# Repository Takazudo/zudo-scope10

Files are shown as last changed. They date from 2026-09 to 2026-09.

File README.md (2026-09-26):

# zudo-scope10 — P0 pre-layout handoff

Ten DC-coupled inputs, one portrait 3.5-inch LCD, ten TIME pots and ten RANGE switches.
All soldering is assigned to factory assembly. Pico H and Waveshare SKU 19907 are preassembled plug-in modules.

**This is the waveform-monitor project, not the LED lamp or the five-oscillator instrument.**

**NOT FOR FABRICATION.** The PCB contains only an outline. Native KiCad *placement/routing*, exact physical footprints, display power strap resolution, bench-measured acquisition/protection/power qualification, sourcing, assembly and release approval remain open — every one of the ten release gates (G01–G10) in `design/release-gates.json` stays OPEN, each with partial desk evidence.

Start with [START_HERE.md](START_HERE.md) for orientation, or go straight to **[LOCAL-HANDOFF.md](LOCAL-HANDOFF.md)** for the numbered local procedure covering every gate plus the assembler review and the factory-assembled prototype (no home soldering). The entry point `index.html` opens the offline catalogue and UI simulator. Run:

```sh
python3 scripts/validate.py
python3 scripts/test_firmware.py
python3 scripts/serve.py
```

Browse `http://127.0.0.1:8000/`.

| Directory | Purpose |
|---|---|
| `design/` | Requirements, circuit pin/net graph, GPIO, narratives, release gates |
| `hardware/kicad/` | Eleven generated native schematic drafts, netlist, outline-only PCB |
| `hardware/libraries/` | Embedded review symbol library and one drawing-derived button footprint |
| `catalog/` | Component and source evidence; unknown identities are explicit |
| `doc/` | zudo-doc configuration, generated MDX and public previews |
| `firmware/` | Host-tested portable core, diagnostic + 10 kS/s/ch acquisition targets, clean-room LCD backend — all build clean against the real Pico SDK (no hardware bring-up yet) |
| `reference/` | Retained original ALPS/button/jack assets with provenance |
| `mechanical/` | Ergonomic panel and nominal envelopes, not manufacturing CAD |
| `manufacturing/` | Planning BOM, RFQ, acceptance worksheet, blocking release guard |
| `reports/` | Reproducible analytical and validation reports, not bench measurements |

No Gerber or placement file is emitted. Do not order the outline-only board. No online repo, vendor account or purchase was modified.

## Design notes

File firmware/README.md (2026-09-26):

# Firmware status

The portable core is host-tested. `scope10_diagnostic` is target source for a slow USB CSV input/control diagnostic with the LCD held dark. It is **not the complete monitor firmware**. No high-rate acquisition guarantee or working LCD is claimed. A clean-room LCD backend and ten-pane renderer exist but are compiled only with `-DSCOPE_ENABLE_LCD=1` and are not hardware-verified; see `LCD-BACKEND.md` (G06 OPEN).

Run `python3 scripts/test_firmware.py` from the repository root for host tests. Use `PICO_SDK_PATH` and the CMake instructions in the documentation for local target compilation. The Waveshare backend behind `src/display_port.h` is a clean-room implementation because the vendor driver carries no licence (`LCD-BACKEND.md`); validate the module power/interface (G01) before enabling it.

Do not link an empty successful LCD stub, allocate a full RGB565 framebuffer, auto-zero connected inputs at boot, or suppress acquisition overruns.

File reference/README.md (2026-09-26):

# Source availability and rights

`catalog/sources.json` records current primary-source URLs and the nature of each review. Some PDFs were read through the web tool but could not be downloaded as bytes. The binary-fetch script is provided for local completion; it checks magic bytes and records hashes, but does not mark downloaded content electrically reviewed.

`assets/` contains existing manufacturer/supplier files recovered from the user's earlier component catalogue ZIP. Their records retain the original URLs and SHA-256 values. These third-party source assets are not licensed under the license for the newly written project code. Keep them for local engineering reference; review their respective terms before publishing download mirrors.

The ALPS STEP is original manufacturer geometry. No exact Waveshare/Pico or NKK STEP is included. The separately generated nominal envelopes are clearly different artifacts and do not replace missing exact CAD.

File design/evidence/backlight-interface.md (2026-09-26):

# GP13 backlight interface: open-drain stage, voltage table and alternatives (#41, source #19)

Status: **design applied, bench check pending**. G01 and G06 stay OPEN. Everything here is a desk analysis of the carrier netlist (`design/circuit.json`, generated by `scripts/make_design.py`), the Waveshare module schematic and the RP2040 datasheet. No node has been measured; the module revision and population have not been inspected.

## Problem being solved

The module's R16 (10 kΩ) runs from VSYS to `LCD_BL`, which is pin 3 (EN) of CAT1, the backlight regulator (Waveshare Pico-ResTouch-LCD-3.5 schematic p1, "LCD BACKLIGHT", grid 3A; re-read from the PDF at 300 dpi on 2026-09-26, SHA-256 `0547c5fd3dc4fce9e20941b756aa8e348ea47e4d24851e745a04a0c24a5f3b41`, same file as `display-sch` in `g01-display-power.md`). On the carrier VSYS is `+5V_FUSED`, i.e. USB 4.75–5.25 V less the F1 drop. Before #41 the carrier tied GP13 (through R64 33 Ω) directly to `LCD_BL` with R88 100 kΩ to GND, so an undriven GP13 sat near 4.5 V (about 3.85–4.08 V including the RP2040's 50–80 kΩ reset pull-down). That exceeds the RP2040 absolute maximum VPIN ≤ IOVDD + 0.5 V (RP2040 datasheet §5.5.3.1, Table 622) in every state where firmware does not drive the pin. The earlier G01 handoff options, "remove R88" and "accept an estimated < 0.1 mA clamp", are both rejected: removing R88 moves the unloaded node toward 5 V, and the fault-tolerant IO definition does not establish 5 V operation or a usable clamp (#19).

## Decision: N-channel open-drain stage on the carrier

Chosen over the alternatives below because it changes nothing on the module, needs no home soldering, is threshold-agnostic for "off", and keeps the GPIO pad inside its own supply rails by construction rather than by firmware timing.

```text
GP13 (J20-17, net LCD_BL_SRC) --R64 33R-- LCD_BL_GATE --+-- Q1 gate
                                                        |
                                                   R88 100k
                                                        |
                                                       GND
Q1 drain  -- LCD_BL (J30-17) -- module R16 10k -- VSYS ; -- CAT1 EN
Q1 source -- GND
```

- `Q1` is a new generic catalog record `nmos-ll` (logic-level N-channel MOSFET; no MPN, LCSC code or footprint; requirements listed on the record, exact part at G08).
- `R64` keeps its value and its GP13 side; its other side moves from `LCD_BL` to the new net `LCD_BL_GATE`.
- `R88` keeps its value and footprint and becomes the gate pull-down (`LCD_BL_GATE` → GND).
- `J30`/`J31` header nets are unchanged: position 17 is still `LCD_BL`. Module R16 remains the only pull-up on that node.
- `scripts/validate_extra.py` (`_gp13_backlight_interface`) asserts that GP13's net has no resistive DC path below 1 MΩ to `+5V_FUSED`, `VBUS_USB` or `LCD_BL`, that the GP13 and gate nets contain exactly the parts above, and that the display header map is unchanged.

### Default state and enable polarity (explicit)

| GP13 | Q1 | `LCD_BL` | Backlight |
|---|---|---|---|
| undriven (reset, BOOTSEL/ROM, before the firmware hook) | off (gate held at 0 V by R88) | VSYS via R16 | **ON** |
| driven low | off | VSYS via R16 | ON |
| driven high | on | ≈ 0 V | **OFF** |

The backlight is **default ON** and the GPIO control is **active-low** (GP13 high = off). Any future PWM dimming is inverted as well. Firmware is updated accordingly (`firmware/src/lcd_safe_pins.[ch]`, `firmware/src/display_waveshare.c`): `scope10_acq` drives GP13 high from its early runtime-init hook in both `SCOPE_ENABLE_LCD` states, and the LCD-enabled build drives it low only after a successful panel init. `scope10_diagnostic` does not link `lcd_safe_pins.c` and never drives GP13, so under the diagnostic firmware the backlight stays ON; the pad still sits at 0 V through R88.

## Voltage/current table

Conventions: IOVDD = 3.3 V nominal (Pico 3V3). "Pad" is the GP13 pad = net `LCD_BL_SRC`; "gate" is net `LCD_BL_GATE`; `LCD_BL` is the module node. V_OH/V_OL are the RP2040 output levels at IOVDD 3.3 V; the RP2040 reset pull-down is the 50–80 kΩ figure cited in #19. The Q1 numbers use the record's requirements (Igss ≤ 1 µA, Rds(on) ≤ 10 Ω at Vgs = 2.5 V); they become datasheet numbers only once a part is selected at G08. **No entry depends on any GPIO protection clamp or on the fault-tolerant IO definition.**

| State | Pad (GP13) | Gate | `LCD_BL` | Current into/out of pad | Backlight |
|---|---|---|---|---|---|
| USB 4.75 V, GP13 undriven | 0 V (R88 ‖ 50–80 kΩ to GND; Igss ≤ 1 µA × 100 kΩ ≤ 0.1 V worst case) | same as pad | 4.75 V − F1 drop (Q1 off; CAT1 EN input current unknown) | ≤ 1 µA (gate leakage only) | ON |
| USB 5.25 V, GP13 undriven | 0 V (as above) | same as pad | 5.25 V − F1 drop | ≤ 1 µA | ON |
| USB 4.75–5.25 V, GP13 driven low | V_OL ≈ 0 V | ≈ 0 V | VSYS via R16 | ≈ 0 (R88 draws nothing at 0 V) | ON |
| USB 4.75–5.25 V, GP13 driven high | V_OH ≤ IOVDD | V_OH − 33 Ω × (33 µA + Igss) ≈ V_OH | Rds(on) × (VSYS / 10 kΩ) ≤ 10 Ω × 0.53 mA ≈ 5 mV | 33 µA (R88) + Igss, sourced by the pad | OFF |
| Reset (RUN low or power-on reset) | 0 V (reset pull-down 50–80 kΩ plus R88, both to GND) | 0 V | VSYS via R16 | ≤ 1 µA | ON |
| BOOTSEL / boot ROM | expected 0 V (pad left in its reset state); if the ROM ever drove GP13 it could only reach V_OH ≤ IOVDD | follows pad | VSYS via R16 (or ≈ 0 V if driven high) | ≤ 1 µA (or 33 µA) | expected ON; confirm on bench |
| Pico IOVDD not yet up, module VSYS present (power-up ramp; no supported configuration has the module powered with the Pico unpowered, because both take 5 V from the Pico's VBUS pin) | 0 V — the pad is tied only to R88/gate, so VPIN ≤ IOVDD + 0.5 V holds even at IOVDD = 0 | 0 V | VSYS via R16 as soon as VSYS rises | ≈ 0 | ON as soon as CAT1 starts |
| Module absent or its VSYS not present, Pico powered | as in the corresponding driven/undriven row (the pad never depends on the module) | follows pad | floating at Q1's drain (no R16); harmless | ≈ 0 | n/a |

Summary: in every row the pad lies between 0 V and V_OH ≤ IOVDD, so VPIN ≤ IOVDD + 0.5 V and VPIN ≥ −0.5 V are met across USB 4.75–5.25 V, reset, BOOTSEL, both power-sequencing orders and normal operation. The only currents at the pad are the 33 µA R88 load while driven high and the gate leakage; no clamp conducts. Q1's drain sees at most 5.25 V and switches at most ≈ 0.53 mA (VSYS / R16), so a ≥ 20 V, ≥ 10 mA part is ample.

### What the table does not establish

- **CAT1 EN thresholds:** CAT1's part number is not printed on the schematic (text extraction of the PDF gives only "CAT1" with pins VIN/GND/EN/BYP/VOUT), so its V_IH/V_IL are **unknown** (`design/evidence/module-power.json`, `backlight-regulator-en-thresholds`). "Off" relies only on `LCD_BL` being held at a few millivolts, which any enable input treats as low; "on" relies on the module's own R16 arrangement, exactly as when a Pico is stacked on the module. Neither depends on the threshold value.
- **CAT1 EN input current:** unknown; it only affects how close `LCD_BL` sits to VSYS while off, not the pad.
- **The F1 drop and the pre-hook lit interval:** unmeasured.
- **Module revision/population:** R16 = 10 kΩ fitted and CAT1 present are schematic facts, not inspected facts.

## Alternatives weighed

| Option | Default | Why not chosen |
|---|---|---|
| **Factory modification of the module** (remove/replace R16, add a 3.3 V-referenced pull-up) plus a direct GP13 drive | could be OFF | Requires a documented rework of a purchased module by a contracted assembler; every module unit becomes a custom part with a revision-dependent procedure, and the pull-up source on the module (its 3V3 rail) comes up after VSYS through U7. It meets the no-home-soldering rule only if the assembler performs it, and it adds a G01 inspection item per unit. Kept as a fallback if the bench shows CAT1 does not accept the open-drain drive. |
| **Level-translating buffer** (e.g. a 5 V-supplied open-drain buffer or a dedicated translator) | OFF or ON by configuration | Adds a supplied IC and its 5 V decoupling for one signal; its input still has to be protected or supplied from IOVDD; more parts than a MOSFET with no functional gain. |
| **P-channel high-side / default-OFF variants** | OFF | A P-channel device in series with R16's pull-up cannot be inserted without modifying the module (R16 is on the module). A carrier-side default-OFF would need a pull-down strong enough to defeat R16 (a few kΩ, wasting ~1 mA and still a 5 V node) or a supplied logic stage; it also changes the power-state story (backlight current absent before firmware runs). Rejected for P0: default ON matches the vendor's stacked behaviour and the power contract already assumes an unconditional load. |
| **Keep the direct connection, remove R88** | ON | Node approaches 5 V; still violates IOVDD + 0.5 V. Rejected (#19). |
| **Keep the direct connection, accept a clamp current** | ON | Depends on an undocumented clamp; rejected (#19). |

## Changes made in this pass

- `scripts/make_design.py`: R64 → `LCD_BL_GATE`, R88 → gate pull-down, new `Q1` (`nmos-ll`), `pending_g01_changes[id=g01-r88-backlight-default]` status `DESIGN_APPLIED_BENCH_CHECK_PENDING`; regenerated schematics, netlist, BOM, connections, `design/circuit.json`.
- `catalog/components.json`: `nmos-ll` record (generic, no MPN/C-number, footprint unassigned, sourcing at G08).
- `scripts/validate_extra.py`: `_gp13_backlight_interface` check.
- Firmware: inverted GP13 levels (`LCD_BL_LEVEL_OFF`/`_ON`), early hook drives GP13 high, `scope_display_backlight()` inverted; `firmware/LCD-BACKEND.md`.
- `design/power-contract.json` (`backlight` fields per power state), `design/evidence/module-power.json` (`backlight-regulator-en-thresholds`), `design/narrative-pages.json` power page, `design/release-gates.json` G01/G06 notes, `LOCAL-HANDOFF.md` G01/G06, `manufacturing/acceptance-results.csv` (`BACKLIGHT_GP13_INTERFACE`, NOT_RUN).

## Bench items before G01/G06 closure (assembler/bench provider, factory-assembled prototype only)

1. Confirm the received module's revision and that R16 (10 kΩ) and CAT1 are populated as drawn; read CAT1's marking if legible and record its EN thresholds from its datasheet, or record them as still unknown.
2. From power-on, capture GP13 (`LCD_BL_SRC`), `LCD_BL_GATE` and `LCD_BL` (J30 position 17) at the lowest and highest USB voltage available within 4.75–5.25 V, through reset (RUN button), BOOTSEL and normal boot of the LCD-off and LCD-on builds. Pass criteria: GP13 and the gate stay within 0 V … IOVDD in every capture; `LCD_BL` sits at VSYS while the backlight is lit and below 50 mV while it is dark; the backlight is dark after the early hook and lit again only after `lcd,init_sequence_sent`.
3. Record the lit interval from power-on to the hook.

Nothing above is a measurement; the acceptance row stays `NOT_RUN` until the provider fills it.

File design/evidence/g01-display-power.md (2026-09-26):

# G01 desk evidence: Waveshare Pico-ResTouch-LCD-3.5 power path and straps

Status: **evidence_partial**. G01 stays OPEN. This is a desk reading of the manufacturer schematic, and nothing here comes from a physical module. Fitted parts, the strap population and the module revision still need a check on the received board.

## Sources read

| ID | Source | Retrieved (UTC) | SHA-256 |
|---|---|---|---|
| display-sch | `https://files.waveshare.com/upload/8/85/Pico-ResTouch-LCD-3.5_Sch.pdf` (2 pages, A4 landscape, PDF modDate 2021-05-14, no revision field) | 2026-09-26T09:58Z | `0547c5fd3dc4fce9e20941b756aa8e348ea47e4d24851e745a04a0c24a5f3b41` |
| display-code | `https://files.waveshare.com/upload/f/fc/Pico-ResTouch-LCD-X_X_Code.zip` (`C/lib/config/DEV_Config.h`) | 2026-09-26T09:58Z | `a489c0b03b274ede3eef5f6470d960da6aba4500f55522c5ac1068ed3f95779a` |
| display-wiki | `https://www.waveshare.com/wiki/Pico-ResTouch-LCD-3.5` (HTML; pin table and FAQ) | 2026-09-26 | `9b7bb24fb1f4db522e2bb0b26380a59b5aec8f70f4a3c30e95eec0210080877b` |
| pico-ds | `https://datasheets.raspberrypi.com/pico/pico-datasheet.pdf` | 2026-09-26T09:58Z | `757ff485227493b9fcc0c2c96c4dea9de020e1d8b2b11e2aa4f9ee8b25aa89eb` |
| rp2040-ds | `https://datasheets.raspberrypi.com/rp2040/rp2040-datasheet.pdf` | 2026-09-26 | `be56fbb75ba0ae9e26558a73c93ac3e75c2ad4e6878d3b6703de2a76d886ea8c` |
| rt9193-ds | `https://www.richtek.com/assets/product_file/RT9193/DS9193-18.pdf` (DS9193-18, June 2022) | 2026-09-26 | `600a0eef69bc2c3827f668e3b71d83b746738ee1bf7484f86483a7ca51686b8f` |

Each schematic page was rendered to PNG with PyMuPDF (MuPDF 1.28.2) at 200 dpi, and the areas that mattered were rendered again at 400–800 dpi. I read the images directly. The PNGs are **not committed**, because Waveshare's download terms do not clearly allow redistribution. They can be regenerated from the PDF above into the gitignored `reference/downloads/`.

Citation format: `Sch p1 <col><row>` uses the schematic frame grid (columns 1–4, rows A–D). The section titles are the ones printed on the sheet.

## Answers

### 5 V enters on VSYS (position 39); no diode or regulator at the entry

- The module's Pico footprint U5, position 39, carries net `VSYS` (Sch p1 2B–3C, "Pi pico (40P)"). The module uses `VSYS` for two things only: the input of U7 (RT9193-33, 3V3 LDO; Sch p1 4D "Power") and the input of CAT1 (backlight regulator; Sch p1 3A "LCD BACKLIGHT").
- The entry has **no diode, fuse or switch** on the module. VSYS goes straight to C10 1 µF, C9 10 µF, C14 100 nF, C15 100 nF and the regulator VIN pins (Sch p1 3A, 4D).
- Position 40 carries a net label `VBUS` drawn in the green style that this sheet uses for header-only labels. No other `VBUS` label appears anywhere on either page, so the module draws **nothing from VBUS** (Sch p1 3B).
- The wiki pin table agrees: "VCC — VSYS — Power input", with "Operating voltage: 5V".
- When stacked the way Waveshare intends, the Pico's own VSYS supplies the module. That VSYS is USB VBUS after the Pico's D1 Schottky (pico-ds §4.4–4.5, PDF p21). The carrier instead feeds display position 39 from `+5V_FUSED` = Pico VBUS (J21-1, position 40) → F1. The module therefore sees about one Schottky drop *more* than it would when stacked. USB VBUS nominally stays within RT9193's recommended VIN of 2.5–5.5 V (rt9193-ds p3, 6 V absolute maximum).

### Regulator and straps: 3V3 is generated on the module; no contention under the carrier wiring

- **U7 RT9193-33** (Sch p1 4D): pin 1 VIN = VSYS, pin 2 GND, pin 3 EN = `VCC_EN`, pin 4 BP = C12 22 nF, pin 5 VOUT = module `3V3` with C11 1 µF. RT9193 is a 300 mA LDO with 220 mV typical dropout at 300 mA (rt9193-ds p1, p3).
- **Enable straps** (Sch p1 4D, lower half), with values as printed on the schematic:
  - R11 **0R**, from `VSYS` to `VCC_EN` (fitted per schematic: EN follows VSYS)
  - R12 **NC**, from `3V3_EN` (position 37) to `VCC_EN`
  - R14 **NC**, from `GPIO14` (position 19) to `VCC_EN`
  - R13 **100K**, from `VCC_EN` to GND
- **3V3 source strap:** R15 **NC**, from `Pico3V3` (position 36) to module `3V3`. With R15 not fitted, the module's `3V3` rail (74HC4040/4094/04, XPT2046, TF slot, PSRAM, LCD FPC pins 6/7/12) comes **only from U7**. It is not taken from the Pico header.
- Page 2 (board silkscreen, mirrored) shows these straps grouped under the labels "VSYS / 3V3 / GP14" next to R11–R15 (Sch p2, upper centre). The schematic values are design intent only. Which parts are actually fitted is **UNRESOLVED** until the physical module is checked.
- **Contention verdict: none under the carrier's proposed wiring, whichever strap variant is fitted.** J31 leaves positions 36 (`Pico3V3`) and 37 (`3V3_EN`) unconnected, and J30 leaves position 19 (`GPIO14`) unconnected. Even if R15, R12 or R14 were fitted, none of them could tie U7's output or its EN to the Pico's 3V3 or 3V3_EN.
  - If R12 or R14 were fitted *together with* R11 0R, a directly stacked Pico would have VSYS tied to its 3V3_EN, or to GP14. The carrier's isolation of those positions prevents that.
- **Failure mode the carrier creates:** a module strapped with R11 removed and only R12 or R14 fitted would have EN held low by R13 on the carrier, because positions 37 and 19 are open. The module 3V3 would never start and the display would stay blank. The physical check must confirm R11 is fitted.

### Other supply pins: 3V3_EN and ADC_VREF

- **3V3_EN (position 37):** reaches the module only through R12 (NC) to `VCC_EN` (Sch p1 4D). With R12 not fitted, the module does not use it. It is safe to leave open on the carrier.
- **ADC_VREF (position 35):** header-only green label. No other `ADC_VREF` label appears on either page, so the module does not use it (Sch p1 3B).
- **3V3 (position 36):** net `Pico3V3`. It reaches the module only through R15 (NC) (Sch p1 4D).
- **VBUS (position 40):** not used (see the 5 V entry above).
- The Pico datasheet confirms what these pins are on the Pico side: 3V3_EN is pulled up to VSYS through 100 kΩ, and ADC_VREF is the filtered 3.3 V (pico-ds PDF p9).

### Spare-position nets: conflicts on GP2, GP5 and GP14 are all avoided because those positions are open

The carrier uses GP2–GP5 for the mux address and GP14 for the timing test point. Module net on each display position (Sch p1 2B–3C, U5), and what the carrier's J30/J31 does with it:

| Pos | GPIO | Module net | Module use | Carrier (J30/J31) | Conflict if connected |
|---|---|---|---|---|---|
| 1, 2 | GP0, GP1 | GPIO0/1 (green) | none | open | — |
| 4 | **GP2** | **SRAM_CS** | U8 ESP-PSRAM64H CE, R20 10K pull-up to module 3V3 (Sch p1 3D) | open | **Yes.** Mux ADDR0 would select the PSRAM, which then drives the shared MISO (U8 SIO1 = `MISO`, GP12) during LCD/touch/SD transfers. With position 4 open, R20 keeps the PSRAM deselected. |
| 5 | **GP3** | GPIO3 (green) | none | open | none found |
| 6 | GP4 | GPIO4 (green) | none | open | none found |
| 7 | **GP5** | **SDIO_CLK** | H6 pin 1, a 3-way solder jumper selecting the TF-card clock between SDIO_CLK and SCLK (Sch p1 2D–3D; silkscreen legend "A SPI / B SDIO", Sch p2 right) | open | **Strap-dependent.** In the SDIO jumper position, mux ADDR3 would clock the TF card. In the SPI position it has no load. |
| 9, 10 | GP6, GP7 | GPIO6/7 (green) | none | open | none found (carrier GP7 = MUX_DISABLE stays Pico-only) |
| 17 | GP13 | LCD_BL | CAT1 EN, **R16 10K pull-up to VSYS** (Sch p1 3A) | connected to the Q1 open-drain stage only; GP13 drives the Q1 gate through R64 33 Ω with R88 100k gate pull-down (#41) | see the backlight finding below and `backlight-interface.md` |
| 19 | **GP14** | **GPIO14** | R14 (NC) to `VCC_EN` (Sch p1 4D) | open | **Strap-dependent.** With R14 and R11 both fitted, GP14 would be tied to VSYS (5 V). With R14 NC it has no load. |
| 22 | GP17 | TP_IRQ | XPT2046 PENIRQ, R2 100K pull-up to 3V3 (Sch p1 1B–2C) | open | none. Touch firmware must poll, because the IRQ is not routed. |
| 24–27 | GP18–21 | SDIO_CMD/D0/D1/D2 | H1/H2/H3/H5 jumpers (Sch p1 2D–3D) | open | none. In the SDIO jumper position the TF card would be unusable on the carrier. |
| 29 | GP22 | SDIO_D3/SD_CS | TF slot CD/D3 | SD_CS_N | intended |
| 30 | RUN | RUN | K1 push button to GND (Sch p1 3B) | open | none. The module's reset button does nothing on the carrier. |
| 31, 32, 34 | GP26–28 | GPIO26/27/28 (green) | none | open | none (carrier ADC inputs stay Pico-only) |

Two further observations:

- The vendor C driver (`DEV_Config.h`) uses GP8 DC, GP9 CS, GP10 CLK, GP11 MOSI, GP12 MISO, GP13 BL, GP15 RST, GP16 TP_CS, GP17 TP_IRQ and GP22 SD_CS on `spi1`. It never references GP2, GP5 or GP14, and it matches the carrier's signal contract.
- The wiki pin table lists SDIO_CLK = GP5 but does not mention SRAM_CS/GP2 or the GP14 strap. **The schematic, not the wiki, is the authority for those.**

### Backlight pull-up to VSYS defeats the carrier pull-down on LCD_BL (GP13)

R16 10K runs from `VSYS` to `LCD_BL`, which is the CAT1 EN pin (Sch p1 3A, confirmed on an 800 dpi crop). On the carrier, `VSYS` = `+5V_FUSED`, and `LCD_BL` also carries R88 100k to GND. Whenever GP13 is high-impedance (reset, boot ROM, before firmware drives the pin):

- The node settles near 5 V × 100k / 110k ≈ 4.5 V. That is above RP2040's absolute maximum pin voltage of IOVDD + 0.5 V (rp2040-ds §5.5.3.1, Table 622, PDF p615). The pin's protection structure conducts at roughly (4.5 V − ~3.8 V) / 9.1 kΩ, which is below 0.1 mA. This is an estimate, not a measurement.
- The backlight is **on** by default, not off. The carrier doc's statement "LCD backlight has a pull-down" does not give a backlight-off default with this module.

The same R16-to-VSYS arrangement exists when the Pico is stacked on the module as Waveshare intends, so this is vendor design behaviour, not a carrier error.

**Superseded by #41 (source #19):** the paragraph above describes the carrier as it was when this evidence was written. The carrier now drives the gate of an N-channel open-drain MOSFET (Q1) from GP13 instead of tying GP13 to `LCD_BL`; R88 is the gate pull-down and the header net `LCD_BL` (J30 position 17) is unchanged. The GPIO pad no longer sees the R16 node in any state, and the clamp estimate above is no longer part of any argument. Default state (backlight ON) and polarity (GP13 high = OFF) plus the per-state voltage/current table are in `design/evidence/backlight-interface.md`. The bench check of the real module population and the `LCD_BL`/gate waveforms remains a G01/G06 item.

### Current and inrush figures for G07

- **Module maximum: REJECTED, not a citable figure.** "5V 180mA" was reported by an earlier automated fetch summary of a wiki FAQ image; both FAQ images at that URL were downloaded and visually inspected in a later pass and show unrelated file-browser screenshots, not a power spec, and no textual mA/current figure was found on either wiki page. This claim is rejected, not carried as a manufacturer maximum. See `design/evidence/module-power.json` (`module-max-current-180ma`, status `rejected`) — that file is the single source of truth for this claim so `scripts/power_budget.py` and this document cannot disagree. The carrier's 300 mA planning allowance (`display-planning-allowance`, status `allowance`) is independent of the rejected claim.
- **Module 3V3 rail:** RT9193 limit of 300 mA (rt9193-ds p1).
- **Backlight:** CAT1 (5-pin regulator: VIN, GND, EN, BYP, VOUT) feeds `LED-A` (FPC pin 33). The three LED cathode returns, FPC pins 34/35/36, each go to GND through R17/R18/R19 **2R** (Sch p1 3A, 4A–C "LCD"). Recorded structurally in `design/evidence/module-power.json` (`backlight-topology`, status `verified-schematic`).
  - **UNRESOLVED:** CAT1's part number and output voltage are not printed, and the LED forward voltage is unknown. The backlight current cannot be derived from the schematic.
- **Bulk capacitance on VSYS (inrush-relevant):** C9 10 µF + C10 1 µF + C14 100 nF + C15 100 nF ≈ **11.2 µF** (Sch p1 3A, 4D). Recorded in `design/evidence/module-power.json` (`module-vsys-capacitance`, status `verified-schematic`); combined with carrier C30 (1 µF, on `+5V_FUSED`) that gives a **12.2 µF** known carrier+module nominal subtotal (`carrier-plus-module-known-subtotal`) — a known-figure subtotal against the informal ≤10 µF inrush guidance, not a claim of measured inrush compliance. Pico-side bulk capacitance is still unknown, so overall inrush status stays UNKNOWN and G07 stays OPEN.
- **Other module capacitors:**
  - On 3V3: C11 1 µF plus 100 nF decouplers C1, C2, C7, C8, C18, C19, C20, C21.
  - On LED-A: C17 100 nF.
  - C16 100 nF on CAT1's BYP pin, C12 22 nF on U7's BP pin.
  - Capacitance inside the LCD panel FPC is not shown and is **UNRESOLVED**.

### Pico VBUS→VSYS cross-check: the proposal stays within limits

- Pico VBUS is the micro-USB 5 V. VSYS = VBUS − D1 Schottky drop, with an allowed range of 1.8–5.5 V (pico-ds PDF p9, p12, p21).
- The carrier leaves Pico VSYS (J21-2, position 39) unconnected and takes `VBUS_USB` from Pico position 40 (J21-1). Display current therefore flows through the Pico's micro-USB connector and VBUS trace but **not** through D1. Nothing on the display side can back-feed Pico VSYS.
- The display's position 39 is a separate net on the carrier. The limit that applies to it is RT9193's VIN (≤ 5.5 V recommended, 6 V absolute maximum), which USB 5 V meets. CAT1's input limit is unknown, because its part is unidentified.
- The current rating of the Pico's VBUS pin and trace for the added display load is not stated in pico-ds. It remains a G07 item.

## Verdict: keep the current netlist proposal

Keep position 39 fed from `+5V_FUSED`, and keep positions 35, 36, 37 and 40 isolated. Also keep positions 4, 7, 19, 22, 24–27 and 30 open: the schematic shows that each one either conflicts with the carrier's use of the same GPIO or depends on a strap. `design/evidence/g01-delta.json` proposes no net or pin edits. It proposes documentation notes and one flagged review decision (R88 / LCD_BL).

## Open questions only the physical module can answer

1. Module revision marking: silkscreen or label version, and whether it matches this 2021-05-14 schematic.
2. Fitted straps: R11 = 0R fitted; R12, R14, R15 not fitted; R13 = 100K.
3. Position of solder jumpers H1–H6, SPI (A) versus SDIO (B). The carrier needs SPI.
4. Whether U8 (PSRAM) is fitted, and the R20 value.
5. CAT1 part marking, which gives the backlight regulator identity, output voltage and EN thresholds, and from those the backlight current (`module-power.json` `backlight-regulator-identity`, `backlight-regulator-en-thresholds`).
8. (#41) GP13, `LCD_BL_GATE` and `LCD_BL` waveforms from power-on through reset, BOOTSEL and normal boot, plus R16/CAT1 population, per `backlight-interface.md`.
6. Which SD pull-up option is fitted: R6/R10 "NC/10K", R7/R8/R9 "4K7/NC".
7. Measured VSYS current at power-up and in steady state (bench, G07). No figure here is a measurement.

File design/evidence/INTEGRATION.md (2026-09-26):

# Generator integration (#13): applied evidence deltas, candidate footprints

Applies the deltas written by #3 (`g01-delta.json`), #6 (`g02-delta.json`) and #9
(`g08-delta.json`) to `scripts/make_design.py` and `catalog/*.json`. This is the only
topic that edits those files (epic #1 file-ownership rules); #4/#11 already own the
ERC-clean generator and ran before this topic.

## Summary

**24 of 30 records have a candidate footprint with citation; the rest are OPEN with reason** (see table below). `footprint_qualified` is `false` on every record (unchanged) and no footprint was placed on `.kicad_pcb`, which stays outline-only.

All checks pass after regeneration: `validate.py` (72/72 checks, 224 instances / 134 nets — unchanged from before this topic), `scripts/kicad_check.py` (root ERC 0 unexplained, PCB DRC 0 errors, netlist parity PASS with 0 differences), `test_firmware.py` and `analyze.py`.

G01, G02 and G08 all stay OPEN. No J30/J31 header net was changed.

## Footprint coverage (acceptance line detail)

| Record | Footprint candidate | Reason if OPEN |
|---|---|---|
| tlv9064, mux, ldo, ref, clamp | assigned (verified SOIC-14 / TSSOP-24 / SOT-23-5 / SOT-23-3 / SOT-23 packages) | — |
| button | assigned (`ZudoScope10:SW_XUNPU_TS1088_AR02016_REVIEW`, pad-for-pad per drawing) | — |
| socket20, header20 | assigned (1x20, 2.54 mm, by pitch/count per pico-h/display pin maps) | mechanical stack (mating length, insulator height) stays OPEN |
| r1m…c10u, testpoint (SMD passives) | assigned (0603/0805 per value) | — |
| range | **OPEN** | G02 (#6) resolved the numeric terminal map (C->3, M->2 vendor facts; L->1/H->4 OPEN pending layout orientation) but explicitly left pad geometry/drawn footprint unresolved ("still needs a drawn footprint and real-part fit check") |
| jack | **OPEN** | G02 (#6): 5 physical legs vs 3 logical contacts; leg-to-node map unresolved (drawing table internally inconsistent, third-party footprint contradicts the manufacturer drawing) |
| pot | **OPEN** | unchanged from before this topic: no delta resolves an exact footprint; open question already asks to verify physical terminals first |
| fuse | **OPEN** | G08 (#9) gave a candidate MPN/JLC code (exact spec match, no margin) but no footprint evidence was supplied; still `SPECIFICATION_ONLY` |
| pico-h, display | **OPEN** | external plug-in modules, not placed on the carrier PCB itself (their carrier-side footprints are `socket20`/`header20`, which are assigned) |

## G01 — pending proposal only, header nets unchanged

Per the G01 header-net rule, no J30/J31 net assignment was changed in `scripts/make_design.py` or `design/circuit.json`. The three `g01-delta.json` entries were applied as follows:

| g01-delta entry | Applied as | Citation |
|---|---|---|
| `set_notes` on `parts[ref=J30].notes` | Applied verbatim to J30's generator note (no net change) | Waveshare schematic p1, U5 header / jumpers H1-H6 / Power R11-R15 / LCD BACKLIGHT R16 |
| `set_notes` on `parts[ref=J31].notes` | Applied verbatim to J31's generator note (no net change) | Waveshare schematic p1, Power block U7 RT9193-33 / U5 pos 35-40 |
| `review_decision` on `parts[ref=R88]` | Recorded as `pending_g01_changes` entry `g01-r88-backlight-default` in `design/circuit.json` metadata, **not applied** to R88's value/net; also written up in the power MDX narrative source (`design/narrative-pages.json` → `architecture/power-and-module-interface.mdx`) | Waveshare schematic p1 LCD BACKLIGHT (3A) R16 10K VSYS->LCD_BL/CAT1 EN; RP2040 datasheet §5.5.3.1 Table 622 (PDF p615) |

Extra finding recorded per manager instruction: module R16 (10k, VSYS→LCD_BL) overrides the carrier's R88 (100k, LCD_BL→GND) — the backlight defaults **on**, not off, and the node (~4.5 V) exceeds the RP2040 GPIO absolute maximum (IOVDD+0.5 V) by a small, unmeasured margin. No component value was changed; this is a decision for G01/G06 after the physical module check (see `LOCAL-HANDOFF.md`, #16).

*Update (#41, source #19):* that decision was taken as a design change, not a measurement: GP13 now drives a carrier-side open-drain N-MOSFET (Q1) whose drain is `LCD_BL`, with R88 repurposed as the gate pull-down; the J30/J31 header nets are still unchanged. See `design/evidence/backlight-interface.md`.

`validate.py`'s hard-coded pin-39/GP3/GP5/GP14 checks keep passing unchanged (unaffected by this topic).

## G02 — pin maps and facts added to the catalog

All 14 `g02-delta.json` change entries carry a citation and were applied:

| Target | Applied as |
|---|---|
| `records[id=range].pins` | Catalog pins replaced with numeric terminals `1`/`2`/`3`/`4` (was logical `C`/`L`/`M`/`H`) |
| `parts[record=range]` remap | `scripts/make_design.py`'s `add()` calls for `SW1..SW10` now emit numeric pins via a `RANGE_PIN` map (`C:3, M:2, L:1, H:4`); net graph unchanged (same nets, new pin keys) |
| `records[id=range].facts` / `.open_questions` | Vendor-fact terminal spacing/body/actuator dimensions added; L/H direction marked explicitly OPEN pending layout orientation |
| `records[id=jack].facts` / `.open_questions` | Slot/post/body dimensions and the leg-to-node inconsistency added |
| `parts[record=jack].notes` (`keep_open`) | Already satisfied — the generator's existing jack note text matches the delta's value verbatim; no generator change needed |
| `records[id=button].facts` / `.open_questions` | Variant-code, terminal and pad dimensions added; open questions narrowed to real-part fit only |
| `records[id=display].facts` / `.open_questions` | STEP-derived outline, mounting-hole pitch, socket-row and active-area dimensions added; open questions narrowed (STEP is no longer missing) |
| `records[id=pico-h].facts` / `.open_questions` | Board/hole dimensions and physical pin-1 numbering added; header-height gap noted as still open |
| `records[id=header20].facts` | Mating-length ceiling and display-underside offset added |
| `records[id=socket20].facts` | Pico H clearance inequality added |

## G08 — mpn/jlc_code applied only where cited

`known_listings_recheck` entries (`tlv9064`, `mux`, `ldo`, `clamp`, `range`, `pot`) already had an `mpn`/`jlc_code`; #9 only re-confirmed stock, so no catalog change was needed for these six.

`specification_only_candidates` — applied `mpn`/`jlc_code` (plus a fact citing the LCSC URL, `date_checked` and `listing_not_allocation: true`) for every entry that had a source URL and a checked date; skipped the three with no located citation:

| catalog_id | Result | Note |
|---|---|---|
| r1m, r200k, r4k7, r10k, r100k, r100, r1k, r33, c10n, c1n, c100n | **Applied** | meets_spec: true |
| c470p | **Applied, flagged** | candidate's tolerance (±10%) is looser than the design's 5% max — recorded as an explicit open question, not silently accepted |
| c1u | **Applied, flagged** | nominal/dielectric/voltage confirmed; DC-bias derating not checked |
| c10u | **Applied, flagged** | not wired to any BOM reference; derating not checked |
| fuse | **Applied, flagged** | exact spec match, zero margin above the stated minimums |
| ref | **Applied** | `jlc_code` was previously `null`; set to `C140329` (exact MPN match confirmed by fetch) |
| r249k | **Skipped** | no LCSC/JLC page found or fetched for this value; catalog left `null` |
| socket20, header20 | **Skipped** | only 2x20 dual-row parts were found; no 1x20 single-row page fetched, and mating height is undefined regardless |

`identity_state`/`fit_state` were left unchanged for every G08 record (still `SPECIFICATION_ONLY` / `PROPOSED_NOT_ASSEMBLED`); `factory_order_approved` stays `false` everywhere, matching the AGENTS.md invariant that a listing is not an order.

## Other integrator-owned fixes

- `scripts/fetch_sources.py` now downloads into the gitignored `reference/downloads/` (was the tracked `reference/downloaded/`) and writes its local fetch log to `reference/downloads/source-fetch-local.json` (was the tracked `reports/source-fetch-local.json`).

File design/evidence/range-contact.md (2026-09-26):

# RANGE switch (NKK SS14MDP2) contact-suitability evidence and qualification plan (#27, #38)

Status: **OPEN_REQUIRES_MANUFACTURER_CONFIRMATION_AND_QUALIFICATION**. This is a desk-evidence
record and a qualification plan, not a bench result. No contact-resistance measurement, cycling
run or environmental test has been performed. G02/G08 stay OPEN. Nothing here marks a bench or
aging result as PASS.

## Decision (#27 option 2, applied 2026-09-26)

Keep the already-selected NKK `SS14MDP2` (`catalog/components.json` record `range`). Do not invent
a substitute MPN, sourcing code, pin map or footprint. Require specific manufacturer confirmation
plus application-level qualification before the switch is approved for this exact circuit. A
maintained, break-before-make SP3T with manufacturer-supported dry-circuit (e.g. gold) contacts
remains a listed **OPEN alternative**, never a decision here -- any real substitute would need its
own exact pin map, footprint, actuator-height and factory-process review, none of which is done.

## 1. Contact material is silver, not gold

The NKK SS14MDP2 product page's General Specifications table states:

> Contact Finish: Silver Plating

Source: `range-contact-finish` (`catalog/sources.json`), re-fetched 2026-09-26.
<https://www.nkkswitches.eu/products/Slides/Slides%20SS/SS14MDP2/>

The switch's own ordering code confirms the same fact independently: `D`-`P`-**`2`** where NKK's
ordering chart (already recorded in `design/evidence/g02-mechanical-pins.md` §1, NKK H46) defines
option `2` as "Silver, 0.1 A @ 30 V DC".

## 2. Manufacturer dry-circuit guidance (NKK page Z33 / operating-range page)

NKK's Electrical Ratings document, printed page **Z33** ("Operating Range" section), states:

> Three contact materials are commonly used in NKK switches: gold, silver, and gold over silver.
>
> **Low Level ~ 0.4VA maximum @ 28V AC or DC maximum** -- Gold plated contacts are recommended for
> dry circuits, which are defined as very low energy. In circuits where the voltage is below 28
> volts DC and current is below 100 milliamps (dry circuits), no arc develops as the contacts open
> or close. So, the tarnish remains. Eventually without the arc, the contacts become so encrusted
> that the switch is unable to close the circuit due to the high contact resistance. The solution
> to this is plating the contacts with gold, which does not tarnish, thus assuring the full
> electrical life of the switch.
>
> **Power Level ~ 100mA to 10 amps @ 125V AC** -- Silver contacts are recommended for electrical
> levels above 0.4VA. Although silver tarnishes, it is a good conductor and this electrical energy
> is sufficient to break through the tarnish to give reliable performance. ... In circuits where
> the voltage is above about 12 volts DC and the current above .5 amps, an arc develops during
> opening or closing of the contacts. This arc keeps the oxidation cleaned off.

Source: `range-z33` (`catalog/sources.json`), fetched and read 2026-09-26. Retrieved as
`https://www.nkkswitches.eu/documents/products/support/electricalratings.pdf` (PDF page 3 of the
document, printed page Z33 in the NKK "Z Supplement"). The companion operating-range engineering
page restates the identical gold-for-dry-circuit recommendation (source `range-operating-range`,
`https://www.nkkswitches.eu/engineering/electrical.html`).

**Reading against this circuit:** the mechanism NKK describes for silver contacts to remain
reliable is arcing above roughly 12 VDC / 0.5 A, which cleans tarnish off the contact surface. This
sense circuit runs at 3.3 V logic level and never sustains current at all (see §3), so it never
produces the arc that silver contacts here would depend on. That places this application inside
NKK's own "Low Level ~ dry circuit" description, the case the manufacturer says gold contacts are
for -- not a confirmation that this specific part fails, but the specific, cited reason the
generic "approve signal-level switching" note in the catalog is replaced by an open qualification
requirement instead of a pass.

## 3. Steady and transient contact loads (this circuit, not a generic rating)

Actual sense path per `scripts/make_design.py` (~lines 47-49), one instance per channel (`SWn`
COMMON -> `Rn+2` (1 kOhm) -> `Cn+2` (100 nF) -> mux input `RANGE`):

```text
Initial capacitor current, full 0 <-> 3.3 V throw:  3.3 V / 1 kOhm = 3.3 mA
RC time constant:                                    1 kOhm x 100 nF = 100 us
```

- The 3.3 mA figure is the *initial*, instantaneous transient at the moment of a full-swing throw
  (e.g. GND throw to the +3V3A throw). It decays exponentially with tau = 100 us toward the
  steady-state current, which is leakage/input-bias current into the downstream mux/buffer --
  on the order of nanoamps to low microamps for a CMOS mux/op-amp input, not milliamps.
- The centre throw (`THROW_CENTER` / `RANGE_MID`) is fed by the R40/R41 10 kOhm/10 kOhm divider
  (`scripts/make_design.py`), adding roughly 5 kOhm of source impedance on that throw; this
  lowers the available transient current further, it does not add a continuous load.
- **There is no continuous wetting current.** Once the RC transient settles (a few hundred
  microseconds after a throw), the switch contact carries only the mux/buffer's leakage/bias
  current until the next throw.
- The manufacturer's **100 mA / 30 V rating is a maximum electrical rating**, i.e. an upper bound
  on what the switch can survive. It says nothing about performance in a circuit that runs at a
  small fraction of a milliamp in steady state and a single-digit-milliamp transient once per
  throw -- the low-energy regime NKK's own dry-circuit guidance addresses separately from the
  maximum rating.

## 4. What is NOT concluded here

- This is not a finding that SS14MDP2 will fail in service. It is an evidence-based reliability
  qualification risk (per #27's classification), not an observed field failure or proof every
  sample fails.
- No substitution is made. The part, pin map, footprint and factory-process assumptions in
  `catalog/components.json` and `scripts/make_design.py` are unchanged by this record.
- No bench, cycling, or environmental result exists yet. Every check below is a plan, not a
  measurement.

## 5. Qualification plan (concrete, not yet executed)

1. **Manufacturer confirmation.** Request NKK's written confirmation that SS14MDP2 (silver,
   `D`-`P`-`2`) is acceptable for this exact load: ~3.3 mA initial transient decaying with a 100 us
   RC time constant to leakage/bias current, 3.3 V logic-level throws, no continuous wetting
   current, indoor bench/consumer environment.
2. **Contact-resistance measurement at the actual load.** Measure contact resistance through the
   switch under the real 1 kOhm/100 nF sense path (or an equivalent bench load reproducing the same
   transient/steady-state profile), not a generic continuity check, both when new and after aging
   below.
3. **Cycling/durability run.** Cycle a sample through its positions under the same real load for a
   defined number of operations (count TBD with the assembler/NKK's guidance) and re-measure
   contact resistance to detect any dry-circuit tarnish buildup NKK's guidance predicts.
4. **Environmental/cleaning exposure check.** Expose sample switches to the factory's actual
   flux/wash process (`design/evidence/g02-mechanical-pins.md` and NKK H44 cleaning notes) and
   re-check contact resistance, since flux residue and cleaning chemistry can compound tarnish
   effects on unwetted silver contacts.
5. Only after 1-4 return real evidence does `catalog/components.json`'s
   `application_suitability_status` move off `OPEN_REQUIRES_MANUFACTURER_CONFIRMATION_AND_QUALIFICATION`,
   and only then can G02/G08 close this item in `design/release-gates.json`.

## Acceptance-matrix tracking

`manufacturing/acceptance-results.csv` carries a `RANGE_CONTACT_QUALIFICATION` row with
`result=NOT_RUN`, per the width/format rules `#32` established (`scripts/validate_extra.py`'s
`_acceptance_csv` check). It moves to `PASS`/`FAIL`/`BLOCKED` only once §5 above is actually run,
with `evidence_file`, `operator` and `date` populated per that check's requirements.

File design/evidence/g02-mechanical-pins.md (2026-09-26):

# G02 desk evidence: switch, jack, button and module pin/mechanical maps

Status: **evidence_partial**. G02 stays OPEN. Everything below was read from manufacturer drawings and CAD. None of it comes from a physical part, a fitted footprint or an assembled stack. "Real-part fit" is still a local gate.

| # | Item | Verdict |
|---|---|---|
| 1 | NKK SS14MDP2 (RANGE, SP3T) terminal map and mechanics | **RESOLVED** (pins, pitch, holes, heights). Panel direction of L/H is a layout decision. |
| 2 | SHOU HAN PJ-313 5JCJ jack: duplicated legs | **OPEN**: the drawing does not say which physical leg carries which contact. The hole pattern is RESOLVED. |
| 3 | XUNPU TS-1088-AR02016 button | **RESOLVED**: two terminals, no internally joined pairs. The existing footprint matches the drawing. |
| 4a | Waveshare Pico-ResTouch-LCD-3.5 outline, sockets, active area, holes and heights | **RESOLVED** from the Waveshare STEP and dimension drawing. The PCB drill diameter is **OPEN**. |
| 4b | Pico H header positions / header height | Positions **RESOLVED**. Header height **OPEN**: no Raspberry Pi source dimensions it. |
| 5 | 1x20 2.54 mm female/male strips | **OPEN**: no orderable part is selected. The stack constraints are listed below. |

## Sources read

| ID | Source | Retrieved (UTC) | SHA-256 | Committed? |
|---|---|---|---|---|
| range-cat | NKK Series SS catalogue PDF, pages H44–H48 (5 pp., InDesign, subject `20180111`). Downloaded from the Catalog PDF button on `https://www.nkkswitches.eu/products/Slides/Slides%20SS/SS14MDP2/`, i.e. `POST /user/pdf-precheck katamei=SS14MDP2` with the page's XSRF cookie, then `GET /user/pdf-download/SS14MDP2`. No login was needed. | 2026-09-26T10:00Z | `bd75fbd29c691ec3fcd443570714081c51ab03e47ffacecc763228121b122fb5` | no (NKK terms not reviewed) |
| range | NKK SS14MDP2 product page (HTML) | 2026-09-26T09:59Z | `530bb5f8cf2fc3f11ab077ce59e063370be33ab792be6d4dee0e92021cd1b80c` | no |
| jack | `reference/assets/jack/PJ-313-5JCJ.pdf` (retained; p1 is the drawing, pp2–6 the test spec) | in repo | `8c3be622655208735ec21158f79aba16f5b1ae0b6621efa6ea6e2e89ac0d7199` | already retained |
| jack-easyeda | EasyEDA/LCSC library footprint `AUDIO-TH_PJ-313_5JCJ`, `https://easyeda.com/api/products/C668607/components?version=6.4.19.5` (contributor "Xkcc"; **third-party, not the manufacturer**) | 2026-09-26T10:07Z | n/a (JSON API) | no |
| button | `reference/assets/button/TS-1088-AR02016.pdf` (retained; 1 page, raster, title `TS-1088-ARXXX`) | in repo | `368d4cc2c26b08cb63e1b67193f671d0860b6d3fb2e6b9f2696ffade401afc30` | already retained |
| display-cad | `https://files.waveshare.com/upload/e/e4/Pico-ResTouch-LCD-3_5.zip` (contains only `Pico-ResTouch-LCD-3_5.stp`, Creo 2022-09-14, one merged solid) | 2026-09-26T10:02Z | zip `3ac36201418be8a033f13303aad4dc06f11b1a9fe1f44042c57d23e331fbcaf5`; stp `f94fee5c475b1ea6bb0ad1380c8afacc3192be3ca467238edd0212df139de548` | no (Waveshare terms unclear) |
| display-size | Waveshare wiki image `Pico-ResTouch-LCD-3.5-details-size.jpg` (`https://www.waveshare.com/w/upload/0/0e/…`) | 2026-09-26T10:03Z | `f1f7c86aad75b6944e72ff14b878a6b773b0cabb2375c719d827b9a8758e95a1` | no |
| display-inter | Waveshare wiki image `Pico-ResTouch-LCD-3.5-details-inter.jpg` (`https://www.waveshare.com/w/upload/c/c9/…`) | 2026-09-26T10:03Z | `bddbc75e6e4ecc8085569dc9b9a9bb1345b81463186514d9cc3470958ac07857` | no |
| pico-ds | `https://datasheets.raspberrypi.com/pico/pico-datasheet.pdf` (31 pp., modDate 2026-07-03) | 2026-09-26T10:01Z | `757ff485227493b9fcc0c2c96c4dea9de020e1d8b2b11e2aa4f9ee8b25aa89eb` | no |
| pico-step | `https://datasheets.raspberrypi.com/pico/Pico-R3-step.zip` (bare Pico R3; no header product inside) | 2026-09-26T10:02Z | n/a (checked for headers only) | no |

PDF pages were rendered to PNG with PyMuPDF 1.28.2 (MuPDF): whole pages at 150–200 dpi, and the areas that mattered again at 500–1200 dpi. I read the images directly. The STEP was parsed as text (ADVANCED_FACE / PLANE / CYLINDRICAL_SURFACE / VERTEX_POINT). Its edges were drawn as top (XY) and front (XZ) views and looked at, and they agree with the Waveshare dimension image. The rendered PNGs are not committed. Rerun the URLs above into the gitignored `reference/downloads/` to regenerate them.

Citation shorthand: `NKK H46` means the catalogue page number printed on the page (PDF page = H − 43). `Jack p1 <col><row>` uses the drawing's frame grid (columns 1–16, rows A–H). `Btn p1 <col><row>` uses the XUNPU frame grid (columns 1–15, rows A–J).

## 1. SS14MDP2: common is terminal 3; throws are 1 / 2 / 4

- **Circuit table** (NKK H46, "Poles & Circuits", row SS14M, SP3T ON-ON-ON):

  | Slide position | Connected terminals |
  |---|---|
  | Right | 3-4 |
  | Center | 3-2 |
  | Left | 3-1 |

  The schematic beside the table labels **3 (COM)** and draws terminals in the order 4, 3, 2, 1. The page notes "ON-OFF-ON circuit can be created by not connecting terminal 2", which confirms that 2 is the centre throw. NKK H46 also warns: **"Terminal numbers are not actually on switch."** Orientation on the PCB therefore comes from the asymmetric pitch (below), not from a marking.
- **Terminal layout, spacing code D (inch), 3-On models** (NKK H47, "Terminal Spacing" D, right column): one straight row of 4 terminals. Pitch is **2.54** for 1–2 and 2–3, then **5.08** for 3–4. The recommended PCB hole is **(0.8) Dia Typ**. The terminal section is (0.4) × (0.6) Typ. The isometric view gives the terminal projection as **(3.4)**, but H48 gives **(3.0)**. This conflict is recorded, not resolved; plan for 3.0–3.4 mm. The "D" code is also confirmed by the ordering chart (NKK H46: `D` = Inch .100″ × .100″; `P` = Top Actuated; `2` = Silver, 0.1 A @ 30 V DC).
- **Body and actuator** (NKK H48, "3-On Circuit • Top Actuated", SS14MDP2 views):
  - body length **(15.8)**, width **(4.0)**, height above the seating plane **(4.5)**;
  - terminal length below the body **(3.0)** (H47 isometric shows (3.4)), terminal section (0.4) × (0.6);
  - actuator (1.2) across × (1.5) along travel, standing **(2.0)** above the body top;
  - travel **(2.0) Typ** per step.
  - Derived: the actuator top sits about **6.5 mm** above the PCB (4.5 + 2.0). All values are in parentheses on the drawing, so they are reference dimensions without tolerances.
- **Centre alignment** (NKK H48 bottom and side views): the centre mark passes through terminal 3, and the actuator centreline (centre position) is in line with terminal 3. In the bottom view an unnumbered empty cavity sits between terminals 3 and 4. This alignment is read from the centre marks and is not a toleranced dimension.
- **Mounting pegs: none.** The bottom view (NKK H48) shows four oval standoff bosses at the corners of the body. No PCB peg or hole is called out anywhere on H44–H48. The only board holes are the four terminal holes.
- **Proposed logical-to-numeric map** (delta `range`): C → **3**, M → **2**, L → **1**, H → **4**. C = 3 and M = 2 are vendor facts. L = 1 / H = 4 follows NKK's Left/Right naming, but which way is "left" on the panel depends on how layout rotates the part. Layout must confirm this against the printed panel legend before the footprint is released.

## 2. PJ-313 5JCJ: hole pattern resolved, but which legs are duplicated is OPEN

**Resolved, from the drawing:**

- **It is a through-hole part.** The land-pattern view is titled 印制板开孔尺寸(±0.1) ("PCB hole/opening dimensions, ±0.1") with 显示为底面 ("shown as bottom face") (Jack p1 14B). The side view shows round-ended pin tails (Jack p1 2D–5E). The front view dimensions the tails as **3.2** below the body (Jack p1 7D). The five filled rectangles in the lower view are **slot openings**, not SMD pads. They measure **1.5 (along the jack axis) × 1.0** on the render: 1.51 × 0.99 mm against the 3.2 mm dimension. The callout reads "(6-1.X1.5)" (Jack p1 9G). The count "6" disagrees with the **5** slots drawn, and "1." is missing a digit. I read it as a drawing typo and take the size from the drawn geometry.
- **Slot positions** (Jack p1 5F–9G). The origin is the body shoulder where the Ø5 nose begins, which sits 2.5 mm behind the nose tip:
  - near row, 3 slots: x = 1.8, 5.0, 8.5 (dimension chain 1.8 / 3.2 / 3.5, then 3.1 to the rear face);
  - far row, 2 slots at x = 1.8 and 8.5 (vertically aligned with the near row's first and third slots);
  - row-to-row pitch **5.8** (the body is 6 wide, dimension "6").
  - The chain 2.5 + 1.8 + 3.2 + 3.5 + 3.1 = 14.1 disagrees by 0.1 with the side view's 2.5 + 11.5 = 14.0 (Jack p1 3C–6C). This is noted, not resolved.
- **Locating posts:** 2 × **Ø1** on the part (bottom view "2-φ1", Jack p1 15C). The board holes are **2 × Ø1.3** (Jack p1 8E–9E). They sit midway between the rows at x = **2.3** and **8.3** (2.3 + 6), so the posts are 6.0 apart. The drawing does not state plating for the post holes or the slots, so the plating choice is OPEN for the footprint author.
- **Body:** 11.5 long + 2.5 nose, 6 wide, 5 high. The nose is Ø5 OD with a **Ø3.6** opening (Jack p1 7C–8D). Weight 0.2 g, scale 5:1, sheet dated 2016-06-17, revision A (title block).
- **Three electrical nodes only:** the contact schematic 触点示意图 (Jack p1 16E–16F) shows contact **1** tied to the sleeve bar, **2** as a V spring and **3** as a ^ spring. There is no normally-closed switch contact. The drawing does not name tip or ring; reading 2 = ring and 3 = tip follows the symbol convention, not a printed label.

**OPEN: which physical leg belongs to which node.**

- The parts table (Jack p1 11F–16G, columns 序号 / 名称 / 数量 / 零件图号 / 对应端子号) lists:

  | Item | Part | Qty | Drawing no. | 对应端子号 (terminal no.) |
  |---|---|---|---|---|
  | ① | 1号触片 (contact 1) | 1 | PJ-313D-01 | 1 |
  | ② | 2号触片 (contact 2) | **2** | PJ-313D-02 | **2-3** |
  | ③ | 3号触片 (contact 3) | 1 | PJ-313D-03 | 4 |
  | ④ | 基座 (PPA base) | 1 | PJ-313D-03 | 5 |

- The table is internally inconsistent:
  - item ④, the plastic base, is given terminal "5";
  - ③ and ④ share drawing number PJ-313D-03;
  - terminal numbers 1–5 are **not written on any view**, so no slot can be tied to a number.
- The side view labels ①, ② and ③ only on the near row (Jack p1 2C–5C). Nothing labels the two far-row legs.
- The EasyEDA library footprint for C668607 numbers the pads **1, 3, 2** on the near row and **1, 2** on the far row. That would make the two outer columns the duplicated nodes. But that footprint is a third-party model. It also disagrees with the manufacturer drawing:
  - it uses round Ø0.8 holes, not 1.0 × 1.5 slots;
  - its row pitch is 6.3, not 5.8;
  - its post holes are Ø1.7, not Ø1.3;
  - its first post sits 0.7 behind the first column, not 0.5.
  So it **cannot be adopted as evidence**. It only shows that one plausible reading exists.
- **Resolution path:** get continuity on a sample leg by leg (a local bench check with an ohmmeter; no soldering), or get written confirmation from SHOU HAN or LCSC. Until then, tie every leg to its node only after that check. The `design/circuit.json` note "duplicated pad mapping is OPEN" stays accurate.

## 3. TS-1088-AR02016: two terminals, footprint matches the drawing

- **Part code** (Btn p1 7D–11F, ordering boxes):
  - `A` = stainless-steel dome (弹片 A:不锈钢);
  - `R` = no locating post (定位柱 R:无柱; `C` = with post);
  - `020` = **H 2.0 mm** (高度 020:2.0H);
  - `16` = **160 gf** operating force (力度 16:160g).
  - The exact variant therefore has **no board peg** and an actuator top **2.0 mm** above the seating plane. H is the dimension from the base to the actuator top in the side view (Btn p1 6B–7B; H table 1.8/2.0/2.5 at Btn p1 5D–6E).
- **Terminals:** exactly two, **①** on the left and **②** on the right in the top view (Btn p1 2D–4F). The circuit diagram is a single normally-open contact ①–② (Btn p1 5I–6I). With only two feet, **no pins are internally connected in pairs**. BOM item C 弹片 qty 2 (Btn p1 11H) is the two-layer dome, not a terminal.
- **Body:** 3.90 × 3.00. The terminals span 5.00 overall, and each terminal is 1.30 wide (Btn p1 2D–4E). Body height is 1.50, and the actuator is Ø1.80 (Btn p1 2B–4B).
- **Recommended land pattern** (PCB.焊接图, Btn p1 8H–9I): outside span **5.50**, inside gap **3.40**, pad height **2.00**. That gives a pad width of (5.50 − 3.40)/2 = **1.05** and pad centres at **±2.225**.
- **Footprint check:** `hardware/libraries/ZudoScope10.pretty/SW_XUNPU_TS1088_AR02016_REVIEW.kicad_mod` has pad 1 at (−2.225, 0) and pad 2 at (+2.225, 0), both SMD rect 1.05 × 2.0. The Fab outline is ±1.95 × ±1.5 (= 3.9 × 3.0). **Pads and body match the drawing exactly.** Pad 1 on the left matches ① on the left in the top view. The part is a symmetric two-terminal NO switch, so rotating it by 180° does not change the circuit. The courtyard (±3.0 × ±1.75) clears the pads by 0.25 mm. It needs no change for this gate. What remains is local fit and panel access (cap/actuator reach through the panel at H = 2.0).

## 4a. Waveshare module geometry, from the vendor STEP

**Frame used below:** the STEP's own coordinates, viewed from the **LCD side (+Z)**:

- the board spans x ∈ [−86.0, 0], y ∈ [0, 57.2];
- edge **E** (x = 0) is the edge nearer the header rows; edge **W** (x = −86) is the far edge;
- edge **N** (y = 57.2) is the header pin-1 end; edge **S** is y = 0;
- the Waveshare back-view photo (display-size / display-inter) is this frame mirrored left–right.

- **Outline:** 86.00 × 57.20 (display-size; STEP bbox). Corners have **R1.0** (four r = 1.000 cylinders, STEP). Edge N has two 1.0 mm-deep recesses: one for the RUN button at 38.64–47.62 from E, and one for the µSD socket at 61.06–76.95 from E (display-size dimension chain; the STEP outline shows the same notches).
- **PCB thickness 1.6** (STEP planes z = −0.411 and +1.189).
- **Mounting holes:** 4 holes at **4.10 / 4.10** from each corner, spaced **77.80 × 49.00** (display-size). The STEP centres at (−4.0996 / −81.8996, 4.0986 / 53.0956) agree. **Drill diameter OPEN:** the dimension image does not give it. The STEP has a Ø4.30 cylinder through the board and, under the board, a **Ø5.5 × 4.0 mm standoff with a Ø2.5 bore** on each hole. The Waveshare photo shows pillars at the holes. The standoff thread and hole size need a caliper check on the received module.
- **Header sockets** (female, on the side opposite the LCD):

  | Row | Pico pins | Distance from edge E | y of first pin | y of last pin |
  |---|---|---|---|---|
  | A | **1–20** | **10.45** | pin 1: 55.58 (**1.62 from N**) | pin 20: 7.32 (7.32 from S) |
  | B | **21–40** | **28.25** | pin 40: 55.58 | pin 21: 7.32 |

  - Pitch 2.54; row spacing is 17.80 in the STEP (17.78 nominal, pico-ds Fig. 3). Pin-cavity squares at 2.54 steps (STEP faces z = −1.411).
  - Pin identity comes from the Waveshare pin image: pins 1–20 on the outer row with pin 1 at the "USB" end, and pins 40/21 on the inner row (display-inter, rows labelled GP0 = 1 … GP15 = 20, VBUS = 40 … GP16 = 21). The image puts the pin-1 end at the RUN / µSD edge, which is edge N.
  - This matches the carrier data: J30 / J20 strip pin 1 = Pico position 1, and J31 / J21 strip pin 1 = Pico position 40 (`design/circuit.json`, J21 pin 1 `VBUS_USB`, J31 pin 2 `+5V_FUSED` = position 39).
- **Socket housing:** 2.5 wide × 51.3 long (y 5.80–57.10). It extends **9.0 mm** below the display PCB's bottom face (z −0.411 → −9.411). The modelled cavity floor is **8.0 mm** above the socket face (z −1.411). The model is simplified, so treat the 8.0 mm as indicative, not as the contact engagement spec.
- **LCD active area:** STEP face 73.44 × 48.96 at z = 6.339. That matches the catalogue's 48.96 × 73.44 and 480 × 320 px. Its edges sit **3.60 from E, 8.96 from W, 3.97 from N, 4.27 from S** (corners (−77.04, 4.27) to (−3.60, 53.23)). The active area is **not centred** on the board: it is shifted 2.68 mm toward E. Glass top outline 82.6 × 54.1 (x −84.0 … −1.4, y 1.7 … 55.8); panel frame 83.0 × 54.5 (z 3.189–5.389).
- **Heights, measured from the display PCB:**

  | Side | Feature | Height | Source (STEP z) |
  |---|---|---|---|
  | LCD face (above PCB top, z = 1.189) | glass top | **5.2** | z = 6.389 |
  | Back (below PCB bottom, z = −0.411) | header sockets | **9.0** | to z = −9.411 |
  | Back | standoffs | 4.0 | to z = −4.411 |
  | Back | RUN tact switch | 3.5 | z = −3.911, at edge N, x −46.6 … −39.6 |
  | Back | µSD socket | 2.1 | z = −2.511 |
  | Back | FPC connector | 2.3 | z = −2.711 |

  Overall module thickness without the Pico is **15.8 mm** (1.6 + 5.2 + 9.0).

## 4b. Pico H: positions resolved, header height OPEN

- **Board:** 51 × 21 × 1.0 mm. Pins sit on a 2.54 grid in two rows **17.78** apart, spanning **48.26** between the first and last pin of a row. Pin centres are **1.37** from each short edge ((51 − 48.26)/2), and the rows are inset (21 − 17.78)/2 = 1.61 from the long edges. There are 4 × Ø2.1 (± 0.05) mounting holes, 11.4 apart across the board, with the USB-end pair centred 2.0 from that edge and the opposite pair 2.4 from the far edge (Figure 3). The 1.37 edge distance is arithmetic, not a printed dimension. The micro-USB connector overhangs the top (pin-1) edge by **1.3 (typ)** (pico-ds §2 p6 text + Figure 3).
- **Numbering:** pin 1 is at top-left next to USB, pins 1–20 run down the left, and pin 40 is at top-right next to USB (pico-ds Figure 4, p7). This is the physical order `catalog/components.json` `pico-h.pins` already uses.
- **Pico H orderable:** SC0917 (pico-ds Appendix A Table 6, p24).
- **Header height OPEN:** the Pico datasheet does not dimension the factory header on Pico H, and the product brief only gives 21 × 51 mm. `Pico-R3-step.zip` contains a bare Pico with no header parts. The Pico H mating length and insulator height must come from a measured unit or a Raspberry Pi mechanical drawing, if one exists.

## 5. 1x20 2.54 mm strips: orderable not selected; stack constraints

No part is selected; this remains `SPECIFICATION_ONLY` in the catalogue. The facts above fix these constraints for layout and RFQ:

- **Display side (J30/J31, male on the carrier, mating into the module's female sockets):**
  - Mating pin length above the insulator must be **≤ 8.0 mm** (modelled socket cavity) and at least the socket vendor's minimum engagement (unknown; Waveshare does not publish the socket part).
  - If the socket face rests on the male insulator, the display PCB bottom sits at **h_ins + 9.0 mm** above the carrier.
  - The module's own 4.0 mm standoffs then fall short of the carrier by **h_ins + 5.0 mm**. Mechanical support needs added spacers of that length, or longer standoffs. It must not rest on solder joints or pins.
  - Nothing else on the module back hangs lower than the sockets (the tallest is the 3.5 mm RUN switch), so the sockets set the gap.
- **Pico side (J20/J21, female on the carrier, receiving the Pico H):**
  - The socket height and the Pico H header height (OPEN) together set the Pico's clearance.
  - Leave 1.3 mm beyond the pin-1 edge for the USB overhang, plus plug access.
- **If the Pico sits under the display:** the display gap (h_ins + 9.0) must exceed the carrier socket height + Pico H seated height + Pico top-side parts (USB connector included). Otherwise the modules must sit side by side. With both heights still unknown, this decides the placement and must be checked at layout.
- **Height classes to RFQ:** female strips by insulator height; male strips by insulator height and mating length. Pick exact MPNs whose drawings give these three numbers, then re-run the inequalities. Do not treat "2.54 mm 1x20" as a fit.

## What stays OPEN for G02

- PJ-313 5JCJ: which physical leg belongs to which contact node (sample continuity or vendor confirmation). The slot-count typo "(6-…)" and the 0.1 mm length-chain mismatch also need the vendor or a sample.
- SS14MDP2: the panel-side orientation of L/H (layout decision). Stock at C6684954 was zero; that is tracked in G08, not here.
- Waveshare: the mounting-hole drill diameter and standoff thread (caliper on the module), and the socket part's engagement spec.
- Pico H: header insulator height and pin length.
- 1x20 strips: exact orderables and the resulting stack. Real-part fit of every item above (local gate).

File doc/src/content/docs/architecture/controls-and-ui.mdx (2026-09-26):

---
# GENERATED by scripts/build_docs.py
title: "Physical controls and display behavior"
sidebar_position: 5
---

## Time and range

TIME is a dedicated 10 kΩ linear ALPS pot for each channel. Its electrical reading maps exponentially from a 2 ms whole-pane window to 8.192 seconds: `T = 0.002 × 4096^(code/4095)`. Endpoint calibration, averaging and a deadband are required to prevent jitter. Keep the physical knob position meaningful; do not turn it into an endless menu encoder.

RANGE is an actual maintained three-position SP3T switch. The selected NKK SS14MDP2 has On-On-On behavior, not a two-position SPDT and not a centre-OFF toggle. Throws select ground, a shared 1.65 V resistor midpoint and analog 3.3 V. The common feeds its own 1 kΩ / 100 nF filter and the RANGE mux. The draft uses logical C/L/M/H terminal labels until its numeric pin map is obtained.

Software decodes low, middle and high bands as ±3, ±5 and ±8 V. Deadbands retain the previous setting; a valid new setting must persist for 20 ms. This avoids intermediate readings during break-before-make travel. Filtering and software debouncing do not qualify the contact material at its actual low current.

HOLD freezes the plots; acquisition continues. LINK makes CH1's TIME control the source for all panes. Turning LINK off immediately restores the ten actual pot positions; it does not overwrite them. Both are press-to-toggle buttons with 20 ms debounce, and small on-screen labels indicate the active mode. LINK is a time-link of views, not phase synchronisation: all channels are still sampled sequentially.

## Screen layout

The firmware renderer (`firmware/src/scope_render.c`, details in `firmware/LCD-BACKEND.md`) draws ten 160 × 96 logical-pixel panes on the 320 × 480 portrait screen, two columns of five. Numbering is column-major, to preserve the physical banks: left controls 01–05 correspond to the five left-column panes, top to bottom, and right controls 06–10 to the right column, so CH6 is top right. Do not interleave screen labels 01/02 on the first row while the controls use a different order. The simulator follows this assignment, and `scripts/validate_extra.py` checks the firmware, simulator and panel study against each other.

Each pane has, from top to bottom:

- a label row: the two-digit channel ID in the channel colour, the vertical scale the plot is drawn at (`±3V` / `±5V` / `±8V`), `UNCAL` while the channel has no installed calibration, and the window duration, right-aligned (`2.0ms` … `8.19s`);
- a 4-pixel channel colour tag beside a 144 × 66 waveform plot, with the zero line and the newest sample at the right;
- a status row: the signal token `VIEW CLIP` or `ADC SAT`, then `LINK` and `HOLD` while those modes are latched;
- a one-pixel separator.

Text uses a 5 × 7 clean-room font on a 6 × 10 cell grid and is redrawn only when it changes. At the manufacturer's pixel pitch each complete pane is about 24.48 × 14.69 mm. This is a compact visual monitor, not ten large DATA-sized screens. Check the simulator at physical scale and print the panel SVG at 100% before committing the screen size.

## TIME mapping on screen

Each pane spans the whole window chosen by its TIME knob (or CH1's under LINK): W = round(`0.002 × 4096^(code/4095)` s × 10,000 samples/s), from 20 samples (2 ms) to 81,920 samples (8.192 s). The renderer draws it from the smallest min/max history level whose 192 bins cover W, so the existing ten levels reach 8.192 s with no extra memory. Columns merge bins (keeping each column's minimum and maximum, so an extreme anywhere in the window stays visible) or repeat them when there are fewer bins than columns. Each edge of the represented interval is within one coarse bin of the requested window: at most 512 samples, 51.2 ms, at the longest windows. With partial history the retained data sits right-aligned and the not-yet-recorded time stays blank. The duration label and the plot come from the same W, so the label names the interval the plot represents.

## RANGE mapping and calibration

The ±3/±5/±8 V ranges are software view scales: the switch does not change the analog path. Each column's raw minimum and maximum codes are converted to volts through that channel's calibration, then ±range maps to the plot height: +range at the top row, 0 V on the zero line, −range 64 rows lower, symmetric about zero. The zero line is electrical zero through the same mapping, not a fixed mid-scale code. With the nominal transfer, a +3 V input reaches the top edge at ±3 V and 3/8 of the positive half-height at ±8 V.

Until a calibration is installed the renderer uses an explicit nominal fallback, the ideal front-end figures in `reports/analog-analysis.json` (zero code 1858.378, about 8.07 mV/code), and the pane shows `UNCAL`. No calibration-persistence mechanism exists yet (`firmware/tools/calibrate.py` only writes a host JSON file), so every pane currently shows `UNCAL`. Nothing auto-zeroes at startup, and no per-channel calibration data is assumed. `scripts/validate_extra.py` checks the firmware's nominal constants against the analysis report.

A deadband reading keeps the last valid scale. Before the switch has ever decoded, the plot uses ±8 V and the scale label shows it in the warning colour. The scale label always names the scale the plot is drawn at, so under HOLD it stays with the frozen plot.

Two distinct conditions are reported in the status row. `VIEW CLIP` means converted volts exceed ±range: the trace is pinned at the edge with a separate warning-coloured marker, and only the view clips. `ADC SAT` means a raw code of 0 or 4095 in the drawn window, an ADC or input limit; it comes from raw codes, not volts, and takes priority. A clipped ±3 V view never reads as an ADC limit. Neither indicator certifies ±8 V tolerance or proves the absence of an overload between samples. All of this is host-tested against a pixel model; on-screen behaviour on the physical module is still an open G06 item.

## Simulator limits

`doc/public/prototype/index.html` is a synthetic interaction prototype: it generates mathematical waves in the browser. It demonstrates pane layout, clipping, controls, hold and linked time, not measured acquisition fidelity, display refresh performance, hardware noise, multiplexed skew or electrical protection.

No touch feature is used even though the selected purchased module has a touch overlay. A future lower-cost non-touch module can be substituted only after its exact electrical and mechanical interfaces are reviewed.

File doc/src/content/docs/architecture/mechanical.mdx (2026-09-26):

---
# GENERATED by scripts/build_docs.py
title: "Panel and mechanical study"
sidebar_position: 6
---

## Concept layout

The 250 × 180 mm panel study puts the portrait screen at the centre, five TIME/RANGE pairs on each side, and the ten input jacks at the outside edges. Left screen column 01–05 matches the left control bank; right column 06–10 matches the right bank. HOLD/LINK sit below the display. Jacks face outward so cables do not lie across the screen.

The SVG has real millimetre dimensions but is an **ergonomic study, not a fabrication drawing**. The screen active rectangle uses the manufacturer's stated 48.96 × 73.44 mm portrait area. Its exact placement within the module/window and its connector/bushing stack must be verified from the received module/CAD. Socket height, standoff height, underside Pico clearance and USB service access remain open.

`mechanical/envelope-study.scad` and its exported files describe a nominal slab and control/module envelopes only. They do not include exact terminal geometry or validated mounting holes. They must never be mistaken for a board STEP exported from a routed, populated KiCad design.

Use `reference/assets/pot/RK09L1140-F15.STEP` for the actual ALPS pot geometry; retain its manufacturer provenance. Do not infer pot rotation/offset relative to a footprint merely because its STEP renders correctly.

## Mechanical release checklist

Check shaft length above the final panel, cap and finger spacing, panel thickness, switch lever reach, button access and retention. Use the chosen pot nuts and load-bearing supports rather than leaving all user forces on solder joints. Check plug insertion force, TS plug sleeve/ring behavior, cable bend radius and no live circuitry touching a conductive panel.

Confirm the display and Pico may be unplugged only unpowered and cannot be shifted by one header pin during assembly. Bare unkeyed strip headers do not prevent reversed or offset insertion; specify visible pin-1 markings, mechanical alignment and an inspection procedure or choose keyed connectors for production. No drilling or exact enclosure machining should precede this review.

## G09 renderer capture (#44 / #26 part 3)

`mechanical/print/panel-1to1.svg`'s active-area rectangle now embeds `reports/renderer-capture.png`: a deterministic host capture of the actual `firmware/src/scope_render.c` / `scope_core.c` renderer, produced by linking those unmodified files against a recording `display_port.h` backend (`firmware/tools/capture_renderer.c`, built and run by `scripts/capture_renderer.py`). It feeds ten distinct sine/square/ramp waveforms at varied TIME codes and RANGE settings, with one channel UNCAL (invalid calibration), one VIEW CLIP (converted volts beyond the selected range without hitting the ADC rails), one ADC SAT (raw codes driven to 0/4095), and HOLD/LINK both latched. The browser prototype's synthetic UI cannot validate this firmware's actual geometry or font, so the G09 physical-review print now carries the real thing at the module's physical pixel pitch (320 x 480 px over 48.96 x 73.44 mm; about 24.48 x 14.69 mm per pane).

The rectangle also carries the 2.68 mm long-axis active-area offset recorded in `design/evidence/g02-mechanical-pins.md` (#4a, from the Waveshare module's vendor STEP): the active area sits off-centre toward that STEP's local edge E, not centred as the print previously drew it. Which physical panel edge (top or bottom of this print) edge E faces once the module is mounted is **not established by that evidence** — `mechanical/panel-layout-study.json`'s `active_area_offset_*` fields and the print's own on-sheet label record this as an explicit, unconfirmed ASSUMPTION (E assumed toward the top), not a resolved fact. G02 and G09 both stay OPEN pending confirmation against a received module.

`scripts/validate_extra.py` checks that the capture and the print regenerate byte-identically (`scripts/capture_renderer.py` writes no zlib-format-dependent bytes: it hand-encodes the PNG's DEFLATE stream as uncompressed "stored" blocks so the output depends only on the pixel data, not a particular zlib build), that the capture is exactly 320x480, and that the print embeds it at the documented scale and offset. `mechanical/print/panel-1to1.pdf` could not be regenerated in the environment that made this change (no `rsvg-convert`/`cairosvg` available) and is stale relative to the current SVG; see `mechanical/print/README.md`.

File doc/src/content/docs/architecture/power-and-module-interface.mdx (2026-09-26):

---
# GENERATED by scripts/build_docs.py
title: "Power and module interface \u2014 stop gate"
sidebar_position: 3
---

## One source only

Pico H's USB input supplies `VBUS_USB`. Carrier F1 passes it to `+5V_FUSED` for the display and the analog regulator. There is no external second supply connection. An eventual suitable USB 5 V source and the Pico USB/VBUS path must satisfy the measured total load and inrush. A 1 A-rated charger is a planned source, not permission to draw 1 A through an unverified PCB/header path.

The analog LDO is TLV75533PDBVR: 3.3 V output, input supply constrained to the [manufacturer limits](https://www.ti.com/lit/ds/symlink/tlv755p.pdf). Use the exact DBV pin assignment (1 IN, 2 GND, 3 EN, 4 NC, 5 OUT). EN is tied to fused 5 V. Use effective input/output capacitance of at least 1 µF as required by the datasheet. No PD voltage negotiation is present.

REF3330 generates 3.0 V and U6D buffers it. The ADC still uses Pico's own reference arrangement; two-point calibration is required to relate the separately generated analog bias to the ADC. The 3.0 V node is not incorrectly connected to Pico ADC_VREF.

## USB source contract

The display and analog-rail load on `+5V_FUSED` is unconditional: it is not gated by USB configuration state, suspend, or any firmware action (F1 passes `+5V_FUSED` to the display header and the analog regulator unconditionally). Because that load is not enumeration-gated, this module cannot rely on an ordinary host port's staged USB power budget (100 mA before configuration, 500 mA after). `design/power-contract.json` records the explicit supported-source contract instead: a USB port or supply that delivers **at least 500 mA at 5 V from attach**, independent of USB enumeration/configuration. Presence of 5 V on VBUS (e.g. a GPIO VBUS-sense pin) does not establish this -- it proves only that a 5 V source is attached, not that it can sustain the required current or that any USB configuration has occurred. An earlier draft's GPIO24/VBUS-sense suggestion is removed for exactly that reason (`design/power-contract.json`'s `decision_notes.rejected_gpio24_vbus_sense`).

Before configuration, during suspend, across a reset, and while the RP2040 bootrom is in BOOTSEL mode, this module draws more than the USB 2.0 unconfigured/suspend limits on an ordinary host port. Only a source meeting the contract above is supported in any of those states. The RP2040 bootrom presents its own USB descriptor during BOOTSEL, including its own declared max-power value; that value comes from the bootrom, not this project's firmware, and no number is cited for it here pending a bench descriptor dump. A configuration-gated hardware load switch (using real USB configured state, not VBUS presence) is recorded as a future compliant-host option, with no part or firmware mechanism chosen.

## Physical header numbering

J20/J30 are the left 20-contact strips: carrier contact `k` corresponds to Pico position `k` (1–20). J21/J31 are the right strips: contact `k` corresponds to Pico position `41-k` (40 down to 21). This convention is recorded explicitly in `design/circuit.json` and checked in the data tests.

J20/J21 accept Pico H. J30/J31 accept the display module. Do not merge these two 40-position interfaces electrically. Only the documented LCD signals, select signals, ground and intended power path pass through the carrier.

## G01 — do not route a presumed power connection

The present netlist proposes display Pico-position 39 (VSYS) fed by fused 5 V, with positions 36 (3V3), 37 (3V3_EN), 35 (ADC_VREF) and 40 (VBUS) isolated. **This is conditional and not power-qualified.** The module schematic was readable as extracted text, but its power-strapping diagram could not be visually verified in this environment. Verify the exact received module revision, its regulator/strap resistors and required GPIO level supplies before finalizing the header footprint/netlist.

The Waveshare board can have extra memory/clock/power-control nets on otherwise spare Pico positions. GP3, GP5 and GP14 on the display header are not automatically tied to the custom carrier's mux controls or timing output. Trace any additional requirements from the correct manufacturer schematic. Do not energize an unverified arrangement and assume a blank screen is a firmware issue.

The independent source files are listed in `catalog/sources.json`. `scripts/fetch_sources.py --execute` downloads available originals locally; retrieval does not establish that they have been reviewed.

## Signal contract

| Function | Pico GPIO |
|---|---|
| HOLD, LINK | GP0, GP1; active-low buttons |
| Mux address bit 0…3 | GP2, GP3, GP4, GP5 |
| Mux disable | GP7; HIGH disconnects all banks |
| LCD DC / CS | GP8 / GP9 |
| SPI1 SCK / MOSI / MISO | GP10 / GP11 / GP12 |
| LCD backlight / reset | GP13 / GP15 |
| Timing test point | GP14 |
| Touch / SD deselect | GP16 / GP22 |
| Signal / TIME / RANGE ADC | GP26 / GP27 / GP28 |

All address changes occur while mux disable is high in the diagnostic firmware. The LCD backlight is **active-low and default ON**: GP13 drives the gate of an open-drain N-channel MOSFET (Q1) on the module's `LCD_BL` node, so GP13 high = backlight off, GP13 low or undriven = backlight on (see "Backlight interface" below). Chip-selects pull high. Do not assume asynchronous analog and digital 3.3 V startup is harmless: qualify power sequencing and unpowered injection into the mux/ADC paths.

## Provisional power allocation

Allocate 300 mA to the screen/backlight module, 80 mA to Pico and 40 mA to carrier analog/control circuitry for planning. These are **budget allowances, not measured or manufacturer maximum currents**. Their sum is 420 mA; verify USB startup/enumeration limits, F1 derating, local capacitance and connector ratings. At 40 mA the analog LDO's ideal 5-to-3.3 V dissipation is about 68 mW, excluding any abnormal condition. Do not infer a thermal pass from this estimate.

Structured module-power evidence (module VSYS capacitance, backlight topology, and the disputed 180 mA claim) lives in `design/evidence/module-power.json`, one status (`verified-schematic` / `allowance` / `unknown` / `rejected`) per claim, consumed by `scripts/power_budget.py` and this page so they cannot disagree. The module's own VSYS capacitors total a verified 11.2 µF; combined with carrier C30 (1 µF) that is a known 12.2 µF carrier+module nominal subtotal, reported against the informal ≤10 µF inrush guidance -- not a claim of measured inrush compliance, since Pico-side bulk capacitance is still unknown. The backlight is a CAT1 regulator feeding LED-A, with three LED cathode returns to ground through R17-R19; CAT1's identity and output current remain unknown. F1 sits between `VBUS_USB` and `+5V_FUSED` and carries only the display+analog branch (340 mA), not the full 420 mA total source current: at a 1.5x sizing margin that is a 510 mA target, 10 mA above the selected `1206L050YR` candidate's 500 mA nominal hold rating, with no manufacturer temperature-derating curve retained to confirm its actual derated hold current. A PPTC is not a precision USB current limiter. See `reports/power-budget.json`'s `f1_branch_sizing` and `downstream_capacitance_5v_fused` sections for the full figures.

`design/power-contract.json` also holds the declared USB configuration-descriptor value that `scripts/power_budget.py` checks the 420 mA allowance against. That declared value is currently 250 mA -- the unmodified Pico SDK 2.1.1 default, not a project override: the pinned SDK source does not guard `USBD_MAX_POWER_MA` with `#ifndef`, so a compile-time override does not reliably change the compiled descriptor, and no unverified hand-written descriptor replacement is shipped without a hardware bench to check it against (see `power-contract.json`'s `override_investigation`). Because 420 mA exceeds that declared 250 mA, `reports/power-budget.json`'s `usb_budget.vs_declared_limit` correctly reports `fail`, not a masked pass -- this module currently declares less configured power than its own planning allowance, on top of already requiring a source outside the ordinary staged USB budget (see "USB source contract" above).

## Backlight interface (GP13) — open-drain stage, default ON, active-low (#41)

Desk evidence (#3, #19) established that the display module's own R16 (10k, VSYS -> LCD_BL) pulls the backlight-enable/CAT1-EN node toward the module's ~5 V VSYS rail. The former carrier wiring (GP13 through R64 straight to `LCD_BL`, with R88 100k to GND) left an undriven GP13 near 4.5 V, above the RP2040 GPIO absolute maximum of IOVDD + 0.5 V. Neither "remove R88" (node approaches 5 V) nor "accept an estimated clamp current" (relies on an undocumented clamp) met the pin limits, so the carrier circuit is changed instead of waiting for a measurement.

**Design now applied in `scripts/make_design.py`:** GP13 -> R64 (33 Ω) -> net `LCD_BL_GATE` -> gate of Q1, a generic logic-level N-channel MOSFET (`catalog/components.json` record `nmos-ll`, no MPN/LCSC code, exact part at G08). R88 (100k) is repurposed as the gate pull-down. Q1's drain is `LCD_BL` (J30 position 17, header net unchanged) and its source is GND; the module's R16 stays the only pull-up on `LCD_BL`. The GPIO pad therefore sees only its own drive or 0 V in every state -- USB 4.75–5.25 V, reset, BOOTSEL, either power-up order and normal operation -- and no protection clamp is assumed anywhere (`design/evidence/backlight-interface.md` has the per-state voltage/current table and the alternatives weighed). `scripts/validate_extra.py` asserts that GP13's net has no resistive DC path below 1 MΩ to `+5V_FUSED`, `VBUS_USB` or `LCD_BL`.

**Default state and polarity are explicit:** backlight **ON** whenever GP13 is low or undriven (reset, BOOTSEL/ROM, before the firmware hook), backlight **OFF** when GP13 is high. Firmware follows this inversion (`firmware/src/lcd_safe_pins.[ch]` drives GP13 high early to darken the panel; `scope_display_backlight()` drives it low to light it; `SCOPE_ENABLE_LCD` stays default OFF). `design/power-contract.json`'s `power_states` carry the backlight state per state. CAT1's identity and EN thresholds remain unknown (`design/evidence/module-power.json`); the off state relies only on `LCD_BL` being held near 0 V and the on state on the module's own R16 behaviour.

**Still OPEN (G01/G06):** the assembler/bench provider checks the actual module revision and population (R16, CAT1) and captures the GP13, gate and `LCD_BL` waveforms from power-on on a factory-assembled prototype before either gate closes (`LOCAL-HANDOFF.md` G01 items 2–3, G06 step 1; acceptance row `BACKLIGHT_GP13_INTERFACE`). `pending_g01_changes[id=g01-r88-backlight-default]` in `design/circuit.json` records the status `DESIGN_APPLIED_BENCH_CHECK_PENDING`.

Citations: Waveshare Pico-ResTouch-LCD-3.5 schematic p1, LCD BACKLIGHT (3A), R16 10K VSYS->LCD_BL/CAT1 EN pin 3; RP2040 datasheet Sec 5.5.3.1, Table 622 (PDF p615).

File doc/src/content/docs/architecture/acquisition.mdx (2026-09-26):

---
# GENERATED by scripts/build_docs.py
title: "Acquisition, bandwidth and memory"
sidebar_position: 4
---

## Three independent mux outputs

U7 selects one of ten buffered signal channels into ADC0. U8 selects one of ten TIME controls into ADC1. U9 selects one of ten RANGE controls into ADC2. They share four address bits and a disable signal, but their analog common outputs are never connected together.

Each mux common output is buffered by its own TLV9064 section, followed by 100 Ω / 1 nF at the corresponding ADC pin. The mux switches already-conditioned unipolar signals, never raw ±12 V inputs. The precise settling time at 3.3 V, charge injection, crosstalk, and ADC acquisition after a large step must be measured.

## Intended later high-rate schedule

The [Pico SDK ADC documentation](https://www.raspberrypi.com/documentation/pico-sdk/hardware.html) specifies 500 ksample/s aggregate and 12-bit conversion, but only about 8.7 effective bits for RP2040. Ten channels do not each get that aggregate rate. Address switching, ADC input switching, settling, firmware overhead and display servicing also consume time.

P0 reserves a 100 µs frame: ten 8 µs signal slots (80 µs), two 8 µs control slots (16 µs), and 4 µs margin. A slot is intended to disable/change/enable the mux, settle, discard one ADC conversion, and retain a second conversion. Each frame reads TIME and RANGE for one advancing control channel, giving a nominal 1 kHz control scan per channel. Every signal would receive one sample/frame, or 10 ksample/s.

This is a **timing design target**, not an implemented 100 µs real-time engine. The delivered Pico diagnostic intentionally runs much slower and reports raw codes over USB. Develop the high-rate timer/DMA/PIO or tightly bounded acquisition engine only after measuring real settling. Reserve hardware timer timestamps and record overruns instead of silently claiming a rate.

Maximum nominal signal-channel skew is 72 µs between the first and tenth slots. “Ten signals visible” is not simultaneous sampling. LINK TIME changes viewing windows, not sample timing. Phase or transient comparisons require correction for known channel offsets and an explicit common trigger model.

## Memory and display

A whole 320 × 480 RGB565 framebuffer is 307,200 bytes. It does not fit in RP2040's 264 kB SRAM. Do not allocate it and hope compression or the linker fixes the problem.

Use streamed strips or tiles; for example a 160 × 16 RGB565 tile is 5,120 bytes, or 10,240 bytes double-buffered. The portable history implementation uses 77,800 bytes for ten channels: ten levels × 192 min/max bins, retaining both extrema through decimation. At 10 ksample/s the coarsest 512-sample bins span about 9.83 seconds, sufficient for the proposed 8.192-second window. Min/max is an envelope representation: do not label those extrema as uniformly resampled raw points.

At 8 MHz, a full RGB565 payload alone takes 307.2 ms; at 24 MHz it takes 102.4 ms. Commands, software and bridge behavior add overhead. P0 starts at 8 MHz. Update only necessary tile regions, reduce redraw rate gracefully, and prioritize acquisition. Never infer 30 FPS full-screen performance from a vendor maximum SPI clock.

## Accuracy and clipping

Nominal input-referred ADC code width is about 8.07 mV using 3.3 V / 4096. This is a scale factor, not effective measurement resolution or absolute accuracy. Op-amp/reference error, source impedance, ADC nonlinearity and noise require characterization. UI should show a clear UNCAL indicator until calibration is installed. Display one or two decimals conservatively; do not make an unjustified three-decimal voltmeter.

Distinguish VIEW CLIP (signal exceeds ±3/5/8 pane scale) from ADC SAT (conversion near an ADC rail). A ±8 V display does not certify ±8 V tolerance or prove absence of an overload outside the sampled instant.

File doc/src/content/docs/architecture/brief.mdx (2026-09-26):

---
# GENERATED by scripts/build_docs.py
title: "P0 specification and tradeoffs"
sidebar_position: 1
---

## Fixed scope

| Item | P0 proposal |
|---|---|
| Inputs | 10 independent DC-coupled mono signals |
| Viewing | 1 LCD; portrait 320 × 480 logical pixels; 2 columns × 5 rows |
| Controls | 10 TIME pots, 10 three-position RANGE switches, HOLD and LINK buttons |
| Vertical display scales | ±3 V, ±5 V, ±8 V; software changes only |
| Input working target | ±12 V, subject to qualification |
| Power | USB 5 V only; no USB-PD or Eurorack power header |
| Acquisition target | 10,000 samples/second/channel, sequential; not yet implemented or measured |
| Intended useful signal range | CV/LFO and low audio, approximately DC–1 kHz |
| Time windows | 2 ms–8.192 s across the whole pane, not per division |
| Approximate panel envelope | 250 × 180 mm; control placement is only a study |

The 1 kHz intention is not a guaranteed metrology bandwidth. At 10 ksample/s/channel, Nyquist is 5 kHz; a 20 kHz input can alias severely. Two nominal 3.39 kHz RC poles only provide about 10 dB attenuation at Nyquist. The front end is therefore **not a brick-wall anti-alias filter**. Do not claim accurate full-audio-band viewing.

## Why modules for the first carrier

The [Waveshare module](https://www.waveshare.com/Pico-ResTouch-LCD-3.5.htm) documents 480 × 320 pixels, a 5 V supply, an installed female Pico header, a 73.44 × 48.96 mm active area and an 86 × 57.2 mm PCB. Its SPI-to-parallel bridge is part of the module. Buy the exact assembled version.

[Pico H](https://www.raspberrypi.com/products/raspberry-pi-pico/) includes the headers; an ordinary unheadered Pico does not meet the project requirement. The custom carrier uses two female strips for Pico H and separate male strips for the display. Most spare display contacts are deliberately isolated rather than blindly passed through.

This costs more than a bare RP2040 plus a bare display. The prototype exception avoids designing the MCU's USB/flash/regulator board and an insufficiently documented LCD interface at the same time as ten analog inputs. A later revision may integrate both after their performance is established.

## Not selected for P0

HS35B01A / C19632787 remains a cost-down candidate, not the baseline: the public listing does not establish a reviewed serial interface, power arrangement, connector pin map or exact drawing. Do not treat the earlier roughly $9 display figure as the cost of the present module or the finished instrument.

No touchscreen interaction, SD storage, FFT, tuner, signal generator, audio output, battery, network feature or oscillator core is included. TOUCH and SD chip-selects are held inactive. The presence of those parts on the purchased module does not put them in our feature list.

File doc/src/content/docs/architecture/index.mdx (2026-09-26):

---
# GENERATED by scripts/build_docs.py
title: "Design architecture"
sidebar_position: 0
---

## Pages

- [P0 specification and tradeoffs](/docs/architecture/brief/)
- [Input circuit and analytical checks](/docs/architecture/input-front-end/)
- [Power and module interface — stop gate](/docs/architecture/power-and-module-interface/)
- [Acquisition, bandwidth and memory](/docs/architecture/acquisition/)
- [Physical controls and display behavior](/docs/architecture/controls-and-ui/)
- [Panel and mechanical study](/docs/architecture/mechanical/)

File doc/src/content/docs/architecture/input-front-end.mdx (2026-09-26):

---
# GENERATED by scripts/build_docs.py
title: "Input circuit and analytical checks"
sidebar_position: 2
---

## Repeated channel

The same circuit is instantiated ten times. A 1 MΩ input resistor feeds a node connected through 200 kΩ to the buffered 3.0 V reference and through 249 kΩ to ground. A 470 pF C0G capacitor makes the first low-pass pole. A unity buffer, 4.7 kΩ / 10 nF C0G low-pass stage and second unity buffer feed the signal multiplexer.

BAV199 provides a low-leakage dual-diode clamp at the biased node. It is **silicon, not a Schottky device**. The node is protected primarily by high series resistance and the documented amplifier input current path; a diode to a rail is not by itself proof that all absolute-maximum conditions are satisfied.

Two complete channels use one physical TLV9064IDR. U1–U5 provide the 20 input buffer amplifiers. U6 supplies the three post-mux buffers and the reference buffer. The design data enumerate every physical IC pin, rather than inventing multiple U references for the same package.

## Transfer function

Let `G = 1/1M + 1/200k + 1/249k`. For an ideal low-impedance source:

```text
Vnode = ((Vin / 1M) + (Vref / 200k)) / G
      = 0.099839615 × Vin + 1.497594226 V, with Vref = 3.0 V
Vin   = (Vnode - 1.497594226) / 0.099839615
```

At −12 V the nominal node is 0.299519 V; at +12 V it is 2.695670 V. Both leave nominal headroom on a 3.3 V analog rail. The 0.1% divider-resistor / 0.15% reference corner enumeration spans 0.294579 V at the negative end to 2.700079 V at the positive end. **This excludes op-amp offset, temperature, diode leakage, source resistance, ADC errors, capacitance tolerance and PCB parasitics.** It is not a complete tolerance certification.

The effective Thevenin resistance is 99.84 kΩ, giving a first pole near 3,392 Hz. The second pole is near 3,386 Hz. Nominal combined attenuation is −0.19 dB at 500 Hz, −0.73 dB at 1 kHz, −2.60 dB at 2 kHz and −10.04 dB at 5 kHz. These filters soften pulse/saw edges, even when their fundamentals are below 1 kHz.

Run `python3 scripts/analyze.py` to reproduce all values. `reports/analog-analysis.json` and `reports/filter-response.csv` are calculated, not measured. `simulation/input-channel.cir` is an ideal-buffer ngspice starting model; vendor macro-model and transient/fault validation have not been run.

## Input loading and open cables

Small-signal input impedance is approximately 1.111 MΩ. The biased resistor network sends approximately 1.50 µA into a source held at 0 V. A 1 kΩ source resistance can therefore create millivolt-scale bias error.

**An unconnected input does not read 0 V.** With the selected unswitched jack open, its biased node settles near 1.663697 V, which is displayed as approximately +1.663697 V after the nominal conversion. This is an expected P0 limitation, not a detected connected signal. The software must never silently subtract every channel's power-up value, because that would erase legitimate DC voltages.

A later switched jack that shorts the input to ground while unplugged can solve this, but it requires a new exact part, pad/contact map and mechanical qualification. The current PJ-313 5JCJ is not a switched/normalled jack.

## Protection is an open engineering gate

±24 V is a **test target**, not a qualified rating. The 1 MΩ resistor bounds an approximate positive injection current to 24 µA/channel. Ten such channels could inject 240 µA into an unpowered system; a 1 kΩ analog-rail bleed gives an ideal 0.24 V bound under that simplified assumption. Negative injection, individual internal rail paths, ESD, latch-up, diode forward voltages, power sequencing and leakage are not proved by that arithmetic.

Before connecting this prototype to valued equipment, qualify positive/negative powered and unpowered inputs with current-limited fixtures at the assembler or bench-service provider. Never connect mains, speakers/amplifier outputs, unknown industrial voltages or a different ground potential. The instrument is non-isolated and its ground may be bonded to a USB computer.

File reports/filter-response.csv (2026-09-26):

Hz | gain | dB | source
1.0 | 0.9999999129319392 | -7.562635996953039e-07 | CALCULATED_IDEAL_NOT_MEASURED
1.052500285277733 | 0.99999990354976 | -8.377561807527522e-07 | CALCULATED_IDEAL_NOT_MEASURED
1.107756850509709 | 0.9999998931565871 | -9.280301425353767e-07 | CALCULATED_IDEAL_NOT_MEASURED
1.1659144011798317 | 0.9999998816434787 | -1.028031742363078e-06 | CALCULATED_IDEAL_NOT_MEASURED
1.22712523985119 | 0.9999998688897546 | -1.138809196950735e-06 | CALCULATED_IDEAL_NOT_MEASURED
1.2915496650148839 | 0.9999998547617293 | -1.2615236825115146e-06 | CALCULATED_IDEAL_NOT_MEASURED
1.3593563908785256 | 0.9999998391113131 | -1.3974614910933324e-06 | CALCULATED_IDEAL_NOT_MEASURED
1.4307229891937576 | 0.9999998217744583 | -1.5480475234787313e-06 | CALCULATED_IDEAL_NOT_MEASURED
1.5058363542798405 | 0.9999998025694389 | -1.7148602343687279e-06 | CALCULATED_IDEAL_NOT_MEASURED
1.5848931924611136 | 0.9999997812949483 | -1.8996481503931058e-06 | CALCULATED_IDEAL_NOT_MEASURED
1.6681005372000588 | 0.9999997577279863 | -2.1043482280677694e-06 | CALCULATED_IDEAL_NOT_MEASURED
1.7556762912750012 | 0.9999997316215242 | -2.3311061346336383e-06 | CALCULATED_IDEAL_NOT_MEASURED
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

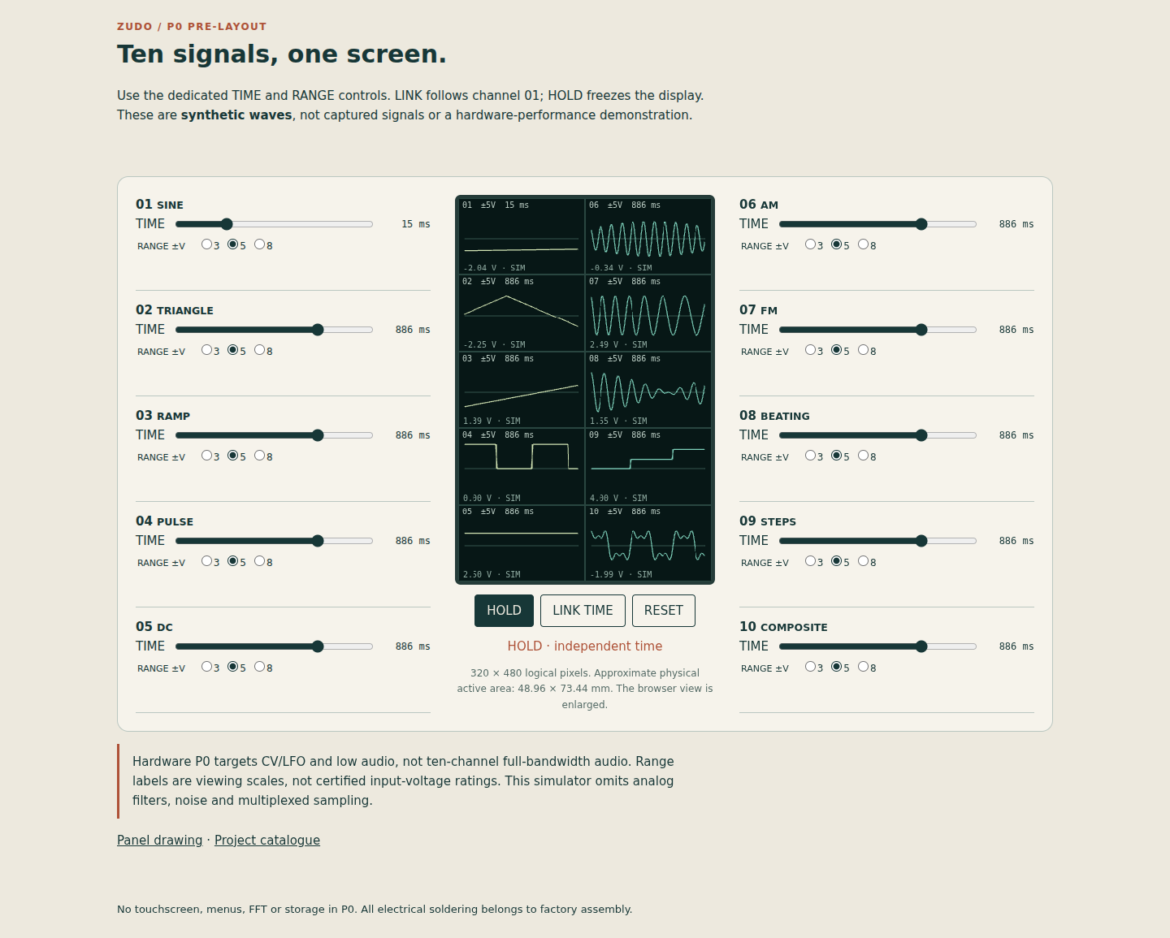
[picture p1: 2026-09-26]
reports/ui-desktop.png

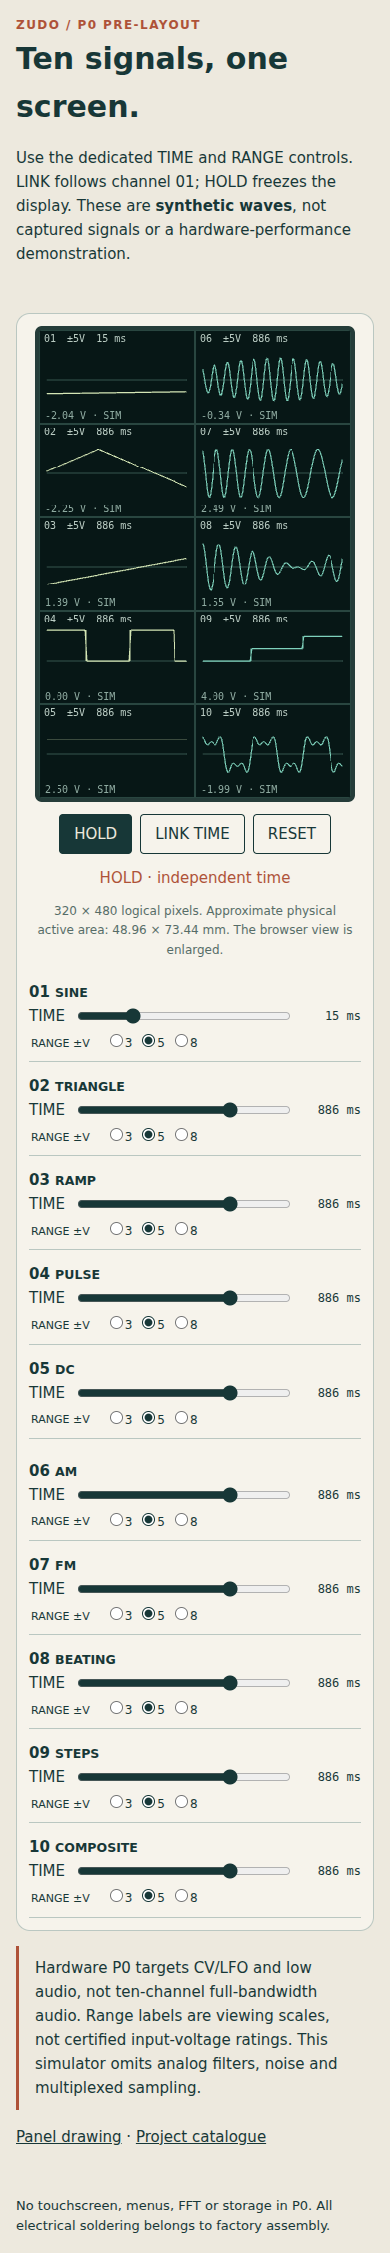
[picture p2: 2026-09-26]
reports/ui-mobile.png

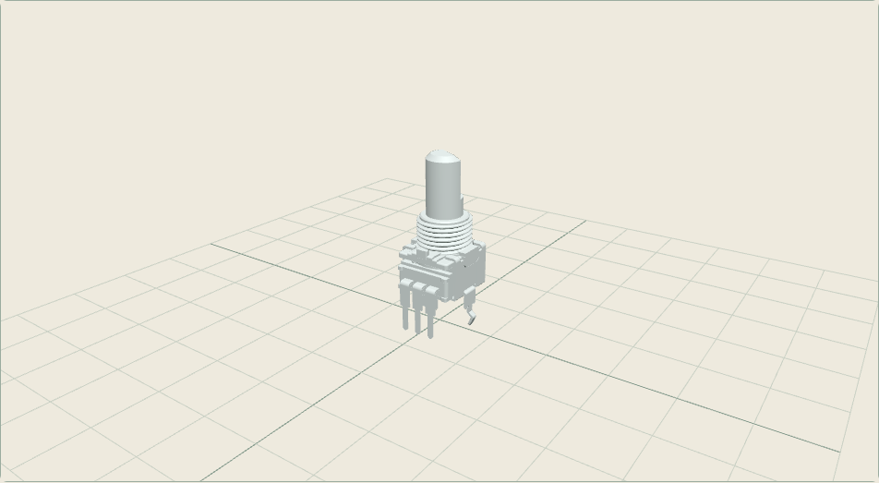
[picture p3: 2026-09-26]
reports/ui-glb-viewer.png

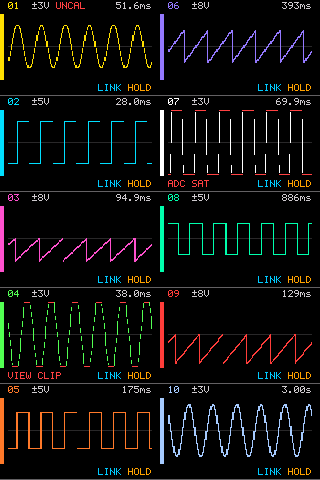
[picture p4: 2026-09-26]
reports/renderer-capture.png

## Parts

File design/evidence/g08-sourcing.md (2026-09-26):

# G08 desk evidence: sourcing candidates for specification-only BOM rows

Evidence only. No catalog, BOM or generator file is edited by this document. Every
row below stays in the state recorded in `catalog/components.json` /
`manufacturing/bom-planning.csv`; a listing here is a **candidate**, never an
allocation, order, or fit confirmation. All C-numbers below were read from a
fetched LCSC/JLCPCB page on **2026-09-26** (dates noted per entry); none is
invented. Where a page could not be fetched or no matching listing was found,
the row is left `OPEN` with the reason stated.

Machine-readable form: `design/evidence/g08-delta.json`. Every entry there
carries `"listing_not_allocation": true`.

## Method

- LCSC product-detail pages (`lcsc.com/product-detail/...`) fetched via
  WebFetch. These render server-side and returned real spec/stock data.
- JLCPCB `partdetail` pages (`jlcpcb.com/partdetail/...`) fetched via WebFetch
  render but do not expose live stock figures in the fetched markdown — LCSC's
  own product page was used for stock/status wherever both exist for the same
  C-number.
- `lcsc.com/search?...` search-results pages did **not** render usable content
  through WebFetch (the tool returned only the site footer/nav — the results
  grid is client-side rendered). No LCSC/JLC "search" or "list" API endpoint
  was reachable either; only direct `product-detail` / `partdetail` pages by
  known C-number worked. Candidate C-numbers were therefore identified via
  WebSearch (which surfaces LCSC product-detail URLs already indexed by
  search engines) and then **verified** by fetching each candidate's own LCSC
  page directly — no C-number below is taken from a search snippet alone.
- Basic/extended/preferred JLC assembly-tier labels were not exposed on any
  fetched LCSC or JLC page for any part in this pass; where the field below
  says "not stated on page", that is a fetch limitation, not a finding that
  the part lacks the tier.

## Known listings — recheck (2026-09-26)

| Catalog id | Current jlc_code | MPN | Source | Stock observed | Notes |
|---|---|---|---|---|---|
| tlv9064 | C388176 | TLV9064IDR | https://www.lcsc.com/product-detail/C388176.html | 8,213 | TI, SOIC-14. Basic/extended tier not stated on page. |
| mux | C179326 | 74HC4067PW,118 | https://www.lcsc.com/product-detail/C179326.html | 1,122 | Nexperia, TSSOP-24. |
| ldo | C404027 | TLV75533PDBVR | https://www.lcsc.com/product-detail/C404027.html | 138,170 | TI, SOT-23-5. |
| clamp | C40919 | BAV199,215 | https://www.lcsc.com/product-detail/C40919.html | 111,180 | Nexperia, SOT-23. |
| range | C6684954 | SS14MDP2 | https://www.lcsc.com/product-detail/C6684954.html | **0 — "Currently out of stock (notification option available)"** | NKK Switches, through-hole SP3T. Confirms the zero-stock condition already noted in the issue; unchanged. |
| pot | C7419101 | RK09L1140A5L | https://www.lcsc.com/product-detail/C7419101.html | 473 | ALPSALPINE, through-hole, ±20% tolerance per page (page shows 10kΩ/50mW/10V; the BOM's mechanical-spec note about shaft/bushing is unaffected by this recheck). |

All six pages fetched successfully; none was bot-blocked.

## Specification-only rows — candidates found

Each candidate below was confirmed by fetching its own LCSC product page.
"Meets spec" judges only the parameters stated in
`catalog/components.json`'s `facts` for that row (value, tolerance, tempco,
dielectric, voltage) — it is not a footprint, fit, or assembly-tier finding.

### Precision resistors (0603)

| Catalog id | Spec | Candidate MPN | Manufacturer | LCSC | Source URL | Stock | Meets spec |
|---|---|---|---|---|---|---|---|
| r1m | 1MΩ, 0.1%, 25ppm/°C | RT0603BRD071ML | YAGEO | C326730 | https://www.lcsc.com/product-detail/C326730.html | 8,540 | Yes — 1MΩ ±0.1%, ±25ppm/°C, 0603 confirmed on page. |
| r200k | 200kΩ, 0.1%, 25ppm/°C | RT0603BRD07200KL | YAGEO | C728585 | https://lcsc.com/product-detail/chip-resistor-surface-mount_yageo-rt0603brd07200kl_C728585.html | 248,120 | Yes — 200kΩ ±0.1%, ±25ppm/°C, 0603 confirmed on page. |
| r249k | 249kΩ, 0.1%, 25ppm/°C | — | — | — | — | — | **OPEN.** The YAGEO family member `RT0603BRD07249KL` exists per the manufacturer's own spec sheet (yageogroup.com), but no LCSC product-detail page for it was found via search or by probing the same URL pattern as the 1M/200k siblings. Not fetched, so not recorded as a candidate here. |

### General-purpose resistors (0603, 1%)

| Catalog id | Spec | Candidate MPN | Manufacturer | LCSC | Source URL | Stock | Meets spec |
|---|---|---|---|---|---|---|---|
| r4k7 | 4.7kΩ, 1% | HoLTT0603-1/10W-4.7K-1% | Milliohm | C2904521 | https://www.lcsc.com/product-detail/C2904521.html | 820 | Yes — 4.7kΩ ±1%, 0603 confirmed on page. |
| r10k | 10kΩ, 1% | 0603WAF1002T5E | UNI-ROYAL | C25804 | https://www.lcsc.com/product-detail/C25804.html | **0 — "Out of Stock" ("Notify Me")** | Value/tolerance/package match; stock is currently zero. |
| r100k | 100kΩ, 1% | 0603WAF1003T5E | UNI-ROYAL | C25803 | https://www.lcsc.com/product-detail/C25803.html | 17,040,200 | Yes. |
| r100 | 100Ω, 1% | 0603 ±1% 100Ω | VO | C2889384 | https://www.lcsc.com/product-detail/Chip-Resistor-Surface-Mount_VO_C2889384.html | **0 — "Not available now"** | Value/tolerance/package match; stock is currently zero. |
| r1k | 1kΩ, 1% | 0603WAF1001T5E | UNI-ROYAL | C21190 | https://www.lcsc.com/product-detail/C21190.html | 7,514,000 | Yes. |
| r33 | 33Ω, 1% | RC0603FR-0733RL | YAGEO | C108661 | https://www.lcsc.com/product-detail/C108661.html | 85,500 | Yes. (A UNI-ROYAL "0603WAF3300T5E" / C23138 found in the same search is **330Ω, not 33Ω** — confirmed by fetch and rejected as a false match; not included as a candidate.) |

### Capacitors (0603 C0G / 0603 X7R / 0805)

| Catalog id | Spec | Candidate MPN | Manufacturer | LCSC | Source URL | Stock | Meets spec |
|---|---|---|---|---|---|---|---|
| c470p | 470pF, C0G, 5%, ≥25V | 06035A471KAT2A | Kyocera AVX | C597169 | https://www.lcsc.com/product-detail/multilayer-ceramic-capacitors-mlcc-smd-smt_kyocera-avx-06035a471kat2a_C597169.html | 240 | Yes — 470pF, C0G, ±10% (tighter spec than needed's 5% max — page states 10%, so tolerance is actually looser than the design's "5%"; flagged), 50V, 0603. **Tolerance mismatch: page is ±10%, design calls for 5%.** Candidate, not a confirmed match on tolerance. |
| c10n | 10nF, C0G, 5%, ≥25V | GRM1885C1H103JA01D | muRata | C85973 | https://www.lcsc.com/product-detail/Multilayer-Ceramic-Capacitors-MLCC-SMD-SMT_Murata-Electronics-GRM1885C1H103JA01D_C85973.html | 98,960 | Yes — 10nF, C0G, ±5%, 50V, 0603 confirmed on page. |
| c1n | 1nF, C0G, 5%, ≥25V | CC0603FRNPO9BN102 | YAGEO | C309468 | https://www.lcsc.com/product-detail/C309468.html | 483,500 | Yes — 1nF, NP0 (=C0G), 50V, 0603 confirmed on page. Page states ±1% tolerance (tighter than the design's 5% requirement, so it satisfies it). |
| c100n | 100nF, X7R, ≥16V | CC0603KRX7R9BB104 | YAGEO | C14663 | https://www.lcsc.com/product-detail/C14663.html | 8,686,600 | Yes — 100nF, X7R, 50V ≥16V, 0603 confirmed on page. |
| c1u | 1µF, X7R, ≥10V | CC0805KKX7R8BB105 | YAGEO | C91186 | https://www.lcsc.com/product-detail/Multilayer-Ceramic-Capacitors-MLCC-SMD-SMT_1uF-105-10-25V_C91186.html | 880 | Yes on nominal/dielectric/voltage (1µF, X7R, 25V≥10V, 0805). The design's "effective >0.47µF" derated-capacitance requirement was **not checked** — no fetched page gave a DC-bias derating curve. |
| c10u | 10µF, X5R/X7R, ≥10V | CL21A106KAYNNNE | Samsung Electro-Mechanics | C15850 | https://www.lcsc.com/product-detail/C15850.html | 1,507,260 | Yes on nominal/dielectric/voltage (10µF, X5R, 25V≥10V, 0805). This catalog id (`c10u`) has an empty `source_ids` list in `catalog/components.json` — it is not currently wired to any BOM reference — recorded here for completeness since it is `identity_state: SPECIFICATION_ONLY`. Effective-capacitance derating not checked (same limitation as c1u). |

### Fuse, reference, connectors

| Catalog id | Spec | Candidate MPN | Manufacturer | LCSC | Source URL | Stock | Meets spec |
|---|---|---|---|---|---|---|---|
| fuse | 1206 PPTC, ≥500mA hold, ≥6V | 1206L050YR | Littelfuse | C163512 | https://lcsc.com/product-detail/Resettable-Fuses_Littelfuse-1206L050YR_C163512.html | 21,130 | Yes — 1206 package, 500mA hold, 6V rating confirmed on page. This is an exact hold-current/voltage match, not margin above spec; confirm against the design's actual inrush budget (out of scope here — see #8's G07 desk evidence) before treating it as sized correctly. |
| ref | REF3330AIDBZR (mpn known, jlc_code null) | REF3330AIDBZR | Texas Instruments | C140329 | https://www.lcsc.com/product-detail/C140329.html | 5,102 | Yes — exact MPN match confirmed by fetch (page states REF3330AIDBZR, TI, SOT-23, 3V, ±0.15%, 30ppm/°C max, matching the catalog's family specification facts). This resolves the catalog's existing note "LCSC C140329 found; JLC direct listing was not verified" — it is now verified against LCSC (not against a JLCPCB partdetail page specifically; JLCPCB mirrors LCSC stock for most parts but this was not independently fetched from jlcpcb.com for C140329). |
| socket20 | 1×20 female socket, 2.54mm, height TBD | — | — | — | — | — | **OPEN.** LCSC/JLC searches (via WebSearch and by probing likely product-detail URLs) returned only 2×20 (40-pin, dual-row) female header parts under the "2.54-2*20" naming family. No single-row 1×20 female socket page was found and fetched. Height is explicitly undefined in the design (`catalog/components.json`), so even a located candidate could not be confirmed against spec without that dimension. |
| header20 | 1×20 male header, 2.54mm, height TBD | — | — | — | — | — | **OPEN**, same reason as `socket20`: only 2×20 dual-row male headers were found; no confirmed 1×20 single-row page fetched, and height is undefined in the design regardless. |

## Fetch failures / access notes

- No page in this pass returned bot-protection/CAPTCHA/403 content — every
  `lcsc.com/product-detail/...` and the one `jlcpcb.com/partdetail/...` URL
  tried rendered real product data through WebFetch.
- The one confirmed failure mode was **`lcsc.com/search?...`**: it returns the
  static site shell (footer/nav) with no results grid, because the results
  are populated client-side by JavaScript that WebFetch's markdown conversion
  does not execute. No JLC/LCSC JSON search/autocomplete API endpoint was
  found that returns useful data over a plain GET (none was tried against an
  authenticated-looking endpoint, per the "no accounts/carts/orders" rule).
- Consequence: candidates were found by combining WebSearch (to locate
  plausible LCSC product-detail URLs already indexed by external search
  engines) with a direct WebFetch of each resulting URL to confirm the
  content. Rows where this two-step process produced no matching page
  (r249k, socket20, header20) are left `OPEN` rather than guessed.

## Summary

- 6 of 6 known listings rechecked; all reachable; `range` (SS14MDP2 /
  C6684954) reconfirmed at zero stock.
- 16 of 19 specification-only rows now have at least one cited, fetch-verified
  candidate (some with caveats noted above: `c470p` tolerance looser than
  spec, `c1u`/`c10u` effective-capacitance derating unchecked, `r10k`/`r100`
  candidates at zero stock, `fuse` sized exactly at spec with no margin
  checked).
- 3 rows stay `OPEN` with a stated reason: `r249k` (no LCSC page found for the
  known-to-exist YAGEO family member), `socket20`, `header20` (no confirmed
  1×20 single-row page found; height also undefined in the design either
  way).
- Gate G08 remains OPEN. Nothing here is an allocation, an order, a footprint
  qualification, or a factory-route decision — see `catalog/components.json`'s
  own `factory_order_approved: false` / `footprint_qualified: false` flags,
  which this evidence does not touch.

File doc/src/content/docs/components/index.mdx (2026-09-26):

---
# GENERATED by scripts/build_docs.py
title: "Component catalogue"
sidebar_position: 1
---

## Component-first reference

The table is generated from the component records. Exact identity, footprint qualification, factory acceptance and actual test evidence remain separate. No record represents a qualified PCB.

| Part | Function | Identity | CAD assets |
|---|---|---|---|
| [TLV9064IDR](/docs/components/records/tlv9064/) | Six quad amplifiers: two stages per input plus three ADC buffers and reference buffer | EXACT_MPN | 0 retained files |
| [74HC4067PW,118](/docs/components/records/mux/) | Separate signal, TIME and RANGE mux banks with shared four-bit address | EXACT_MPN | 0 retained files |
| [TLV75533PDBVR](/docs/components/records/ldo/) | Separate analog 3.3 V regulator | EXACT_MPN | 0 retained files |
| [REF3330AIDBZR](/docs/components/records/ref/) | 3.0 V reference buffered by U6D | EXACT_MPN | 0 retained files |
| [BAV199,215](/docs/components/records/clamp/) | Low-leakage input clamp support | EXACT_MPN | 0 retained files |
| [Raspberry Pi Pico H](/docs/components/records/pico-h/) | Socketed RP2040 module with factory-populated headers and USB | EXACT_MPN | 0 retained files |
| [Pico-ResTouch-LCD-3.5 (SKU 19907)](/docs/components/records/display/) | Single display with ten panes; touch and SD unused | EXACT_MPN | 0 retained files |
| [SS14MDP2](/docs/components/records/range/) | Three maintained display range positions | EXACT_MPN | 0 retained files |
| [RK09L1140A5L](/docs/components/records/pot/) | Ten independent TIME controls | EXACT_MPN | 17 retained files |
| [PJ-313 5JCJ](/docs/components/records/jack/) | Ten unbalanced TS signal inputs | EXACT_MPN | 1 retained files |
| [TS-1088-AR02016](/docs/components/records/button/) | HOLD and LINK push buttons | EXACT_MPN | 1 retained files |
| [socket20](/docs/components/records/socket20/) | Two 1x20 female sockets for Pico H | SPECIFICATION_ONLY | 0 retained files |
| [header20](/docs/components/records/header20/) | Two 1x20 male rows for display; physical Pico numbering | SPECIFICATION_ONLY | 0 retained files |
| [1206L050YR](/docs/components/records/fuse/) | Analog/display branch protection | SPECIFICATION_ONLY | 0 retained files |
| [RT0603BRD071ML](/docs/components/records/r1m/) | input impedance/current limit | SPECIFICATION_ONLY | 0 retained files |
| [RT0603BRD07200KL](/docs/components/records/r200k/) | bias divider | SPECIFICATION_ONLY | 0 retained files |
| [r249k](/docs/components/records/r249k/) | bias divider | SPECIFICATION_ONLY | 0 retained files |
| [HoLTT0603-1/10W-4.7K-1%](/docs/components/records/r4k7/) | second filter | SPECIFICATION_ONLY | 0 retained files |
| [0603WAF1002T5E](/docs/components/records/r10k/) | switch ladder, pulls | SPECIFICATION_ONLY | 0 retained files |
| [0603WAF1003T5E](/docs/components/records/r100k/) | digital/default pulls | SPECIFICATION_ONLY | 0 retained files |
| [0603 ±1% 100Ω (VO)](/docs/components/records/r100/) | ADC isolation | SPECIFICATION_ONLY | 0 retained files |
| [0603WAF1001T5E](/docs/components/records/r1k/) | control isolation/rail bleed | SPECIFICATION_ONLY | 0 retained files |
| [RC0603FR-0733RL](/docs/components/records/r33/) | SPI source termination | SPECIFICATION_ONLY | 0 retained files |
| [06035A471KAT2A](/docs/components/records/c470p/) | input filter | SPECIFICATION_ONLY | 0 retained files |
| [GRM1885C1H103JA01D](/docs/components/records/c10n/) | filter | SPECIFICATION_ONLY | 0 retained files |
| [CC0603FRNPO9BN102](/docs/components/records/c1n/) | ADC bucket | SPECIFICATION_ONLY | 0 retained files |
| [CC0603KRX7R9BB104](/docs/components/records/c100n/) | local decoupling | SPECIFICATION_ONLY | 0 retained files |
| [CC0805KKX7R8BB105](/docs/components/records/c1u/) | regulator/reference decoupling | SPECIFICATION_ONLY | 0 retained files |
| [CL21A106KAYNNNE](/docs/components/records/c10u/) | branch bulk | SPECIFICATION_ONLY | 0 retained files |
| [nmos-ll](/docs/components/records/nmos-ll/) | GP13 backlight open-drain stage (#41): N-channel logic-level MOSFET between the module's LCD_BL / CAT1 EN node and GND so the RP2040 pad never sees the module's 10k pull-up to VSYS | SPECIFICATION_ONLY | 0 retained files |
| [testpoint](/docs/components/records/testpoint/) | Factory test access | SPECIFICATION_ONLY | 0 retained files |

## Working views

[UI simulation](/prototype/index.html) · [Panel study](/assets/panel-study.svg) · [Architecture drawing](/assets/architecture.svg) · [Original pot 3D](/models/index.html).

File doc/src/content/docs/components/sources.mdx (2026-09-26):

---
# GENERATED by scripts/build_docs.py
title: "Source manifest and availability"
sidebar_position: 99
---

## Retrieval status

Files not present remain absent; source URLs are not proof of binary retention. New local downloads require review.

### Lamp component-first documentation

[https://github.com/Takazudo/zudo-led-lamp/blob/main/doc/CLAUDE.md](https://github.com/Takazudo/zudo-led-lamp/blob/main/doc/CLAUDE.md)

**read_online** — Repository read; SHA fb9e529e31e2540a0122bddd3d87fe7250ccfd8e.

### create-zudo-doc usage

[https://github.com/zudolab/zudo-doc/blob/main/packages/create-zudo-doc/README.md](https://github.com/zudolab/zudo-doc/blob/main/packages/create-zudo-doc/README.md)

**read_online** — Repository read; SHA 5a48acfe84aebe153c1814134fe4fadc9b23faba.

### Waveshare SKU 19907

[https://www.waveshare.com/Pico-ResTouch-LCD-3.5.htm](https://www.waveshare.com/Pico-ResTouch-LCD-3.5.htm)

**read_online** — Manufacturer page: 480x320, 5 V, installed female Pico headers, 86x57.2 mm module.

### Waveshare interface and resources

[https://www.waveshare.net/wiki/Pico-ResTouch-LCD-3.5](https://www.waveshare.net/wiki/Pico-ResTouch-LCD-3.5)

**read_online** — Manufacturer pin assignment table and 16-bit parallel-to-SPI bridge explanation; RGB565.

### Waveshare module schematic

[https://files.waveshare.com/upload/8/85/Pico-ResTouch-LCD-3.5_Sch.pdf](https://files.waveshare.com/upload/8/85/Pico-ResTouch-LCD-3.5_Sch.pdf)

**read_online** — Parsed online. Page-image retrieval failed. Module regulator straps and power connections require visual verification locally.

### Waveshare module CAD archive

[https://files.waveshare.com/upload/e/e4/Pico-ResTouch-LCD-3_5.zip](https://files.waveshare.com/upload/e/e4/Pico-ResTouch-LCD-3_5.zip)

**download_unavailable** — Official link; binary download failed in this environment. NOT included.

### Waveshare example code

[https://files.waveshare.com/upload/f/fc/Pico-ResTouch-LCD-X_X_Code.zip](https://files.waveshare.com/upload/f/fc/Pico-ResTouch-LCD-X_X_Code.zip)

**download_unavailable** — Official link; binary download failed. Vendor driver integration remains open; do not use generic ILI9488 serial driver.

### Raspberry Pi Pico / Pico H

[https://www.raspberrypi.com/products/raspberry-pi-pico/](https://www.raspberrypi.com/products/raspberry-pi-pico/)

**read_online** — Manufacturer product page. Order H version with installed headers, not an unsoldered Pico.

### Pico pinout

[https://datasheets.raspberrypi.com/pico/Pico-R3-A4-Pinout.pdf](https://datasheets.raspberrypi.com/pico/Pico-R3-A4-Pinout.pdf)

**read_online** — Pinout inspected online as page image. Same header numbering used for both carrier interfaces.

### Pico datasheet

[https://datasheets.raspberrypi.com/pico/pico-datasheet.pdf](https://datasheets.raspberrypi.com/pico/pico-datasheet.pdf)

**download_unavailable** — Local download required for module dimensions, VBUS limits, ADC supply and power sequencing review.

### Pico SDK ADC documentation

[https://www.raspberrypi.com/documentation/pico-sdk/hardware.html](https://www.raspberrypi.com/documentation/pico-sdk/hardware.html)

**read_online** — RP2040: 12-bit ADC, 500 ksample/s aggregate; 8.7 ENOB. Sequential channels, not simultaneous sample-and-hold.

### TI TLV906x datasheet

[https://www.ti.com/lit/ds/symlink/tlv9064.pdf](https://www.ti.com/lit/ds/symlink/tlv9064.pdf)

**read_online** — D/SOIC14 pin diagram visually inspected; 1.8-5.5 V, RRIO, unity stable; overload-current limiting discussion. Parsed version N vs cached figure version M recorded: reacquire one consistent revision before release.

### Nexperia 74HC/HCT4067 datasheet

[https://assets.nexperia.com/documents/data-sheet/74HC_HCT4067.pdf](https://assets.nexperia.com/documents/data-sheet/74HC_HCT4067.pdf)

**read_online** — PW/TSSOP24 pin diagram visually inspected; HC part selected, not HCT.

### TI TLV755P datasheet

[https://www.ti.com/lit/ds/symlink/tlv755p.pdf](https://www.ti.com/lit/ds/symlink/tlv755p.pdf)

**read_online** — DBV pin table parsed; ratings page visually inspected. 5.5 V recommended maximum input, 6 V absolute maximum.

### TI REF33 datasheet

[https://www.ti.com/lit/ds/symlink/ref33.pdf](https://www.ti.com/lit/ds/symlink/ref33.pdf)

**read_online** — DBZ/SOT23 pin table parsed: 1 IN, 2 OUT, 3 GND. Pin diagram screenshot unavailable; independent visual check open.

### Nexperia BAV199 datasheet

[https://assets.nexperia.com/documents/data-sheet/BAV199.pdf](https://assets.nexperia.com/documents/data-sheet/BAV199.pdf)

**read_online** — Pin diagram visually inspected: 1 A1, 2 K2, 3 K1/A2. Low-leakage silicon, NOT Schottky.

### ALPS RK09L1140A5L

[https://tech.alpsalpine.com/e/products/detail/RK09L1140A5L/](https://tech.alpsalpine.com/e/products/detail/RK09L1140A5L/)

**read_online** — 10k linear, 15mm flat shaft. Detailed original CAD/drawings imported from previous user-supplied archive; permissions retained.

### NKK SS14MDP2

[https://www.nkkswitches.eu/products/Slides/Slides%20SS/SS14MDP2/](https://www.nkkswitches.eu/products/Slides/Slides%20SS/SS14MDP2/)

**read_online** — Exact SP3T On-On-On, top-actuated, straight PC terminals, non-shorting. Numerical terminal map and mounting drawing NOT acquired.

### JLC NKK SS14MDP2

[https://jlcpcb.com/partdetail/NKKSwitches-SS14MDP2/C6684954](https://jlcpcb.com/partdetail/NKKSwitches-SS14MDP2/C6684954)

**read_online** — Listing exists; observed zero stock. This is a pre-order/external sourcing candidate, not allocated inventory.

### NKK SS14MDP2 contact finish

[https://www.nkkswitches.eu/products/Slides/Slides%20SS/SS14MDP2/](https://www.nkkswitches.eu/products/Slides/Slides%20SS/SS14MDP2/)

**read_online** — Re-fetched 2026-09-26 for #27/#38. General Specifications table states "Contact Finish: Silver Plating" -- confirms the switch is silver-contact, not gold.

### NKK Electrical Ratings, page Z33 (dry-circuit contact material)

[https://www.nkkswitches.eu/documents/products/support/electricalratings.pdf](https://www.nkkswitches.eu/documents/products/support/electricalratings.pdf)

**read_online** — Fetched and read 2026-09-26 for #27/#38 (PDF page 3 of this document, printed page Z33). Quoted: "Low Level ~ 0.4VA maximum @ 28V AC or DC maximum ... Gold plated contacts are recommended for dry circuits ... In circuits where the voltage is below 28 volts DC and current is below 100 milliamps (dry circuits), no arc develops ... Power Level ~ 100mA to 10 amps @ 125V AC ... Silver contacts are recommended for electrical levels above 0.4VA ... In circuits where the voltage is above about 12 volts DC and the current above .5 amps, an arc develops ... This arc keeps the oxidation cleaned off."

### NKK engineering: electrical (operating-range dry-circuit guidance)

[https://www.nkkswitches.eu/engineering/electrical.html](https://www.nkkswitches.eu/engineering/electrical.html)

**read_online** — Fetched and read 2026-09-26 for #27/#38. Quoted: "Gold plated contacts are recommended for dry circuits, which are defined as very low energy. In circuits where the voltage is below 28 volts DC and current is below 100 milliamps (dry circuits), no arc develops as the contacts open or close." Restates the page Z33 guidance in range-z33.

### Cost-down display HS35B01A

[https://jlcpcb.com/partdetail/HS-HS35B01A/C19632787](https://jlcpcb.com/partdetail/HS-HS35B01A/C19632787)

**read_online** — Listing exists; interface, header and model unresolved. Earlier $8.72 suggestion is superseded for P0. Observed 1pc price $9.2646, not a board quote.

### JLC assembly capabilities

[https://jlcpcb.com/capabilities/pcb-assembly-capabilities](https://jlcpcb.com/capabilities/pcb-assembly-capabilities)

**read_online** — Policy must be rechecked at quote; mixed SMD/through-hole required.

### JLC global sourcing

[https://jlcpcb.com/help/article/how-to-use-jlcpcb-global-sourcing-parts-service](https://jlcpcb.com/help/article/how-to-use-jlcpcb-global-sourcing-parts-service)

**read_online** — Service route, not acceptance of this exact board or component.

### JLC consignment

[https://jlcpcb.com/help/article/how-to-consign-parts-to-jlcpcb](https://jlcpcb.com/help/article/how-to-consign-parts-to-jlcpcb)

**read_online** — Only arrange shipment after part/process approval. No part or order submitted in this project.

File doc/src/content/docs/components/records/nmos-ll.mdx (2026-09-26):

---
# GENERATED by scripts/build_docs.py
title: "nmos-ll / supplier selection open"
sidebar_position: 30
---

## Identity

| Field | Value |
|---|---|
| Record | nmos-ll |
| Manufacturer | UNSELECTED |
| Orderable identity | NOT SELECTED |
| JLC/LCSC | NOT VERIFIED / NOT APPLICABLE |
| Package | small-signal SMD (SOT-23 class expected); exact package follows the part chosen at G08 |
| Identity | SPECIFICATION_ONLY |
| Fit | PROPOSED_NOT_ASSEMBLED |
| References | Q1 |
| Footprint candidate | NOT ASSIGNED |

## Intended function

GP13 backlight open-drain stage (#41): N-channel logic-level MOSFET between the module's LCD_BL / CAT1 EN node and GND so the RP2040 pad never sees the module's 10k pull-up to VSYS

## Recorded findings

Generic record with NO manufacturer part, LCSC code or footprint: the numbers below are this design's requirements for the part to be selected at G08, not a datasheet of a chosen device. Pin numbers 1/2/3 are logical (GATE/SOURCE/DRAIN) and do not assert any package pinout; the exact part's pin assignment is applied when its footprint is drawn.

Requirement: logic-level gate. Vgs(th) maximum well below the RP2040 minimum V_OH at IOVDD 3.3 V, and a datasheet Rds(on) specification at Vgs = 2.5 V (or lower) so the on-state is guaranteed from a 3.3 V GPIO with margin, not inferred from a 4.5 V / 10 V curve.

Requirement: Vds rating &gt;= 20 V (drain sits at the module's VSYS, USB 4.75-5.25 V, when off); Vgs rating &gt;= +/-8 V; continuous Id &gt;= 10 mA. The on-state current is only (VSYS / module R16 10k) &lt;= 0.53 mA, so dissipation is negligible; Rds(on) &lt;= 10 ohm at Vgs = 2.5 V keeps the on-state LCD_BL node below 10 mV.

Requirement: gate leakage Igss &lt;= 1 uA at the rated Vgs, so the 100k gate pull-down (R88) holds the gate below 0.1 V when GP13 is undriven.

Behaviour on the carrier (design/evidence/backlight-interface.md): gate low (reset, BOOTSEL, undriven, or GP13 driven low) = MOSFET off = LCD_BL pulled to VSYS by module R16 = backlight ON. GP13 driven high = MOSFET on = LCD_BL near 0 V = backlight OFF. Enable polarity as seen by firmware is therefore inverted (active-low backlight).

## Pin map

Pin assignments below are electrical evidence or explicitly logical placeholders. They are not footprint qualification.

| Pin | Function |
|---|---|
| 1 | GATE |
| 2 | SOURCE |
| 3 | DRAIN |

## Documents and models

No original model or source binary was recovered for this record in this package. See the sources and the local download manifest; no nominal model is presented as an exact replacement.

## Coverage and unresolved questions

**Footprint independently qualified: NO. Factory order approved: NO. Bench result: NOT TESTED.**

- G08: select a real, maintained logic-level N-channel MOSFET meeting the requirements above, record its MPN/LCSC page and datasheet, and only then assign a footprint. Do not infer the pinout from a generic SOT-23 drawing.
- Rds(on) at Vgs = 2.5 V, Vgs(th) max and Igss must be read from the selected part's datasheet; none of these values is established here.
- The module CAT1 backlight regulator's EN thresholds are unknown (design/evidence/module-power.json backlight-regulator-en-thresholds); the off-state relies only on LCD_BL being pulled to a few millivolts, the on-state on the module's own R16 behaviour.

The presence of a part number, datasheet or model closes none of these remaining gates automatically.

## Sources

Values and package constraints are authored design requirements, not manufacturer-verified specifications of a selected orderable part. Select the exact item and add its evidence before placement.

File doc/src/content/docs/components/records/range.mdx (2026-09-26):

---
# GENERATED by scripts/build_docs.py
title: "SS14MDP2"
sidebar_position: 8
---

## Identity

| Field | Value |
|---|---|
| Record | range |
| Manufacturer | NKK Switches |
| Orderable identity | SS14MDP2 |
| JLC/LCSC | C6684954 |
| Package | Through-hole SP3T |
| Identity | EXACT_MPN |
| Fit | PROPOSED_NOT_ASSEMBLED |
| References | SW1 SW2 SW3 SW4 SW5 SW6 SW7 SW8 SW9 SW10 |
| Footprint candidate | NOT ASSIGNED |
| Contact material | silver (NKK product page General Specifications: "Contact Finish: Silver Plating") |
| Application suitability | OPEN_REQUIRES_MANUFACTURER_CONFIRMATION_AND_QUALIFICATION |

## Intended function

Three maintained display range positions

## Recorded findings

Manufacturer states SP3T On-On-On, top actuation, straight PC terminals, break-before-make.

Listing showed zero stock; price is not an availability guarantee.

Terminal spacing code D (0.100 in): single row 1-2-3 at 2.54 mm, 3-4 at 5.08 mm; recommended PCB hole (0.8) dia; terminal section (0.4) x (0.6) mm.

Body (15.8) x (4.0) mm, (4.5) mm high; terminals (3.0) mm below body per H48 ((3.4) in H47 isometric; conflict unresolved); actuator (1.2) x (1.5) mm protruding (2.0) mm above body; (2.0) mm travel per step. Actuator top about 6.5 mm above PCB (derived). All reference dims, no tolerances.

Terminal 3 lies on the body and actuator centreline (centre marks, not toleranced). Four corner standoff bosses on the underside; no PCB mounting pegs.

Contact material is silver, not gold: the NKK product page's General Specifications table states "Contact Finish: Silver Plating" (source range-contact-finish).

NKK Electrical Ratings page Z33 (source range-z33) defines Low Level / dry circuits as &lt;=0.4 VA at &lt;=28 V AC or DC max, and recommends gold-plated contacts there because no arc forms to break down tarnish; it recommends silver for Power Level (~100 mA-10 A @125 V AC), stating an arc only develops above about 12 VDC / 0.5 A, which is what keeps a silver contact's oxidation cleaned off. The companion operating-range page (source range-operating-range) restates the same gold-for-dry-circuit recommendation.

Actual sense path (scripts/make_design.py ~47-49): switch COMMON -&gt; 1 k-ohm -&gt; 100 nF -&gt; mux/buffer. For a full 0&lt;-&gt;3.3 V throw: initial capacitor current = 3.3 V / 1 k-ohm = 3.3 mA; RC time constant tau = 1 k-ohm x 100 nF = 100 microseconds. Current then decays to leakage/input-bias current; the centre throw additionally sources through the R40/R41 divider, about 5 k-ohm source impedance. There is no continuous wetting current. The manufacturer's 100 mA / 30 V maximum rating is a ceiling, not evidence that this near-zero-current dry circuit is a suitable application for a silver contact.

## Pin map

Pin assignments below are electrical evidence or explicitly logical placeholders. They are not footprint qualification.

| Pin | Function |
|---|---|
| 1 | THROW_LEFT |
| 2 | THROW_CENTER |
| 3 | COMMON |
| 4 | THROW_RIGHT |

## Documents and models

No original model or source binary was recovered for this record in this package. See the sources and the local download manifest; no nominal model is presented as an exact replacement.

## Coverage and unresolved questions

**Footprint independently qualified: NO. Factory order approved: NO. Bench result: NOT TESTED.**

- STOP: pad geometry and 2 mm lever/panel access are not qualified; numeric terminal map resolved from NKK catalogue H46/H47, still needs a drawn footprint and real-part fit check.
- OPEN: terminal 2/3 (M/C) mapping is a vendor fact (C-&gt;3 is COM, M-&gt;2); terminal 1/4 (L/H) follows NKK Left/Right naming but the panel-legend direction is a layout decision, not yet confirmed. Swap to L-&gt;4 / H-&gt;1 if the panel reads the other way at layout.
- OPEN_REQUIRES_MANUFACTURER_CONFIRMATION_AND_QUALIFICATION (#27/#38): SS14MDP2's silver contacts sit in a near-zero-current dry sense circuit (3.3 mA initial transient decaying in ~100 us to leakage/bias current, no continuous wetting current) that NKK's own page Z33 describes as the case gold contacts are recommended for. Not substituted under the decided option (#27 option 2): keep SS14MDP2, do not invent a substitute MPN. Before this switch is approved for this application: get NKK's specific confirmation for this exact load, and run application-level qualification (contact-resistance measurement at the actual load, a cycling/durability run, and an environmental/cleaning exposure check per the factory process) beyond initial continuity. See design/evidence/range-contact.md. A maintained break-before-make SP3T with manufacturer-supported dry-circuit (e.g. gold) contacts remains a listed OPEN alternative, not a decision -- any real substitute needs its own exact pin map, footprint, actuator-height and factory-process review.
- Cleaning process not process sealed (hand clean locally, NKK H44); price/lead time via RFQ.

The presence of a part number, datasheet or model closes none of these remaining gates automatically.

## Sources

### NKK SS14MDP2

[https://www.nkkswitches.eu/products/Slides/Slides%20SS/SS14MDP2/](https://www.nkkswitches.eu/products/Slides/Slides%20SS/SS14MDP2/)

Evidence state: `read_online`. Exact SP3T On-On-On, top-actuated, straight PC terminals, non-shorting. Numerical terminal map and mounting drawing NOT acquired.

### JLC NKK SS14MDP2

[https://jlcpcb.com/partdetail/NKKSwitches-SS14MDP2/C6684954](https://jlcpcb.com/partdetail/NKKSwitches-SS14MDP2/C6684954)

Evidence state: `read_online`. Listing exists; observed zero stock. This is a pre-order/external sourcing candidate, not allocated inventory.

### NKK SS14MDP2 contact finish

[https://www.nkkswitches.eu/products/Slides/Slides%20SS/SS14MDP2/](https://www.nkkswitches.eu/products/Slides/Slides%20SS/SS14MDP2/)

Evidence state: `read_online`. Re-fetched 2026-09-26 for #27/#38. General Specifications table states "Contact Finish: Silver Plating" -- confirms the switch is silver-contact, not gold.

### NKK Electrical Ratings, page Z33 (dry-circuit contact material)

[https://www.nkkswitches.eu/documents/products/support/electricalratings.pdf](https://www.nkkswitches.eu/documents/products/support/electricalratings.pdf)

Evidence state: `read_online`. Fetched and read 2026-09-26 for #27/#38 (PDF page 3 of this document, printed page Z33). Quoted: "Low Level ~ 0.4VA maximum @ 28V AC or DC maximum ... Gold plated contacts are recommended for dry circuits ... In circuits where the voltage is below 28 volts DC and current is below 100 milliamps (dry circuits), no arc develops ... Power Level ~ 100mA to 10 amps @ 125V AC ... Silver contacts are recommended for electrical levels above 0.4VA ... In circuits where the voltage is above about 12 volts DC and the current above .5 amps, an arc develops ... This arc keeps the oxidation cleaned off."

### NKK engineering: electrical (operating-range dry-circuit guidance)

[https://www.nkkswitches.eu/engineering/electrical.html](https://www.nkkswitches.eu/engineering/electrical.html)

Evidence state: `read_online`. Fetched and read 2026-09-26 for #27/#38. Quoted: "Gold plated contacts are recommended for dry circuits, which are defined as very low energy. In circuits where the voltage is below 28 volts DC and current is below 100 milliamps (dry circuits), no arc develops as the contacts open or close." Restates the page Z33 guidance in range-z33.

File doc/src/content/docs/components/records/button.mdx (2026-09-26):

---
# GENERATED by scripts/build_docs.py
title: "TS-1088-AR02016"
sidebar_position: 11
---

## Identity

| Field | Value |
|---|---|
| Record | button |
| Manufacturer | XUNPU |
| Orderable identity | TS-1088-AR02016 |
| JLC/LCSC | C720477 |
| Package | Vertical/top push; round black actuator; no bracket;1.6N operating force. Tiny switch is not a velocity-sensitive pad or an adequately sized finger key on its own. |
| Identity | EXACT_MPN |
| Fit | PROPOSED_NOT_ASSEMBLED |
| References | SW11 SW12 |
| Footprint candidate | ZudoScope10:SW_XUNPU_TS1088_AR02016_REVIEW |

## Intended function

HOLD and LINK push buttons

## Recorded findings

Vertical/top push; round black actuator; no bracket;1.6N operating force. Tiny switch is not a velocity-sensitive pad or an adequately sized finger key on its own.

Retained XUNPU drawing visually inspected: two SMT contact terminals numbered 1 and 2; normally open. Body 3.9 x 3.0 mm; recommended pad outside span 5.50 mm and inside gap 3.40 mm, pad height 2.00 mm.

Variant code AR02016 = A stainless dome, R no locating post, 020 = H 2.0 mm actuator top above seating plane, 16 = 160 gf.

Exactly two terminals (1 left, 2 right in top view), single NO contact; no internally joined terminal pairs. Terminals 1.30 wide spanning 5.00; actuator dia 1.80; body height 1.50.

Recommended pads 5.50 outside / 3.40 inside / 2.00 high =&gt; 1.05 x 2.00 at +/-2.225; ZudoScope10:SW_XUNPU_TS1088_AR02016_REVIEW matches pad-for-pad (pad 1 at -2.225).

## Pin map

Pin assignments below are electrical evidence or explicitly logical placeholders. They are not footprint qualification.

| Pin | Function |
|---|---|
| 1 | NO_CONTACT_1 |
| 2 | NO_CONTACT_2 |

## Documents and models

[TS-1088-AR02016.pdf](/assets/reference/assets/button/TS-1088-AR02016.pdf) — pdf; applicability: family_drawing_with_exact_variant_ordering_fields.

Source: [https://datasheet.lcsc.com/datasheet/pdf/0475ac02febf455ca9ddcfb380b0df0d.pdf?productCode=C720477](https://datasheet.lcsc.com/datasheet/pdf/0475ac02febf455ca9ddcfb380b0df0d.pdf?productCode=C720477)

SHA-256: `368d4cc2c26b08cb63e1b67193f671d0860b6d3fb2e6b9f2696ffade401afc30`.

## Coverage and unresolved questions

**Footprint independently qualified: NO. Factory order approved: NO. Bench result: NOT TESTED.**

- Pads and pin identity verified against drawing; remaining: real-part fit, panel/cap reach to a 2.0 mm actuator.

The presence of a part number, datasheet or model closes none of these remaining gates automatically.

## Sources

Values and package constraints are authored design requirements, not manufacturer-verified specifications of a selected orderable part. Select the exact item and add its evidence before placement.

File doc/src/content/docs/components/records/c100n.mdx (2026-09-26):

---
# GENERATED by scripts/build_docs.py
title: "CC0603KRX7R9BB104"
sidebar_position: 27
---

## Identity

| Field | Value |
|---|---|
| Record | c100n |
| Manufacturer | YAGEO |
| Orderable identity | CC0603KRX7R9BB104 |
| JLC/LCSC | C14663 |
| Package | 0603 |
| Identity | SPECIFICATION_ONLY |
| Fit | PROPOSED_NOT_ASSEMBLED |
| References | C1 C2 C3 C4 C5 C1111 C1112 C1121 C1122 C1131 C1132 C1141 C1142 C1151 C1152 C1161 C1162 C1171 C1172 C1181 C1182 C1191 C1192 C1201 C1202 C51 C52 C7 C8 C9 C6 C33 |
| Footprint candidate | Capacitor_SMD:C_0603_1608Metric |

## Intended function

local decoupling

## Recorded findings

100nF; X7R &gt;=16 V. Value specified by this design; not an exact orderable.

G08 candidate: LCSC C14663 (https://www.lcsc.com/product-detail/C14663.html), checked 2026-09-26, meets spec, stock 8686600. listing_not_allocation: a page listing is not allocated stock or an order.

## Pin map

Pin assignments below are electrical evidence or explicitly logical placeholders. They are not footprint qualification.

| Pin | Function |
|---|---|
| 1 | P1 |
| 2 | P2 |

## Documents and models

No original model or source binary was recovered for this record in this package. See the sources and the local download manifest; no nominal model is presented as an exact replacement.

## Coverage and unresolved questions

**Footprint independently qualified: NO. Factory order approved: NO. Bench result: NOT TESTED.**

- RFQ/allocate stock before fabrication; listing is not an order.

The presence of a part number, datasheet or model closes none of these remaining gates automatically.

## Sources

Values and package constraints are authored design requirements, not manufacturer-verified specifications of a selected orderable part. Select the exact item and add its evidence before placement.

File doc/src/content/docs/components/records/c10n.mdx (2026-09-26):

---
# GENERATED by scripts/build_docs.py
title: "GRM1885C1H103JA01D"
sidebar_position: 25
---

## Identity

| Field | Value |
|---|---|
| Record | c10n |
| Manufacturer | muRata |
| Orderable identity | GRM1885C1H103JA01D |
| JLC/LCSC | C85973 |
| Package | 0603 |
| Identity | SPECIFICATION_ONLY |
| Fit | PROPOSED_NOT_ASSEMBLED |
| References | C102 C202 C302 C402 C502 C602 C702 C802 C902 C1002 |
| Footprint candidate | Capacitor_SMD:C_0603_1608Metric |

## Intended function

filter

## Recorded findings

10nF; C0G 5% &gt;=25 V. Value specified by this design; not an exact orderable.

G08 candidate: LCSC C85973 (https://www.lcsc.com/product-detail/Multilayer-Ceramic-Capacitors-MLCC-SMD-SMT_Murata-Electronics-GRM1885C1H103JA01D_C85973.html), checked 2026-09-26, meets spec, stock 98960. listing_not_allocation: a page listing is not allocated stock or an order.

## Pin map

Pin assignments below are electrical evidence or explicitly logical placeholders. They are not footprint qualification.

| Pin | Function |
|---|---|
| 1 | P1 |
| 2 | P2 |

## Documents and models

No original model or source binary was recovered for this record in this package. See the sources and the local download manifest; no nominal model is presented as an exact replacement.

## Coverage and unresolved questions

**Footprint independently qualified: NO. Factory order approved: NO. Bench result: NOT TESTED.**

- RFQ/allocate stock before fabrication; listing is not an order.

The presence of a part number, datasheet or model closes none of these remaining gates automatically.

## Sources

Values and package constraints are authored design requirements, not manufacturer-verified specifications of a selected orderable part. Select the exact item and add its evidence before placement.

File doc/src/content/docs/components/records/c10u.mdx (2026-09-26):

---
# GENERATED by scripts/build_docs.py
title: "CL21A106KAYNNNE"
sidebar_position: 29
---

## Identity

| Field | Value |
|---|---|
| Record | c10u |
| Manufacturer | Samsung Electro-Mechanics |
| Orderable identity | CL21A106KAYNNNE |
| JLC/LCSC | C15850 |
| Package | 0805 |
| Identity | SPECIFICATION_ONLY |
| Fit | PROPOSED_NOT_ASSEMBLED |
| References | Not fitted in P0 |
| Footprint candidate | Capacitor_SMD:C_0805_2012Metric |

## Intended function

branch bulk

## Recorded findings

10uF; X5R/X7R &gt;=10 V; verify effective capacitance. Value specified by this design; not an exact orderable.

Not currently wired to any BOM reference (record has empty source_ids and no ref in design/circuit.json); recorded for completeness since identity_state is SPECIFICATION_ONLY.

G08 candidate: LCSC C15850 (https://www.lcsc.com/product-detail/C15850.html), checked 2026-09-26, meets spec, stock 1507260. listing_not_allocation: a page listing is not allocated stock or an order.

## Pin map

Pin assignments below are electrical evidence or explicitly logical placeholders. They are not footprint qualification.

| Pin | Function |
|---|---|
| 1 | P1 |
| 2 | P2 |

## Documents and models

No original model or source binary was recovered for this record in this package. See the sources and the local download manifest; no nominal model is presented as an exact replacement.

## Coverage and unresolved questions

**Footprint independently qualified: NO. Factory order approved: NO. Bench result: NOT TESTED.**

- OPEN: effective-capacitance derating not checked. RFQ/allocate stock and confirm this record is actually needed before fabrication.

The presence of a part number, datasheet or model closes none of these remaining gates automatically.

## Sources

Values and package constraints are authored design requirements, not manufacturer-verified specifications of a selected orderable part. Select the exact item and add its evidence before placement.

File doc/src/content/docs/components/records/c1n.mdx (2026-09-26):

---
# GENERATED by scripts/build_docs.py
title: "CC0603FRNPO9BN102"
sidebar_position: 26
---

## Identity

| Field | Value |
|---|---|
| Record | c1n |
| Manufacturer | YAGEO |
| Orderable identity | CC0603FRNPO9BN102 |
| JLC/LCSC | C309468 |
| Package | 0603 |
| Identity | SPECIFICATION_ONLY |
| Fit | PROPOSED_NOT_ASSEMBLED |
| References | C20 C21 C22 |
| Footprint candidate | Capacitor_SMD:C_0603_1608Metric |

## Intended function

ADC bucket

## Recorded findings

1nF; C0G 5% &gt;=25 V. Value specified by this design; not an exact orderable.

G08 candidate: LCSC C309468 (https://www.lcsc.com/product-detail/C309468.html), checked 2026-09-26, meets spec, stock 483500. Page dielectric label is NP0 (equivalent to C0G); tolerance +/-1%, tighter than the design's 5% requirement. listing_not_allocation: a page listing is not allocated stock or an order.

## Pin map

Pin assignments below are electrical evidence or explicitly logical placeholders. They are not footprint qualification.

| Pin | Function |
|---|---|
| 1 | P1 |
| 2 | P2 |

## Documents and models

No original model or source binary was recovered for this record in this package. See the sources and the local download manifest; no nominal model is presented as an exact replacement.

## Coverage and unresolved questions

**Footprint independently qualified: NO. Factory order approved: NO. Bench result: NOT TESTED.**

- RFQ/allocate stock before fabrication; listing is not an order.

The presence of a part number, datasheet or model closes none of these remaining gates automatically.

## Sources

Values and package constraints are authored design requirements, not manufacturer-verified specifications of a selected orderable part. Select the exact item and add its evidence before placement.

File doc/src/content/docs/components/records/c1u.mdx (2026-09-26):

---
# GENERATED by scripts/build_docs.py
title: "CC0805KKX7R8BB105"
sidebar_position: 28
---

## Identity

| Field | Value |
|---|---|
| Record | c1u |
| Manufacturer | YAGEO |
| Orderable identity | CC0805KKX7R8BB105 |
| JLC/LCSC | C91186 |
| Package | 0805 |
| Identity | SPECIFICATION_ONLY |
| Fit | PROPOSED_NOT_ASSEMBLED |
| References | C30 C31 C32 |
| Footprint candidate | Capacitor_SMD:C_0805_2012Metric |

## Intended function

regulator/reference decoupling

## Recorded findings

1uF; X7R &gt;=10 V; effective &gt;0.47uF. Value specified by this design; not an exact orderable.

G08 candidate: LCSC C91186 (https://www.lcsc.com/product-detail/Multilayer-Ceramic-Capacitors-MLCC-SMD-SMT_1uF-105-10-25V_C91186.html), checked 2026-09-26, nominal/dielectric/voltage confirmed (1uF, X7R, 25V, 0805), stock 880. listing_not_allocation: a page listing is not allocated stock or an order.

## Pin map

Pin assignments below are electrical evidence or explicitly logical placeholders. They are not footprint qualification.

| Pin | Function |
|---|---|
| 1 | P1 |
| 2 | P2 |

## Documents and models

No original model or source binary was recovered for this record in this package. See the sources and the local download manifest; no nominal model is presented as an exact replacement.

## Coverage and unresolved questions

**Footprint independently qualified: NO. Factory order approved: NO. Bench result: NOT TESTED.**

- OPEN: the effective-&gt;0.47uF DC-bias-derating requirement was NOT checked against this candidate; no fetched page gave a derating curve. RFQ/allocate stock before fabrication.

The presence of a part number, datasheet or model closes none of these remaining gates automatically.

## Sources

Values and package constraints are authored design requirements, not manufacturer-verified specifications of a selected orderable part. Select the exact item and add its evidence before placement.

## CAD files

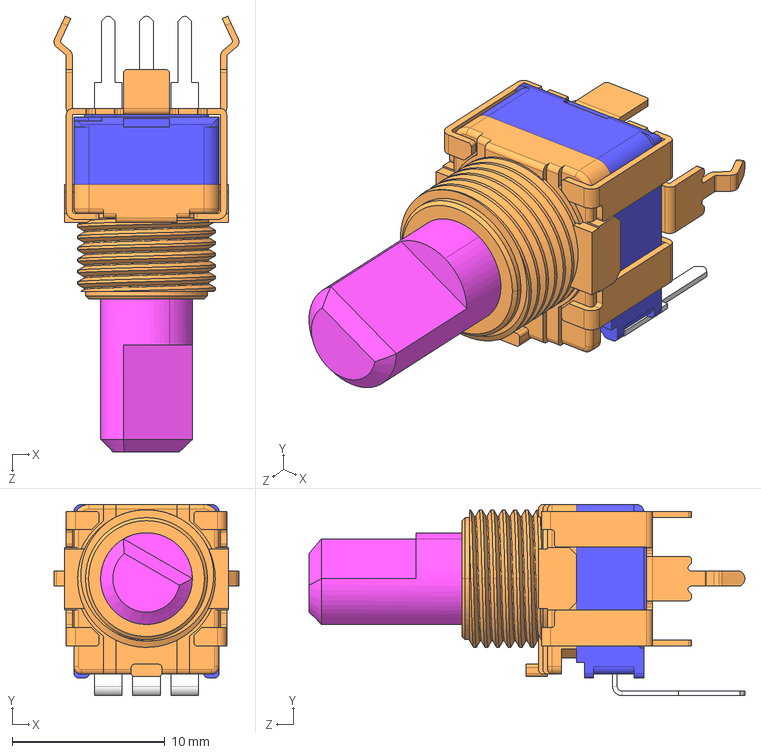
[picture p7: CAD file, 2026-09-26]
doc/public/assets/reference/assets/pot/RK09L1140-F15.STEP
12.1 x 12.5 x 28.5 mm

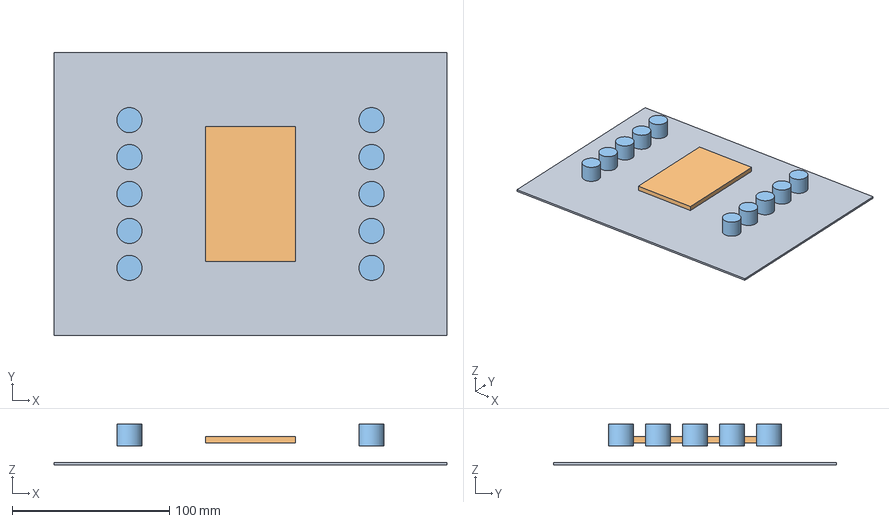
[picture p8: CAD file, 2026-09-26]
mechanical/NOMINAL-ENVELOPES-NOT-FIT-CAD.step
250.0 x 180.0 x 26.0 mm

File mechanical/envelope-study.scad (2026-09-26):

// Nominal ergonomic envelopes only. NOT exact parts, a routed PCB or drill drawing.
// Units mm. No holes are cut because final module/shaft/pad geometry is unqualified.
$fn=40;
color([0.3,0.4,0.4]) cube([250,180,1.6]);
color([0.15,0.2,0.2]) translate([96.4,47,14])cube([57.2,86,4]);
for(side=[0:1])for(row=[0:4]){
  x=side==0?48:202; y=43+row*23.5;
  color([0.25,0.25,0.25]) translate([x,y,12]) cylinder(h=14,r=8);
  color([0.55,0.55,0.55]) translate([side==0?70:166,y-3,11])cube([14,6,5]);
}
// The actual pot manufacturer STEP remains under reference/assets/pot/.

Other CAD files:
mechanical/NOMINAL-ENVELOPES-NOT-FIT-CAD.stl

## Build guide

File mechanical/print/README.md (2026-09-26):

# G09 panel print sheet

`panel-1to1.svg` (and `panel-1to1.pdf` when a converter was available) is a
1:1 physical-scale review sheet generated from `mechanical/panel-layout-study.json`
and `mechanical/envelope-study.scad` by `scripts/make_panel_print.py`. It is
**desk output, not the panel drawing**: every control shown is a nominal
ergonomic envelope, not an exact part, footprint or drill drawing (see the
package `AGENTS.md`). It exists to let a human run gate **G09 ("Physical
review")** locally; it never closes G09 by itself.

The active-area rectangle embeds `reports/renderer-capture.png` (#44 / #26
part 3): a deterministic host capture of the real `scope_render.c` /
`scope_core.c` renderer (`scripts/capture_renderer.py`), at the module's
physical pixel pitch. It carries the 2.68 mm long-axis active-area offset
from `design/evidence/g02-mechanical-pins.md` (#4a); the print labels its
mount **orientation as an explicit ASSUMPTION** (see
`mechanical/panel-layout-study.json`'s `active_area_offset_*` fields) because
the evidence gives the offset's magnitude and which STEP-local edge it is
toward, not which physical panel edge that becomes once mounted. Read the
real waveforms and text against the print at arm's length as an actual
readability check, not the previous empty placeholder rectangle.

**`panel-1to1.pdf` note (this change):** the PDF in this checkout predates
the renderer-capture image above (no `rsvg-convert` or `cairosvg` was
available in the environment that made this change, so the PDF could not be
regenerated). Treat it as stale until it is regenerated from the current
`panel-1to1.svg` with one of those tools installed; `panel-1to1.svg` itself
is current and is what `scripts/validate_extra.py` checks.

Regenerate after any change to the source files (including
`reports/renderer-capture.png` — run `scripts/capture_renderer.py` first if
that needs regenerating too):

```sh
python3 scripts/capture_renderer.py
python3 scripts/make_panel_print.py
```

The script re-derives every dimension from those sources (panel size, LCD
module offset, pot bushing radius, and the shared jack/range-switch envelope
box from the `.scad`; control positions and LCD sizes from the `.json`) and
writes deterministically — running it twice produces byte-identical output.

## Local procedure (do this with the printed sheet, not on screen)

1. **Print `panel-1to1.pdf`** (or `panel-1to1.svg` from a browser) on A3
   paper at **100% / actual size**. Explicitly disable any printer or PDF
   viewer "fit to page" / "shrink to fit" option — that is exactly the
   scaling error this sheet exists to catch.
2. **Measure the two scale-check rulers** with a ruler or tape: the sheet
   marks a 100 mm and a 50 mm bar. If either does not measure exactly, the
   print was scaled — reprint before trusting anything else on the sheet.
3. **Lay a real ID-1 card** (a credit card, 85.60 x 53.98 mm) inside the
   printed credit-card outline as a second, pocket-checkable scale
   reference. It should sit flush inside the outline.
4. **Place the real parts** (LCD module, pots, range switches, jacks) on top
   of their printed envelopes. Confirm each part's body fits inside its
   drawn envelope and its mounting/shaft point lands inside the printed
   circle or box; note any part that does not fit the nominal envelope
   (expected for at least the jacks/switches, whose exact bodies are not yet
   in the catalog).
5. **Check screen readability at arm's length**: hold or tape the sheet at
   the print's arm's-length viewing distance and confirm the channel number,
   RANGE, window-duration, UNCAL/VIEW CLIP/ADC SAT and HOLD/LINK text and the
   plotted waveforms in the "ACTIVE AREA" rectangle are legible at the size
   shown. That rectangle is now the actual `scope_render.c` renderer output
   (`reports/renderer-capture.png`), not a placeholder, so this is a genuine
   readability check of the real geometry and font — still a proxy for the
   real module at that distance, not a substitute for viewing it.
6. **Check control and cable clearance**: for each channel, confirm there is
   room between the pot knob, the range switch and the jack envelope for a
   hand to turn the pot and for a plugged cable to sit without fouling the
   neighbouring control. Note any channel that looks tight.
7. **Record the outcome** as desk evidence (for example under
   `design/evidence/`) — what measured correctly, what did not fit, and
   what remains to check with real hardware. Recording evidence here does
   not close G09: `manufacturing/release_guard.py` keeps it OPEN pending
   sign-off (`G10`).

## G09 evidence checklist

- [ ] Printed at verified 100% scale (both rulers measured exactly).
- [ ] Real ID-1 card matches the printed card outline.
- [ ] LCD module and active-area envelopes checked against the real module.
- [ ] Each pot/range/jack envelope checked against the real part (or noted
      as not yet fitting, with why).
- [ ] Screen readability at arm's length assessed.
- [ ] Control/cable clearance assessed per channel.
- [ ] Findings recorded as desk evidence; G09 left OPEN.

## If no SVG-to-PDF converter is available

`scripts/make_panel_print.py` uses `rsvg-convert` (Debian/Ubuntu package
`librsvg2-bin`) or, if that is absent, the `cairosvg` Python package, to
produce `panel-1to1.pdf`. If neither is installed, the script still writes
`panel-1to1.svg` and prints a note instead of failing. `panel-1to1.svg` opens
and prints directly from any modern browser at 1:1 scale as long as "fit to
page" is turned off, so the PDF is a convenience, not a requirement.

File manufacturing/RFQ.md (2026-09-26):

# RFQ preparation — not sent

Please quote a small prototype lot of a mixed SMT/THT carrier after we supply a reviewed native design and fabrication package.

Mandatory scope: every electrical component must be soldered before delivery. Include ten panel pots, ten SP3T maintained range switches, ten 3.5 mm input jacks, two tactile buttons, all module header/socket strips, passives, analog ICs and protection components. No manual soldering, wire links, header installation or rework may be deferred to the customer.

External modules: genuine preheadered Raspberry Pi Pico H and assembled Waveshare Pico-ResTouch-LCD-3.5 SKU19907. Confirm whether you can source/integrate and test them, or deliver a tested carrier into which the customer only plugs the preassembled modules. Confirm exact header orientation and module power variant.

Before receiving consigned parts, confirm each exact MPN, quantities including attrition, packaging, shipment destination and handling process. Report unsupported components rather than marking them customer-fit.

Please separate PCB cost, components, assembly/NRE/fixture charges, module costs, mechanical finishing, calibration/functional test and shipping. Confirm soldering/washing profiles compatible with the chosen ALPS/NKK controls and contamination-sensitive analog inputs. Scope functional testing explicitly; AOI is not a functional/calibration test.

We will supply the acceptance matrix, programming file only after a verified build, calibration format and exact fixture instructions. No current package is authorized for fabrication.

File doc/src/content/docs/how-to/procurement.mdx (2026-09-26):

---
# GENERATED by scripts/build_docs.py
title: "Sourcing and no-home-soldering contract"
sidebar_position: 3
---

## Prototype approval precedes any prototype order

An RFQ for a **prototype** quantity still needs the separate prototype-approval decision recorded first: `design/release-gates.json`'s `decisions.prototype.allowed` set `true`, every listed prerequisite `met` with real evidence, and an explicit human `approval` record (approver/date/revision, never auto-filled). `manufacturing/release_guard.py --route prototype` refuses (exit 2) until then. This is separate from, and never a substitute for, the full production release decision (`--route production`, G01-G10) below -- ordering an approved prototype authorizes exactly one factory-soldered prototype board, not a production run.

## Factory scope

Deliver the custom carrier with every fitted electrical item soldered: all passives, six op amps, three muxes, reference/regulator, ten jacks, ten pots, ten range switches, two buttons and all four module connector strips. No “hand-fit after delivery” connector, wire link or programming header is acceptable.

Supply a genuine preheadered Pico H and an assembled Waveshare SKU 19907. Either the assembler integrates them, or the user plugs the tested modules into already-populated sockets while unpowered. Nut tightening, cap fitting, standoffs and plugging a finished harness are mechanical assembly, not soldering. A socketed module does not mean untested electrical assembly is acceptable.

[JLCPCB's assembly capabilities](https://jlcpcb.com/capabilities/pcb-assembly-capabilities) describe mixed through-hole and surface-mount routes. [Global sourcing](https://jlcpcb.com/help/article/how-to-use-jlcpcb-global-sourcing-parts-service) and [consignment](https://jlcpcb.com/help/article/how-to-consign-parts-to-jlcpcb) are procurement routes, not approval of this part/board combination. Do not ship supplier parts to an assembler before obtaining receiving and assembly instructions.

## Current sourcing gaps

The catalogue identifies TLV9064IDR/C388176, 74HC4067PW,118/C179326, TLV75533PDBVR/C404027, BAV199/C40919, the ALPS pot, XUNPU button and SHOU HAN jack. Recheck stock and tiers at quotation. NKK SS14MDP2/C6684954 was listed with zero stock: select pre-order/global sourcing or an approved external supply. Its numerical terminal map remains open. Separately, SS14MDP2 is a silver-contact part used in this design's near-zero-current dry sense circuit; the manufacturer's own dry-circuit guidance recommends gold contacts for that regime, so it is `OPEN_REQUIRES_MANUFACTURER_CONFIRMATION_AND_QUALIFICATION` (catalogue record `range`; see `design/evidence/range-contact.md`) rather than sourcing-approved for this application, independent of the stock question.

REF3330AIDBZR is an exact proposed MPN, but no JLC assembly availability was established. Resistor/capacitor records deliberately include unselected supplier identities rather than invented C-numbers. The Pico sockets, display headers, fuse, knob caps, spacers and mounting screws also need exact mechanical/orderable selection.

## Cost honesty

A single display eliminates nine screens and their interconnects, but does not make ten dedicated knobs and range controls free. The selected Waveshare page showed $19.99 for the module on 2026-09-26; it excludes Pico, carrier, controls, assembly, shipping and taxes. NKK switches may dominate the control budget. Obtain the prototype quote before assuming this is a sub-$30 assembled monitor.

For quotation compare three separate figures: populated carrier; preassembled external modules; mechanical finishing/functional test. Separate non-recurring assembly/fixture charges from per-board costs and calculate at the intended prototype quantity. `manufacturing/cost-template.json` leaves unknown prices null so they cannot disappear into an apparently complete total.

The most promising later cost reductions are qualifying an inexpensive exact SP3T switch, integrating RP2040 onto the board, qualifying a bare non-touch LCD, reducing panel/PCB area, and relaxing dedicated control count only with the user's explicit agreement. P0 does not silently replace the ten controls with a shared menu.

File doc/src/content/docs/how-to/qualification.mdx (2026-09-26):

---
# GENERATED by scripts/build_docs.py
title: "Bring-up and acceptance matrix"
sidebar_position: 4
---

## Prototype approval, before any bench work below

Do not skip straight from a KiCad save to the bench procedures below. `manufacturing/release_guard.py --route prototype` checks a separate, fixed decision (`design/release-gates.json`'s `decisions.prototype`) that must be satisfied and explicitly approved by a human -- reviewed power/pin design, actual footprint mapping, completed layout plus native ERC/DRC/parity, the assembler's DFM review, and a controlled current-limited/staged-enable bring-up plan -- before ordering the assembled board this page's procedures run on. That decision never reads or requires G01/G02/G03/G04/G05/G06/G07/G08/G09/G10's CLOSED status, and it never claims any bench result from this page in advance. See `LOCAL-HANDOFF.md`'s "Prototype approval" section for the exact prerequisite list.

## Before the populated board is powered

Ask the assembler or bench-service provider to check component identity, numeric pin mapping, solder joints, shorts, module orientation, power/header continuity and the exact approved module revision. Confirm F1 and USB source current path. Use a current-limited 5 V source. Note that the display backlight is default ON at power-up (it is active-low on GP13 through the carrier's Q1 open-drain stage, #41) and goes dark only once firmware drives GP13 high; the LCD-off build does that from its early init hook. Capture the GP13/gate/`LCD_BL` waveforms per `design/evidence/backlight-interface.md` before G01/G06 closure. Rework belongs to that provider, not the home workstation.

Power tests first establish analog/digital rails, 3.0 V reference, startup/off decay, USB current and absence of back-power. Measure current separately with no display, dark display and bright display. Obtain board/module thermal images or measured hot-spot temperatures under worst intended load.

## Channel tests

Use a verified low-voltage signal fixture with the same ground and appropriate current limits. Begin with inputs shorted to ground, then step through measured ±1, ±3, ±5, ±8 and ±12 V. Record raw codes and DMM readings for all ten channels. Verify expected open-input bias rather than treating it as a defect or auto-zeroing it away. Test all TIME endpoints/direction and all three RANGE positions.

After normal-range DC validation, check 1 Hz, 10 Hz, 100 Hz, 500 Hz and 1 kHz signals, then deliberately characterize aliasing above the intended range. Compare displayed amplitude against reference instrumentation and the predicted filter transfer function. Distinguish source distortion from this monitor's filtering, conversion and display effects.

Worst-case mux test: alternate a near-positive-full-scale channel and a near-negative-full-scale channel, hold neighboring channels at zero, and measure residual settling/crosstalk with the LCD off and active. Increase rate only while recording discarded/kept conversion timing and overrun counts. An 8 µs slot is acceptable only when its measured error meets the reviewed target.

## Separate abnormal-voltage qualification

Do not apply ±24 V merely because the design spreadsheet contains it. First review all clamp paths and absolute maximum constraints, then conduct a controlled powered/unpowered current-limited test at a suitably equipped provider. Inspect both source and internal node currents and any back-powered rail. ESD immunity is a separate test; successful DC injection is not an IEC ESD claim.

## Initial proposed acceptance limits

These are engineering targets, not achieved results. Review them after the first measured sample:

| Item | Proposed target |
|---|---|
| Calibrated DC residual, low-impedance source | no more than 100 mV over ±8 V, excluding noise outliers |
| Channel crosstalk on DC steps | no more than 100 mV input-referred after the selected settling interval |
| Reliable useful bandwidth | characterize DC–1 kHz amplitude error; do not assume flatness |
| High-rate acquisition | ten actual 10 ksample/s streams with counted overruns and measured skew |
| RANGE state | stable reading after 20 ms; no indefinite intermediate-state oscillation |
| LCD behavior | all ten panes, correct orientation/colors/labels; readable physical-scale text |
| User assembly | no unsoldered electrical part or wire after delivery |

No hardware result is prefilled in `manufacturing/acceptance-results.csv`. Failed items remain visible. The first populated prototype may require a second PCB revision; do not shift that rework onto the user.

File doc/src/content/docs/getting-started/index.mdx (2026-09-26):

---
# GENERATED by scripts/build_docs.py
title: "Start here"
sidebar_position: 1
---

## What this package is

`zudo-scope10` is the ten-input waveform monitor, separated from the five-oscillator instrument. “LED” in the request is interpreted as the LCD/display project. The LED-lamp repository supplies the documentation pattern, not the circuit.

This release is a **pre-layout engineering handoff**. It contains a specified circuit, native schematic drafts, analytical calculations, control/UI prototype, selected component evidence, firmware core tests and manufacturing instructions. It does not contain a completed routed PCB, verified Gerbers, production CPL, completed LCD firmware or an approved order.

## The first hardware build

Use one factory-populated custom carrier, one factory-headered Raspberry Pi Pico H, and one preassembled Waveshare Pico-ResTouch-LCD-3.5 (SKU 19907). Keep ten independent inputs, ten TIME pots and ten three-position RANGE switches. One LCD shows ten panes at once.

No soldering at home is required or assumed. All PCB components, including through-hole controls, connectors and headers, belong on the factory BOM. Modules are plugged into already-soldered connectors with power off. Any needed electrical repair goes to the assembler or a contracted rework service.

## Local sequence

1. Run `python3 scripts/validate.py` from the project root. This checks the data and generated files, not electrical safety.
2. Run `python3 scripts/serve.py`, then browse `http://127.0.0.1:8000/`. The offline catalogue and UI simulation work without npm packages.
3. Read the power/interface gates and the component pin maps before opening `hardware/kicad/zudo-scope10-p0.kicad_pro`.
4. Resolve the display module's power/header revision and the physical jack, switch, socket and cap drawings before finishing footprints or placement.
5. Complete local KiCad review, layout, ERC/DRC and assembly review. Do not order the outline-only `.kicad_pcb`.

The documentation can be read immediately as Markdown. The included `doc/` contains native zudo-doc configuration and MDX content. Use `scripts/bootstrap_doc.sh` to obtain the official scaffold in a new directory when you prefer that route. No repository, online document or order has been modified.

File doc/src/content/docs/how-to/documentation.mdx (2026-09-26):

---
# GENERATED by scripts/build_docs.py
title: "Local zudo-doc integration"
sidebar_position: 5
---

## Two usable reading paths

The offline catalogue and simulator need only Python's local HTTP server. The `doc/` source also targets the native zudo-doc framework used by the lamp project: one config, package-owned route stubs and MDX content. It is not a clone of the lamp's full component validation framework.

The lamp's key principle is retained: **structured component data are authoritative; pages are a generated projection**. Edit `catalog/components.json`, source records or narrative inputs, then run `python3 scripts/build_docs.py`. Do not edit the generated component pages independently.

## Official scaffold route

The included `scripts/bootstrap_doc.sh NEW_DIRECTORY` invokes the published `create-zudo-doc@5.27.0` scaffold in an empty directory, copies this package's MDX, public assets and minimal config into it, and leaves dependency installation to you. It does not modify your existing lamp project or a pre-existing target directory.

```sh
bash scripts/bootstrap_doc.sh /path/to/new/scope-doc
cd /path/to/new/scope-doc
pnpm install
pnpm build
pnpm dev
```

The framework package/build tool were not installed or built in this environment because network package downloads were unavailable. Native build and interaction checks remain local tasks; the separate offline site is already generated.

For an existing zudo-doc workspace copy `doc/src/content/docs/`, `doc/public/` and the selected configuration fields, resolving category collisions deliberately. Keep public source binaries under review: manufacturer files are retained for local engineering reference and do not automatically carry permission for unrestricted republication.

## Component evidence

Each generated record carries exact or unresolved identity, role, package candidate, pin mapping, source links, retained file hashes, source availability and separate open questions. A verified part identity does not mean a verified footprint, a verified factory process, an assembled board or a successful measurement. Blank asset sections say explicitly that a model or datasheet was not recovered.

The pot has an original downloaded manufacturer STEP and drawing files recovered from the earlier component ZIP. The Pico/display STEP files were not downloaded successfully; the mechanical envelope study is not substituted for exact CAD. Missing binary downloads are listed and a local source-fetch script is supplied.

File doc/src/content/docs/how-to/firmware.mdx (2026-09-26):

---
# GENERATED by scripts/build_docs.py
title: "Firmware handoff"
sidebar_position: 1
---

## Delivered and tested

`firmware/src/scope_core.c` is portable C for ADC-to-voltage conversion, measured two-point calibration, logarithmic TIME mapping, RANGE decoding with debounce, and bounded multiresolution min/max history. `python3 scripts/test_firmware.py` compiles and runs it on the host with warnings treated as errors. These tests exercise mathematics and data handling; they do not prove RP2040 operation.

`firmware/src/pico_diagnostic.c` initializes the specified pins, scans the three mux outputs with conservative delays, and writes raw CSV values over USB serial. It deliberately leaves the LCD off and does not implement the ten-channel high-rate engine. No prebuilt UF2 is supplied because target compilation and hardware execution were unavailable.

## Local target build

Install a reviewed Pico SDK and an ARM compiler in your usual local toolchain. Set `PICO_SDK_PATH` to the checkout. The package does not run an unpinned SDK download during CMake configure.

```sh
cmake -S firmware -B firmware/build -DPICO_BOARD=pico
cmake --build firmware/build
```

The above builds only `scope10_diagnostic`, after local source/toolchain review. Record compiler/SDK versions and build hashes. Do not flash/energize the assembled module interface before G01 power/pin checks.

## LCD integration remains open

Download the vendor example archive from the source manifest. Its module uses an SPI-to-parallel bridge around ILI9488; this is not necessarily the same transfer framing as a raw ILI9488 SPI panel. Adapt the exact 3.5-inch vendor driver to the GPIO table and disable touch/SD access. Confirm reset, CS, DC, RGB565 byte order, orientation, address-window writes and backlight behavior using color bars and corner markers before waveform drawing.

`display_port.h` specifies the renderer's small-rectangle API. There is intentionally no no-op fake backend: an application using these calls cannot link until a real implementation is supplied. Do not allocate a 307,200-byte framebuffer or use a generic driver with an assumed RGB666 pixel protocol.

## Calibration and data provenance

`firmware/tools/calibrate.py measured.csv calibration.json` requires two measured DC points for every channel. Input columns are `channel,volts,mean_code`. Use the actual DMM-measured fixture voltage; do not pass an assumed front-panel generator setting as ground truth. Inspect intermediate 0, ±3, ±5 and ±8 V residuals after fitting. Store board serial, date, fixture identity, temperature, firmware hash and source CSV with the calibration file.

Persistent flash storage, CRC/versioning, safe defaults, a real-time display renderer, trigger alignment, DMA/PIO acquisition and hardware tests are not complete. They have explicit acceptance tasks rather than success claims. Never perform automatic “zero at startup” on attached signals.

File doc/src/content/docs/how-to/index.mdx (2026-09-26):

---
# GENERATED by scripts/build_docs.py
title: "Local build and qualification"
sidebar_position: 0
---

## Pages

- [Firmware handoff](/docs/how-to/firmware/)
- [KiCad completion procedure](/docs/how-to/kicad/)
- [Sourcing and no-home-soldering contract](/docs/how-to/procurement/)
- [Bring-up and acceptance matrix](/docs/how-to/qualification/)
- [Local zudo-doc integration](/docs/how-to/documentation/)

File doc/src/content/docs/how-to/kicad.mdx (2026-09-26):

---
# GENERATED by scripts/build_docs.py
title: "KiCad completion procedure"
sidebar_position: 2
---

## What opens locally

Start with `hardware/kicad/zudo-scope10-p0.kicad_pro`. The root schematic links ten child sheets: power, module interfaces, acquisition, five dual-input pages and two control pages. All selected pin mappings and values come from `design/circuit.json`, generated by `scripts/make_design.py`. There are 224 physical instances in the draft and 134 named nets.

The symbols are intentionally pin-complete rectangular review symbols. They are not polished conventional circuit drawings. The text netlist and `design/connections.csv` provide an independent review surface. Global labels carry inter-sheet connections. The host checks compare generated pin/net memberships; they are not native KiCad ERC.

The `.kicad_pcb` is **only a 250 × 180 mm rectangular outline**, with no footprints or tracks. Do not manufacture it. Mechanical mounting holes listed in the requirements are proposals and are not drilled in that outline.

## Required work before placement

1. Reacquire and visually review the exact display schematic/CAD and NKK switch drawing. Resolve all physical pin identities, including duplicated PJ-313 terminals.
2. Select actual MPNs and supplier codes for resistors, capacitors, fuse and four module-header strips. The passive resistor tolerances, voltage ratings and capacitor dielectrics are constraints, not interchangeable generic labels.
3. Verify every symbol pin to actual footprint pad. The locally supplied XUNPU footprint is drawing-derived, not independently approved. Generic SOIC/TSSOP/SOT package names are candidates, not evidence of exact footprint correctness.
4. Confirm the Pico and display socket heights, component face, mirrored row numbering, module service clearance, USB access and control panel stack. Exact display hole/connector geometry is still unavailable here.
5. Open all generated files in the current KiCad, fix any native format issues, save, run ERC and reconcile every electrical finding with the source specification. Preserve project-generated evidence and report native tool/version/results.

## Routing guidance

Use a continuous low-impedance ground reference under signal and digital circuits; do not automatically split the ground plane and force return currents across gaps. Separate the LCD/SPI and backlight return paths spatially from biased input nodes and reference distribution. Place each amplifier's 100 nF bypass at its supply pins. Keep the 1 MΩ / 200 kΩ / 249 kΩ high-impedance node compact and clean, with the clamp and first capacitor close to the input amplifier.

Keep the mux-common traces short; place the three post-mux buffers and ADC RC networks near their loads. Treat display clock, address edges and source-series resistors as a coupled noise/settling problem. Run representative worst-case pattern tests with the display active as well as dark.

The four-layer, 1.6 mm board is a starting point for grounding and routing convenience, not a paid fabrication stackup. Confirm assembler-supported layer/copper/thickness options and actual mechanical constraints before locking it. A later compact or two-layer cost-down is a separate layout qualification.

## Release sequence

After native ERC, placement and routing, refill planes and run DRC, schematic-to-PCB parity, pin-map checks and mechanical review. Export Gerbers, drill, assembly BOM, CPL and STEP only from that reviewed revision. Review JLC's placement rendering and obtain written assembly acceptance for every fitted line. Archive the exact exported bytes and checksums. `manufacturing/release_guard.py` blocks release while any gate remains open; it does not replace engineering review.

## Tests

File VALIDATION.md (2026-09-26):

# Validation status — P0 pre-layout

Rolled up by issue #16 on the merged base (all of #2–#15). Every check below was re-run in this
session on this tree; results and report paths are current as of this commit.

## Executed checks

- `python3 scripts/validate.py`: **79 structural checks passed**. 224 physical schematic
  instances, 134 named nets, module/contact maps, native-file S-expression structure, XML graph
  equivalence, 11-sheet inventory, source-file hashes, local HTML references and deterministic
  regeneration. (`markdown-it-py` absent in this container; `offline/*.html` regenerates in its
  fallback mode, which the check tolerates.) Regeneration is checked in an isolated temp copy of
  the repository (#23/#31), so a mismatch or a generator bug cannot mutate or destroy this
  checkout's PCB, project or any other file; `hardware/kicad/zudo-scope10-p0.kicad_pro`/
  `.kicad_pcb` are developer-owned once created and `scripts/make_design.py` only writes them on
  first creation or with `--init-kicad`. `python3 scripts/test_validate_nondestructive.py` is the
  regression fixture for this behavior.
- `python3 scripts/test_firmware.py`: the portable C core (including the real `acq_engine.c`,
  `scope_core.c`, `lcd_bridge.c`, `scope_render.c`) compiled under the host C compiler with
  warnings as errors and passed calibration, 4,096-point logarithmic time, range/debounce/
  timer-wrap, multiresolution-history, uniform-slot acquisition, ring wrap/overrun, injected-stall
  missed-slot accounting, channel-order invariance, and LCD bridge framing/clipping/pane-layout
  assertions. Ten-channel history: 77,800 bytes. Acquisition engine RAM: 49,496 bytes; IRQ budget
  240 cycles.
- `python3 scripts/analyze.py`: ideal DC transfer, passive filter response, restricted
  resistor/reference corner enumeration, simple fault-current bounds, acquisition timing budget
  and framebuffer/SPI arithmetic recomputed. `reports/analog-analysis.json`,
  `reports/filter-response.csv`.
- `python3 scripts/kicad_check.py`: **PASS** — kicad-cli 9.0.9 loads the root
  `hardware/kicad/zudo-scope10-p0.kicad_sch` (11-sheet hierarchy) and the outline-only
  `.kicad_pcb`. Hierarchy ERC total 0, 0 unexplained; outline-board DRC 0 errors/warnings/
  unconnected items; netlist parity PASS (224 instances / 134 nets, 0 differences).
  `reports/kicad-check.json`. This is not placement/routing or a final DRC of a populated board.
- `PICO_SDK_PATH=<pico-sdk 2.1.1> bash scripts/build_firmware.sh`: **PASS**, all three targets,
  arm-none-eabi-gcc 13.2.1, `-Wall -Wextra`, 0 warnings: `scope10_diagnostic` (67,584 B),
  `scope10_acq` (LCD off, 81,920 B), `scope10_acq+lcd` (`-DSCOPE_ENABLE_LCD=1`, 93,696 B).
  `reports/firmware-target-build.json`.
- `python3 scripts/run_spice.py`: **PASS**, ngspice 42 on the ideal-buffer netlist
  (`simulation/input-channel.cir`) matches `analyze.py`'s analytic model within a 2% tolerance
  (gain diff 1.8e-5%, zero diff 1.5e-5%, cascade-corner diff 0.06%). No vendor TLV9064 SPICE model
  is used or committed (no confirmed redistributable licence). `reports/spice.json`.
- `python3 scripts/make_panel_print.py`: **PASS**, regenerates `mechanical/print/panel-1to1.svg`
  and `.pdf` deterministically (via rsvg-convert).
- `cd doc && pnpm install && pnpm build`: **PASS**, 74 pages built (46 generated MDX +
  framework pages) via the real `@takazudo/zfb`/`@takazudo/zudo-doc` packages (not previously run
  in any container). `reports/doc-generation.json` records the Python codegen step only
  (`build_docs.py` cannot see the outcome of the `zfb build` step that runs after it, so its
  `native_zudo_doc_build` field stays `"NOT_RUN"` by construction — the native build's actual
  PASS is this line plus the browser-smoke check below). Non-fatal warnings only: one
  `@takazudo/zudo-doc-history-server` optional git-metadata plugin is absent (informational),
  and 13 pre-existing broken image links inside a vendored manufacturer HTML asset
  (`reference/assets/pot/manufacturer-page.html`), unrelated to this build.
- `python3 scripts/browser_smoke.py` (HTTP mode, Chromium via Playwright + Pillow): **PASS**, all
  6 checks including the offline catalogue, the ten-pane UI (time controls, radios, link-restore,
  HOLD freeze, no 390px overflow, no console errors), the GLB viewer, and the **built** zfb site
  in `doc/dist` served over HTTP (getting-started + components pages). No `not_run` entries;
  loopback navigation is not blocked in this container. `reports/browser-smoke.json`.

## Not executed / not established

| Domain | Status and reason |
|---|---|
| KiCad GUI footprint placement, PCB routing, final DRC/ERC on a populated board | NOT RUN: needs a local KiCad GUI session (G03). Native load + hierarchy ERC + outline DRC + netlist parity are RUN and PASS (above); that is not placement or routing. |
| Actual footprints / real-part fit for range, jack, pot, fuse, pico-h, display, socket20/header20 mating | NOT RUN: needs the physical parts (G02). Vendor-drawing facts and 24/30 candidate footprints are RUN and recorded; see `design/evidence/g02-mechanical-pins.md` and `design/evidence/INTEGRATION.md`. |
| G01 physical module revision/strap/population check and the GP13 backlight-interface waveform capture | NOT RUN: needs the physical Waveshare module and a factory-assembled prototype (G01). Desk evidence and the applied open-drain design (#41) are RUN and recorded; see `design/evidence/g01-display-power.md`, `design/evidence/backlight-interface.md` and `design/circuit.json`'s `pending_g01_changes` (`DESIGN_APPLIED_BENCH_CHECK_PENDING`). |
| SPICE with the vendor TLV9064 model; powered/unpowered fault, leakage, injection, recovery bench tests | NOT RUN: no confirmed redistributable TLV9064 SPICE model, and all of this needs bench equipment (G04). The ideal-buffer ngspice run is RUN and PASSES against the analytic model (above). |
| Acquisition bench measurement: mux settling, real sample cadence, missed-slot counters on hardware, alias response, cross-talk | NOT RUN: needs bench equipment (G05). The host-tested cycle-level model of the real engine is RUN and PASSES (above); it is a model, not a measurement. |
| Real LCD bring-up: ten panes, time/range, controls, HOLD, LINK on the actual display | NOT RUN: needs the physical display and G01 resolved first (G06). The clean-room backend builds clean against the real SDK with `SCOPE_ENABLE_LCD=1` (RUN, above); nothing was flashed or observed. |
| Power/USB bench measurement: backlight/inrush current, Pico + analog rail, USB enumeration sequencing | NOT RUN: needs bench equipment and a power gate design decision (G07). Desk arithmetic is RUN; it flags `vs_unconfigured_limit: fail_or_unknown` — see `reports/power-budget.json`. |
| Sourcing: stock allocation, quote, factory acceptance of the BOM | NOT RUN: no parts reserved or ordered (G08). mpn/jlc_code candidates for cited specification-only rows are RUN and applied (11 of 14; 3 stay OPEN: r249k, socket20, header20) — see `design/evidence/g08-sourcing.md`. |
| Physical panel print review: readability, control/cable clearance, stack acceptance | NOT RUN: needs a physical print and the real parts (G09). The deterministic 1:1 print-sheet generator is RUN and PASSES (above). |
| Assembler DFM review of the saved KiCad revision | NOT RUN: needs a local session with an assembler (`LOCAL-HANDOFF.md` step "Assembler review"). |
| Factory-assembled prototype order (no home soldering) | NOT RUN: needs a local ordering decision (`LOCAL-HANDOFF.md` step "Factory-assembled prototype"). |
| Release approval / BOM/CPL/Gerber export | NOT RUN: `manufacturing/release_guard.py` refuses while any gate is OPEN (G10, RUN and confirmed refusing, below). No export exists. |
| Physical fit, thermal/current, immunity, accuracy | NOT TESTED. No assembled hardware exists for this project. |

## Known unreconciled figure (documentation, not a gate)

`firmware/ACQUISITION.md` documents the acquisition engine's real budget: 9 slots of 8.333 µs
each between CH1 and CH10, i.e. a **75 µs** channel skew. `reports/analog-analysis.json` and the
generated architecture narrative (`design/narrative-pages.json` → `doc/.../architecture/
acquisition.mdx`) still quote **72 µs**, a figure from an earlier 8 µs-slot sketch that predates
the #12 engine; `firmware/ACQUISITION.md` already states this discrepancy in its own budget
table. Reconciling the narrative source is not a one-line fix: the surrounding paragraph frames
the schedule as an "intended", unimplemented target, which is no longer accurate now that #12
shipped the real engine, so a proper fix means rewriting that paragraph's framing, not just
swapping a number. Left for local follow-up; see `LOCAL-HANDOFF.md`.

## Release status

**BLOCKED.** All ten release gates remain OPEN, each with an `evidence_partial` list in
`design/release-gates.json`. `python3 manufacturing/release_guard.py` exits nonzero (confirmed
this session) by design. No Gerber, drill package, CPL or approval document is included. A
passing desk/structural/host/native-tooling check cannot close a hardware, GUI-routing, bench,
sourcing or assembly gate.

See the machine-readable `reports/validation.json`, `reports/firmware-host-tests.json`,
`reports/firmware-target-build.json`, `reports/kicad-check.json`, `reports/spice.json`,
`reports/browser-smoke.json`, `reports/doc-generation.json`, `reports/power-budget.json`,
`reports/analog-analysis.json` and `design/release-gates.json`. Test reports describe only their
stated scope. `LOCAL-HANDOFF.md` gives the numbered local procedure for everything above marked
NOT RUN.

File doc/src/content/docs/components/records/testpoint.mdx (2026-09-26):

---
# GENERATED by scripts/build_docs.py
title: "testpoint / supplier selection open"
sidebar_position: 31
---

## Identity

| Field | Value |
|---|---|
| Record | testpoint |
| Manufacturer | PCB geometry |
| Orderable identity | NOT SELECTED |
| JLC/LCSC | NOT VERIFIED / NOT APPLICABLE |
| Package | Exposed pad |
| Identity | SPECIFICATION_ONLY |
| Fit | PROPOSED_NOT_ASSEMBLED |
| References | TP1 TP2 TP3 TP4 TP5 TP6 TP7 TP8 TP9 TP10 TP20 TP21 TP22 TP30 TP40 TP41 TP42 TP43 TP44 TP45 TP46 |
| Footprint candidate | TestPoint:TestPoint_Pad_D1.0mm |

## Intended function

Factory test access

## Recorded findings

Copper test pad; no purchased part. Not a solder-yourself header.

## Pin map

Pin assignments below are electrical evidence or explicitly logical placeholders. They are not footprint qualification.

| Pin | Function |
|---|---|
| 1 | PAD |

## Documents and models

No original model or source binary was recovered for this record in this package. See the sources and the local download manifest; no nominal model is presented as an exact replacement.

## Coverage and unresolved questions

**Footprint independently qualified: NO. Factory order approved: NO. Bench result: NOT TESTED.**

- Fixture access and probe spacing must be reviewed.

The presence of a part number, datasheet or model closes none of these remaining gates automatically.

## Sources

Values and package constraints are authored design requirements, not manufacturer-verified specifications of a selected orderable part. Select the exact item and add its evidence before placement.

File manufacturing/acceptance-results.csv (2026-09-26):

test_id | board_serial | measured_value | unit | limit_or_requirement | result | evidence_file | operator | date
POWER_5V |  |  |  |  | NOT_RUN
ANALOG_3V3 |  |  |  |  | NOT_RUN
REFERENCE_3V0 |  |  |  |  | NOT_RUN
INPUT_DC_10CH |  |  |  |  | NOT_RUN
MUX_STEP_CROSSTALK |  |  |  |  | NOT_RUN
RANGE_TIME_10CH |  |  |  |  | NOT_RUN
LCD_COLORS_ORIENTATION |  |  |  |  | NOT_RUN
USB_INRUSH_CURRENT |  |  |  |  | NOT_RUN
INPUT_UNPOWERED_FAULT |  |  |  |  | NOT_RUN
NO_CUSTOMER_SOLDERING |  |  |  |  | NOT_RUN
RANGE_CONTACT_QUALIFICATION |  |  |  |  | NOT_RUN
BACKLIGHT_GP13_INTERFACE |  |  |  |  | NOT_RUN

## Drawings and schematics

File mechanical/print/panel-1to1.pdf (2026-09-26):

# ZUDO / SCOPE 10 — G09 PANEL PRINT SHEET

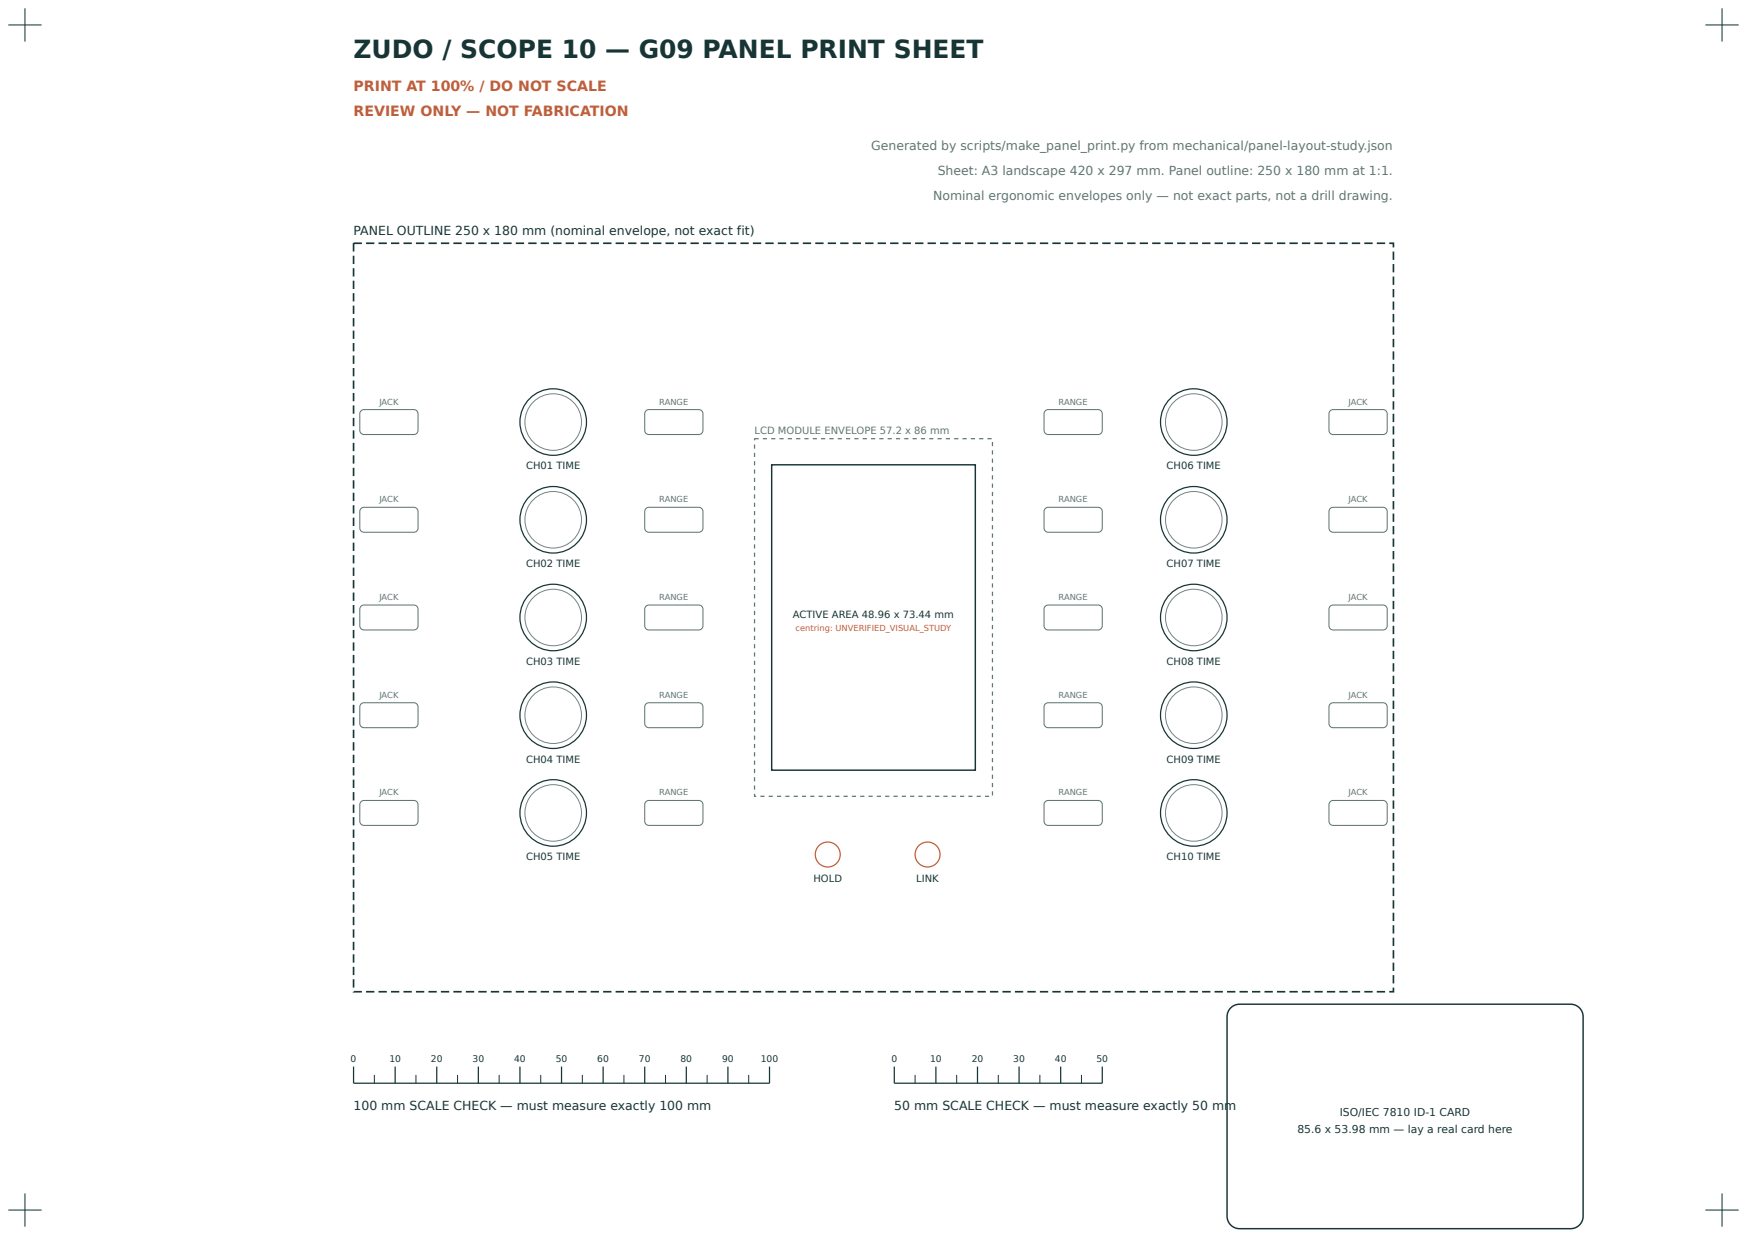
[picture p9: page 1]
CH01 TIME; JACK; RANGE; CH02 TIME; CH03 TIME; CH04 TIME; CH05 TIME; CH06 TIME; CH07 TIME; CH08 TIME; CH09 TIME; CH10 TIME; HOLD; LINK; 50 mm SCALE CHECK — must measure exactly 50 mm; ISO/IEC 7810 ID-1 CARD

PRINT AT 100% / DO NOT SCALE
REVIEW ONLY — NOT FABRICATION

Generated by scripts/make_panel_print.py from mechanical/panel-layout-study.json

Sheet: A3 landscape 420 x 297 mm. Panel outline: 250 x 180 mm at 1:1.
Nominal ergonomic envelopes only — not exact parts, not a drill drawing.

PANEL OUTLINE 250 x 180 mm (nominal envelope, not exact fit)

LCD MODULE ENVELOPE 57.2 x 86 mm

ACTIVE AREA 48.96 x 73.44 mm
centring: UNVERIFIED_VISUAL_STUDY

100 mm SCALE CHECK — must measure exactly 100 mm

85.6 x 53.98 mm — lay a real card here

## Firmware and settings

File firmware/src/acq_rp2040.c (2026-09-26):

/* scope10_acq: RP2040 register side of the 10 kS/s/channel acquisition engine.
 * Scheduling, missed-slot judgement and the ring consumer are portable (acq_engine.[ch]);
 * the design and its budget are in firmware/ACQUISITION.md. All figures are NOMINAL
 * design values: no sample rate, jitter or settle time has been measured (G05 OPEN).
 * Channels are sampled sequentially through the mux, never simultaneously.
 * The LCD is held dark and unselected (lcd_safe_pins.c, from before main) unless the
 * target is configured with SCOPE_ENABLE_LCD=1; then core0 also runs the ten-pane
 * renderer between drain batches (firmware/LCD-BACKEND.md, G06 OPEN).
 *
 * Hardware use:
 *   PWM slice 0  slot timer, wrap every 1000 cycles; its DREQ paces DMA "start", which
 *                writes the next ADC CS word (EN | START_ONCE | AINSEL) from cs_table.
 *   DMA "reload" re-arms "start" at the end of every 12-word frame table.
 *   PWM slice 1  same period, 300 cycles later; its wrap IRQ runs on core1 only and
 *                steps the mux address (GP2..GP5) and the GP14 frame pulse.
 *   DMA "col A/B" ping-pong the ADC FIFO (DREQ_ADC) into the engine ring; core0 drains
 *                it into scope_core histories and prints counters over USB serial. */
#include "acq_engine.h"
#include "lcd_safe_pins.h"
#include "hardware/adc.h"
#include "hardware/clocks.h"
#include "hardware/dma.h"
#include "hardware/irq.h"
#include "hardware/pwm.h"
#include "hardware/structs/timer.h"
#include "hardware/sync.h"
#include "pico/multicore.h"
#include "pico/stdlib.h"
#include <stdio.h>
#if SCOPE_ENABLE_LCD
#include "display_port.h"
#include "scope_render.h"
#define RENDER_ITEMS_PER_PASS 4u
#define LCD_STATE "LCD ENABLED (SCOPE_ENABLE_LCD=1, unverified: G01/G06 OPEN)"
#else
#define LCD_STATE "LCD OFF"
#endif

#define PIN_HOLD_N 0u
#define PIN_LINK_N 1u
#define PIN_ADDR0 2u
#define ADDR_MASK (0x0fu << PIN_ADDR0)
#define PIN_MUX_DISABLE 7u
#define PIN_TIMING_TP 14u
#define SLOT_SLICE 0u
#define STEP_SLICE 1u
#define HALF (ACQ_RING_LEN / 2u)
#define DRAIN_BATCH 1024u
#define REPORT_INTERVAL_US 1000000u

static void core1_step_irq_set(bool on);
#define ACQ_EPOCH_IRQ_SAVE() save_and_disable_interrupts()
#define ACQ_EPOCH_IRQ_RESTORE(s) restore_interrupts(s)
#define ACQ_EPOCH_TICK() (timer_hw->timerawl)
#define ACQ_EPOCH_DMB() __dmb()
#define ACQ_EPOCH_PWM_ENABLE() pwm_set_mask_enabled((1u << SLOT_SLICE) | (1u << STEP_SLICE))
#define ACQ_EPOCH_PWM_DISABLE() pwm_set_mask_enabled(0u)
#define ACQ_EPOCH_SEV() __sev()
#define ACQ_EPOCH_WAIT() tight_loop_contents()
#define ACQ_EPOCH_STEP_IRQ_SET(on) core1_step_irq_set(on)
#include "acq_epoch.h"

static acq_engine eng;
static scope_history hist[ACQ_CHANNELS];
static uint32_t cs_table[ACQ_SLOTS_PER_FRAME];
static const uint32_t *cs_table_addr = cs_table;
static uint ch_start, ch_reload, ch_col[2];
static volatile uint32_t col_halves;
/* Time base and arm/quiesce handshake for the core1 stepper (acq_epoch.h). */
static acq_epoch epoch;

static void out(unsigned pin, bool high) {
    gpio_init(pin);
    gpio_set_dir(pin, GPIO_OUT);
    gpio_put(pin, high);
}

static void __not_in_flash_func(on_mux_step)(void) {
    pwm_clear_irq(STEP_SLICE);
    if (!acq_epoch_enter(&epoch)) return; /* disarmed: leave engine and pins alone */
    acq_step_result r = acq_step_plan(&eng, acq_epoch_lower_bound(&epoch, timer_hw->timerawl));
    if (r.addr >= 0) gpio_put_masked(ADDR_MASK, (uint32_t)r.addr << PIN_ADDR0);
    gpio_put(PIN_TIMING_TP, r.frame_pulse);
    acq_step_commit(&eng, acq_epoch_lower_bound(&epoch, timer_hw->timerawl));
}

/* Runs on core1 in thread mode only (acq_epoch_core1_service), never inside the handler. */
static void core1_step_irq_set(bool on) {
    if (on) {
        irq_clear(PWM_IRQ_WRAP);
        irq_set_enabled(PWM_IRQ_WRAP, true);
    } else {
        irq_set_enabled(PWM_IRQ_WRAP, false);
        irq_clear(PWM_IRQ_WRAP);
    }
}

static void __not_in_flash_func(core1_main)(void) {
    irq_set_exclusive_handler(PWM_IRQ_WRAP, on_mux_step);
    irq_set_priority(PWM_IRQ_WRAP, PICO_HIGHEST_IRQ_PRIORITY);
    /* The step IRQ stays off until core0 requests it (acq_epoch_core1_request). */
    multicore_fifo_push_blocking(1u);
    for (;;) {
        acq_epoch_core1_service(&epoch);
        __wfe(); /* woken by core0's SEV and by every step IRQ */
    }
}

static void on_collector_done(void) {
    for (unsigned i = 0; i < 2u; i++) {
        if (!dma_channel_get_irq0_status(ch_col[i])) continue;
        dma_channel_acknowledge_irq0(ch_col[i]);
        dma_channel_set_write_addr(ch_col[i], &eng.ring[i * HALF], false);
        dma_channel_set_trans_count(ch_col[i], HALF, false);
        col_halves++;
    }
}

static uint64_t written_total(void) {
    uint32_t h1, h2, remaining;
    do {
        h1 = col_halves;
        remaining = dma_hw->ch[ch_col[h1 & 1u]].transfer_count;
        h2 = col_halves;
    } while (h1 != h2);
    return (uint64_t)h1 * HALF + (HALF - remaining);
}

/* RAM-resident so the interrupts-off tick-to-enable path never waits on XIP. */
static void __not_in_flash_func(start_timers)(void) {
    acq_epoch_start(&epoch);
}

static void acq_hw_stop(void) {
    acq_epoch_stop(&epoch); /* returns only once core1's step IRQ is confirmed off */
    pwm_clear_irq(STEP_SLICE);
    gpio_put(PIN_MUX_DISABLE, true);
    dma_channel_set_irq0_enabled(ch_col[0], false);
    dma_channel_set_irq0_enabled(ch_col[1], false);
    const uint all[4] = {ch_reload, ch_start, ch_col[0], ch_col[1]};
    for (unsigned i = 0; i < 4u; i++) dma_channel_abort(all[i]);
    dma_hw->ints0 = (1u << ch_col[0]) | (1u << ch_col[1]);
}

static void acq_hw_start(void) {
    adc_fifo_drain();
    adc_hw->fcs = adc_hw->fcs | ADC_FCS_OVER_BITS | ADC_FCS_UNDER_BITS; /* write-1-to-clear */

    col_halves = 0;
    for (unsigned i = 0; i < 2u; i++) {
        dma_channel_config c = dma_channel_get_default_config(ch_col[i]);
        channel_config_set_transfer_data_size(&c, DMA_SIZE_16);
        channel_config_set_read_increment(&c, false);
        channel_config_set_write_increment(&c, true);
        channel_config_set_dreq(&c, DREQ_ADC);
        channel_config_set_chain_to(&c, ch_col[i ^ 1u]);
        dma_channel_configure(ch_col[i], &c, &eng.ring[i * HALF], &adc_hw->fifo, HALF, i == 0u);
        dma_channel_acknowledge_irq0(ch_col[i]);
        dma_channel_set_irq0_enabled(ch_col[i], true);
    }

    dma_channel_config rc = dma_channel_get_default_config(ch_reload);
    channel_config_set_transfer_data_size(&rc, DMA_SIZE_32);
    channel_config_set_read_increment(&rc, false);
    channel_config_set_write_increment(&rc, false);
    dma_channel_configure(ch_reload, &rc, &dma_hw->ch[ch_start].al3_read_addr_trig,
                          &cs_table_addr, 1u, false);

    dma_channel_config sc = dma_channel_get_default_config(ch_start);
    channel_config_set_transfer_data_size(&sc, DMA_SIZE_32);
    channel_config_set_read_increment(&sc, true);
    channel_config_set_write_increment(&sc, false);
    channel_config_set_dreq(&sc, pwm_get_dreq(SLOT_SLICE));
    channel_config_set_chain_to(&sc, ch_reload);
    dma_channel_configure(ch_start, &sc, &adc_hw->cs, cs_table, ACQ_SLOTS_PER_FRAME, true);

    pwm_set_counter(SLOT_SLICE, 0u);
    pwm_set_counter(STEP_SLICE, ACQ_SLOT_CYCLES - ACQ_STEP_OFFSET_CYCLES);
    pwm_clear_irq(STEP_SLICE);
    pwm_set_irq_enabled(STEP_SLICE, true);

    /* Slot 0's address is driven and settled before the origin (see stepper_reset). */
    gpio_put_masked(ADDR_MASK, (uint32_t)eng.step.driven_addr << PIN_ADDR0);
    gpio_put(PIN_MUX_DISABLE, false);
    busy_wait_us(10);
    acq_epoch_core1_request(&epoch, true); /* after pwm_clear_irq, so nothing stale pends */
    start_timers();
}

static void acq_hw_init(void) {
    adc_init();
    for (unsigned p = 26; p <= 28; p++) adc_gpio_init(p);
    adc_fifo_setup(true, true, 1, true, false); /* FIFO + DREQ, ERR flag in bit 15 */
    for (unsigned sif = 0; sif < ACQ_SLOTS_PER_FRAME; sif++) {
        acq_slot sl = acq_slot_for(&eng.sched, sif, 0);
        cs_table[sif] = ADC_CS_EN_BITS | ADC_CS_START_ONCE_BITS
                      | ((uint32_t)sl.adc_input << ADC_CS_AINSEL_LSB);
    }
    pwm_config pc = pwm_get_default_config();
    pwm_config_set_clkdiv_int(&pc, 1);
    pwm_config_set_wrap(&pc, ACQ_SLOT_CYCLES - 1u);
    pwm_init(SLOT_SLICE, &pc, false);
    pwm_init(STEP_SLICE, &pc, false);
    ch_start = (uint)dma_claim_unused_channel(true);
    ch_reload = (uint)dma_claim_unused_channel(true);
    ch_col[0] = (uint)dma_claim_unused_channel(true);
    ch_col[1] = (uint)dma_claim_unused_channel(true);
    irq_set_exclusive_handler(DMA_IRQ_0, on_collector_done);
    irq_set_enabled(DMA_IRQ_0, true);
}

/* hold_pressed/link_pressed are the raw (active-low) button pins, not the renderer's
 * latched HOLD/LINK modes that the display shows. */
static void report_line(unsigned line) {
    const acq_counters *c = &eng.cnt;
    if (line == 0u) {
        printf("acq,uptime_ms=%lu,frames=%lu,missed_slots=%lu,overrun_events=%lu,overrun_samples=%lu,"
               "fifo_errors=%lu,conversion_errors=%lu,held_samples=%lu,resyncs=%lu,hold_pressed=%u,link_pressed=%u\n",
               (unsigned long)to_ms_since_boot(get_absolute_time()), (unsigned long)c->frames,
               (unsigned long)c->missed_slots, (unsigned long)c->overrun_events,
               (unsigned long)c->overrun_samples, (unsigned long)c->fifo_errors,
               (unsigned long)c->conversion_errors, (unsigned long)c->held_samples,
               (unsigned long)c->resyncs, (unsigned)!gpio_get(PIN_HOLD_N), (unsigned)!gpio_get(PIN_LINK_N));
        return;
    }
    unsigned ch = line - 1u;
    printf("ch,%u,last_code=%u,time_code=%u,range_code=%u,range=%d,pushed=%lu\n", ch + 1u,
           eng.last_code[ch], eng.time_code[ch], eng.range_code[ch], eng.range[ch].stable,
           (unsigned long)eng.pushed[ch]);
}

int main(void) {
    out(PIN_MUX_DISABLE, true); /* all mux banks disconnected until acquisition starts */
    for (unsigned p = PIN_ADDR0; p < PIN_ADDR0 + 4u; p++) out(p, false);
    lcd_safe_pins_apply(); /* already applied by the runtime-init hook; kept explicit */
    out(PIN_TIMING_TP, false);
    for (unsigned p = PIN_HOLD_N; p <= PIN_LINK_N; p++) { gpio_init(p); gpio_set_dir(p, GPIO_IN); gpio_pull_up(p); }

    bool clock_ok = set_sys_clock_khz(ACQ_SYS_CLK_HZ / 1000u, false);
    stdio_init_all();
    sleep_ms(1500);
    puts("scope10_acq P0 / " LCD_STATE " / UNCALIBRATED / no fault-voltage testing authorized");
    puts("Nominal design: 10000 S/s per channel, 10 channels sampled SEQUENTIALLY (not simultaneous); "
         "rate, settle and jitter NOT measured (G05 OPEN)");
    if (!clock_ok || clock_get_hz(clk_sys) != ACQ_SYS_CLK_HZ) {
        printf("ERROR: clk_sys %lu Hz, engine requires %lu Hz; acquisition not started\n",
               (unsigned long)clock_get_hz(clk_sys), (unsigned long)ACQ_SYS_CLK_HZ);
        for (;;) sleep_ms(1000);
    }

    acq_schedule sched;
    acq_schedule_default(&sched);
    acq_engine_init(&eng, &sched, hist);
    acq_hw_init();
#if SCOPE_ENABLE_LCD
    /* Before acquisition starts: panel reset, init and the full-screen clear block core0 for about 0.4 s. */
    static scope_render_state rs;
    static scope_button hold_btn, link_btn;
    scope_render_init(&rs);
    bool lcd_ok = scope_display_init();
    if (lcd_ok) scope_display_backlight(100);
    printf("lcd,init_sequence_sent=%u (no panel readback exists; not a display verification)\n",
           (unsigned)lcd_ok);
#endif
    multicore_launch_core1(core1_main);
    (void)multicore_fifo_pop_blocking();
    acq_hw_start();

    uint64_t next_report = time_us_64() + REPORT_INTERVAL_US;
    unsigned report = ACQ_CHANNELS + 1u; /* idle */
    for (;;) {
        if (adc_hw->fcs & (ADC_FCS_OVER_BITS | ADC_FCS_UNDER_BITS)) {
            /* A dropped or phantom FIFO word breaks slot alignment: count, restart, resync. */
            eng.cnt.fifo_errors++;
            acq_hw_stop();
            acq_engine_resync(&eng);
            acq_hw_start();
            continue;
        }
        acq_drain(&eng, written_total(), DRAIN_BATCH);
        if (report <= ACQ_CHANNELS) {
            report_line(report++); /* one short line per pass keeps drain latency low */
        } else if (time_us_64() >= next_report) {
            next_report += REPORT_INTERVAL_US;
            report = 0;
        }
#if SCOPE_ENABLE_LCD
        if (lcd_ok) {
            uint32_t now_ms = to_ms_since_boot(get_absolute_time());
            scope_render_input in = {
                .hist = hist,
                .samples_per_s = ACQ_SAMPLES_PER_CH_S,
                .hold = scope_button_update(&hold_btn, !gpio_get(PIN_HOLD_N), now_ms),
                .link = scope_button_update(&link_btn, !gpio_get(PIN_LINK_N), now_ms),
            };
            for (unsigned ch = 0; ch < ACQ_CHANNELS; ch++) {
                in.time_code[ch] = eng.time_code[ch];
                in.range[ch] = (int8_t)eng.range[ch].stable;
                /* No calibration persistence exists (firmware/tools/calibrate.py only writes a
                 * host JSON file), so every channel uses the nominal fallback: shown as UNCAL. */
                in.cal[ch] = scope_calibration_nominal();
            }
            scope_render_step(&rs, &in, RENDER_ITEMS_PER_PASS);
        }
#endif
    }
}

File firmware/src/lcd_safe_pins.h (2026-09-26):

#ifndef LCD_SAFE_PINS_H
#define LCD_SAFE_PINS_H
/* Waveshare Pico-ResTouch-LCD-3.5 control pins on SPI1 (design/gpio.json; the vendor
 * DEV_Config.h uses the same numbers) and the "LCD dark, all slaves deselected" state.
 *
 * GP13 backlight polarity is INVERTED (#41, design/evidence/backlight-interface.md). The
 * module has R16 10k from VSYS (5 V) to LCD_BL, the backlight regulator's EN. The carrier
 * therefore never ties GP13 to LCD_BL: GP13 -> R64 -> gate of Q1 (N-channel MOSFET, open
 * drain on LCD_BL, R88 100k gate pull-down). GP13 HIGH turns Q1 on and pulls LCD_BL to
 * ~0 V: backlight OFF. GP13 LOW or undriven (reset, boot ROM, before this hook) leaves Q1
 * off and R16 pulls LCD_BL to VSYS: backlight ON. The pad only ever sees its own drive or
 * 0 V through R88, so no state exceeds IOVDD + 0.5 V; the early hook exists to darken the
 * panel quickly, not to protect the pin. */
#define LCD_PIN_DC 8u
#define LCD_PIN_CS 9u
#define LCD_PIN_SCK 10u
#define LCD_PIN_MOSI 11u
#define LCD_PIN_BL 13u
#define LCD_PIN_RST 15u
#define LCD_PIN_TP_CS 16u
#define LCD_PIN_SD_CS 22u

/* Active-low backlight through the Q1 open-drain stage. */
#define LCD_BL_LEVEL_OFF true
#define LCD_BL_LEVEL_ON false

/* Backlight OFF (GP13 high), LCD/touch/SD chip selects high, panel held in reset. Glitch-free, idempotent. */
void lcd_safe_pins_apply(void);
#endif

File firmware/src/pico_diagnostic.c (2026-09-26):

/* P0 diagnostic only. NOT the final monitor firmware.
 * LCD is deliberately held dark/unselected until G01/G06 are resolved.
 * Polling is rate-limited and outputs serial readings; it does not claim 10 kS/s/channel.
 * Pico SDK target compilation was not possible in the delivery environment.
 */
#include "pico/stdlib.h"
#include "hardware/adc.h"
#include "scope_core.h"
#include <stdio.h>
#define ADDR_MASK (0x0fu << 2)
static void out(unsigned pin,bool high){gpio_init(pin);gpio_set_dir(pin,GPIO_OUT);gpio_put(pin,high);}
static void select_channel(unsigned n){
    gpio_put(7,1); gpio_put_masked(ADDR_MASK,(n&15u)<<2); sleep_us(2); gpio_put(7,0); sleep_us(10);
}
static uint16_t sample(unsigned adc_channel){
    adc_select_input(adc_channel); (void)adc_read(); sleep_us(2); return adc_read();
}
int main(void){
    out(7,true); /* disable all muxes before changing addresses */
    for(unsigned p=2;p<=5;p++)out(p,false);
    out(9,true);out(16,true);out(22,true);out(13,false);out(15,false);out(14,false);
    for(unsigned p=0;p<=1;p++){gpio_init(p);gpio_set_dir(p,GPIO_IN);gpio_pull_up(p);}
    stdio_init_all(); adc_init(); for(unsigned p=26;p<=28;p++)adc_gpio_init(p);
    sleep_ms(1500);
    puts("P0 DIAGNOSTIC ONLY / LCD OFF / UNCALIBRATED / no fault-voltage testing authorized");
    puts("elapsed_us,channel,signal_code,time_code,range_code,hold_pressed,link_pressed");
    for(;;){
        for(unsigned n=0;n<10;n++){
            select_channel(n); gpio_put(14,true);
            uint16_t sig=sample(0),tim=sample(1),rng=sample(2);
            gpio_put(14,false);gpio_put(7,true);
            printf("%llu,%u,%u,%u,%u,%u,%u\n",(unsigned long long)time_us_64(),n+1,sig,tim,rng,!gpio_get(0),!gpio_get(1));
            sleep_ms(10);
        }
    }
}

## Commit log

2026-09-26 Import zudo-scope10 P0 pre-layout handoff package as delivered
    Unmodified contents of the Codex-generated P0 handoff zip (SHA256SUMS.txt
    verifies). No design changes.
    Claude-Session: https://claude.ai/code/session_018oLpisCWqu84U1dDpzLDZ4
    [NOMINAL-ENVELOPES-NOT-FIT-CAD.step, NOMINAL-ENVELOPES-NOT-FIT-CAD.stl, RK09L1140-F15.STEP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]
2026-09-26 Make validate.py regeneration deterministic; add validate_extra hook and base CI
    - scripts/build_docs.py: replace the optional markdown-it-py renderer with a
    small stdlib Markdown renderer (headings, fenced code, pipe tables, lists,
    inline bold/code/links). Offline HTML is now byte-identical regardless of
    what is installed. Regenerate offline/*.html once with the canonical
    renderer.
    - scripts/validate.py: sort every glob/rglob/path list that feeds the
    validation report (native KiCad file discovery, HTML link scan, the
    regeneration byte-comparison paths) so report/check order no longer
    depends on filesystem enumeration order.
    - scripts/validate_extra.py: new extension hook, invo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
    [build_docs.py, validate.py, validate_extra.py]
2026-09-26 Fix KiCad 9 loading of root sheet and PCB; add native netlist parity check
    Raw newlines inside quoted strings made kicad-cli refuse the root
    schematic and the outline PCB. The generator now emits \n escapes.
    scripts/kicad_check.py runs ERC on the full hierarchy, exports the
    netlist and compares refs, named nets and every pin->net mapping with
    design/circuit.json (224 instances, 134 nets, 0 differences), writing
    reports/kicad-check.json. validate_extra runs parity when kicad-cli is
    present; kicad.yml installs KiCad 9 from the PPA in CI.
    Refs #4
    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
    [zudo-scope10-p0.kicad_pcb, zudo-scope10-p0.kicad_sch]
2026-09-26 Add ngspice run of input-channel netlist, reconcile with analyze.py (#7)
    scripts/run_spice.py drives ngspice -b on the same ideal-buffer
    simulation/input-channel.cir analyze.py models analytically (DC endpoints
    via alter + AC sweep reusing the netlist's own ac line), then compares
    gain, zero and the two-pole cascade's -3 dB corner against
    reports/analog-analysis.json. All three land within 0.06% here; the
    per-pole vs cascade-corner distinction is spelled out in the comparison's
    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
2026-09-26 Add G01 desk evidence for Waveshare display power path and straps
    Reads the Pico-ResTouch-LCD-3.5 schematic page images: 5 V enters on VSYS
    (pos 39) with no diode, module 3V3 comes from its own RT9193-33, and the
    carrier's isolation of pos 35/36/37/40 and open pos 4/7/19 avoid every
    strap-dependent conflict. Delta proposes no net edits; G01 stays OPEN.
    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
2026-09-26 Build diagnostic firmware against the real Pico SDK
    Add scripts/build_firmware.sh, which clones pico-sdk 2.1.1 (pinned to
    commit bddd20f) into the gitignored reference/downloads/ cache unless
    PICO_SDK_PATH is already set, initialises the tinyusb submodule, and
    builds firmware/ with CMake+Ninja. Picotool is satisfied via
    PICOTOOL_FETCH_FROM_GIT_PATH so CMake's FetchContent builds it once
    into the same cache, avoiding a libusb-1.0-dev dependency.
    Enable -Wall -Wextra on the diagnostic target (0 warnings) and write
    reports/firmware-target-build.json with the SDK tag/sha, toolchain
    version, and UF2 size/sha256. Add .github/workflows/firmware.yml to
    build and upload the UF2 and report as workflo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
2026-09-26 G09: add 1:1 printable panel review sheet
    Adds scripts/make_panel_print.py, generating
    mechanical/print/panel-1to1.svg (+.pdf via rsvg-convert) from
    mechanical/panel-layout-study.json and mechanical/envelope-study.scad:
    panel outline, control envelopes, LCD module/active-area rectangles,
    100mm/50mm scale-check rulers and an ID-1 credit-card reference box,
    plus the required print/review-only labels. HOLD/LINK marker positions
    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
2026-09-26 Clean KiCad 9 root-hierarchy ERC in the generator; add outline DRC to kicad_check
    - make_design.py: place symbols, wires, labels and no-connects on the 1.27 mm grid
    (endpoint_off_grid 872 -> 0); add PWR_FLAG on +5V_FUSED and GND, which are fed
    only from off-board USB through passive Pico socket contacts and fuse F1
    (power_pin_not_driven 2 -> 0); generate 74HC4067 Y/Z as passive analog-switch
    terminals instead of bidirectional.
    - kicad_check.py: every remaining ERC item needs a reason, endpoint_off_grid and
    lib_symbol_* must be 0, outline-board DRC error count recorded and gated.
    - validate.py: exclude '#' power/flag symbols from the physical instance inventory.
    Refs #11
    Co-Author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
    [acquisition.kicad_sch, controls-left.kicad_sch, controls-right.kicad_sch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]
2026-09-26 G08 evidence: sourcing candidates for specification-only BOM rows (#9)
    Fetch-verified LCSC/JLCPCB candidates for the 0603/0805 R/C rows, the
    1206 PPTC fuse and REF3330AIDBZR; rechecked the six known listings
    (confirms SS14MDP2/C6684954 still at zero stock). r249k, socket20 and
    header20 stay OPEN with a stated fetch/search-coverage reason. No
    C-number is recorded without a fetched source page; every entry carries
    listing_not_allocation: true. Evidence-only — catalog, BOM and generator
    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
2026-09-26 G02: desk evidence for range switch, jack, button and module pin/mechanical maps
    Adds design/evidence/g02-mechanical-pins.md and g02-delta.json (evidence only;
    catalog/generator/footprints untouched). NKK SS14MDP2 numeric map (COM=3,
    throws 1/2/4) from the NKK SS catalogue; TS-1088 footprint verified against
    the XUNPU drawing; Waveshare outline/sockets/active area/heights from the
    vendor STEP; Pico H positions from the Pico datasheet. PJ-313 leg-to-node
    map, Waveshare drill size, Pico H header height and 1x20 orderables stay OPEN.
    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
2026-09-26 G02 evidence: record NKK terminal-length conflict and unstated jack hole plating
    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
2026-09-26 G07: cited datasheet power/USB budget calculation
    Adds scripts/power_budget.py (invoked from analyze.py) computing
    datasheet-cited quiescent-current totals for the +3V3A analog rail
    (6x TLV9064, 3x 74HC4067, REF3330AIDBZR), TLV75533 LDO dissipation,
    a USB 2.0 default-port budget check against the existing 420 mA
    design allowance, and an inrush-capacitance check against the
    carrier-side capacitor recorded in design/circuit.json. Every figure
    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
2026-09-26 Harden capacitor-record match in power_budget.py
    Require a digit right after the 'c' prefix so record 'clamp' (BAV199
    diode) can never match the capacitor-net summation, even though it
    was already harmless in practice (its value string doesn't parse as
    a capacitance).
    [power_budget.py]
2026-09-26 Add 10 kS/s/channel sequential acquisition engine (scope10_acq)
    Portable scheduler/ring/missed-slot logic in acq_engine.[ch], RP2040
    PWM-paced DMA ADC starts + core1 mux-step IRQ in acq_rp2040.c, a
    cycle-level host model in tests/test_acq.c wired into test_firmware.py,
    and the budget + G05 bench procedure in firmware/ACQUISITION.md.
    build_firmware.sh now builds and reports each target. G05 stays OPEN;
    no rate is claimed as measured.
    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
    [acq_engine.c, acq_engine.h, acq_rp2040.c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]
2026-09-26 Generator integrator: apply G01/G02/G08 evidence deltas, candidate footprints (#13)
    Applies the cited deltas from #3 (g01-delta.json), #6 (g02-delta.json) and #9
    (g08-delta.json) to scripts/make_design.py and catalog/*.json, the only topic
    allowed to touch those files.
    - G01: record the display-header notes and the R16/R88 backlight default-on
    conflict as a pending_g01_changes proposal only; J30/J31 nets are unchanged,
    per the G01 header-net rule. Documented in the power narrative source too.
    - G02: apply the NKK range-switch numeric terminal map (C->3, M->2 vendor
    facts; L->1/H->4 marked OPEN pending panel orientation) and add the
    resolved mechanical facts/open-questions for range,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
    [bom-planning.csv, connections.csv, controls-left.kicad_sch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]
2026-09-26 Add clean-room Waveshare LCD backend and ten-pane renderer (#14)
    - lcd_bridge.[ch]: portable framing for the module's SPI->16-bit bridge
    (derived from the module schematic), ILI9488 init table (RGB565, COLMOD
    0x55, portrait), address window, clipping, blit/fill.
    - display_waveshare.c: RP2040 SPI1 bus behind display_port.h; #error unless
    SCOPE_ENABLE_LCD=1. CMake option SCOPE_ENABLE_LCD (default OFF) extends
    scope10_acq; build_firmware.sh builds both flag states.
    - lcd_safe_pins.[ch]: GP13 LCD_BL driven low (module R16 pull-up to VSYS)
    from a runtime-init hook right after early resets, in both flag states.
    - scope_render.[ch]: ten portrait panes from scope_core history via small
    r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
    [acq_rp2040.c, display_waveshare.c, lcd_safe_pins.c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]
2026-09-26 Native zudo-doc build + HTTP browser smoke (#15)
    - doc/: add missing preact-render-to-string dep so `pnpm build` (zfb
    bundler) succeeds; commit doc/pnpm-lock.yaml. Fix .gitignore to match
    the real build-cache dirs (doc/.zfb-build, doc/.zudo-doc).
    - Add .github/workflows/docs.yml (Node 22 + pnpm, pnpm build), actionlint
    clean.
    - Extend scripts/browser_smoke.py with an HTTP mode: serves the repo via
    scripts/serve.py on a free port (flock under
    /tmp/x-wt-teams-zudo-scope10-locks/), navigates real Chromium to the
    offline catalogue, the ten-pane UI simulator, the standalone GLB viewer
    (with swiftshader GL args so headless Chromium actually renders WebGL),
    and the built doc/dist si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
    [browser_smoke.py, validate_extra.py]
2026-09-26 Confirm: re-run all checks, roll up evidence, write LOCAL-HANDOFF.md (#16)
    Re-ran validate.py, test_firmware.py, analyze.py, kicad_check.py,
    build_firmware.sh (both LCD flags), run_spice.py, make_panel_print.py, the
    zudo-doc native build and the HTTP browser smoke on the merged base (#2-#15).
    Everything passes; native KiCad load, target firmware builds and the native
    docs+browser-smoke pipeline all run clean in this container for the first
    time.
    Regenerated reports/validation.json and SHA256SUMS.txt exactly once (via
    scripts/package.py, after excluding gitignored vendor/build caches that its
    filter doesn't already catch). sha256sum -c SHA256SUMS.txt passes.
    Gave every gate in design/releas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
2026-09-26 Make ngspice validate check fail on out-of-tolerance mismatch
    The check passed whenever run_spice wrote its (always non-empty)
    explanation, so a >2% drift would still report PASS.
    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
    [validate_extra.py]
2026-09-26 Install KiCad symbol/footprint libraries in kicad CI job
    Candidate footprints assigned from standard KiCad libraries raise 191
    footprint_link_issues when kicad-footprints is absent (--no-install-recommends).
    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
2026-09-26 Fix acceptance CSV column shift and add worksheet check (#32)
    manufacturing/acceptance-results.csv had 10 fields per row against a
    9-column header, so NOT_RUN landed in evidence_file and result was
    blank. Rewrite each row to the header width with result=NOT_RUN and
    an empty evidence_file, keeping the 10 test IDs and their order.
    Add scripts/validate_extra.py::_acceptance_csv to check row width
    (no None/unnamed field from csv.DictReader), that result is one of
    NOT_RUN/PASS/FAIL/BLOCKED, that any PASS/FAIL row cites an existing
    evidence_file plus operator and date, and that every row is still
    NOT_RUN since no physical measurement has been performed. Document
    the allowed result set in LOCAL-HA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
    [acceptance-results.csv]
2026-09-26 Fix CRLF line endings in acceptance-results.csv
    The previous commit's csv.writer rewrite introduced CRLF line
    terminators; restore the file's original LF convention so the diff
    is content-only.
    Claude-Session: https://claude.ai/code/session_01LdS1Qx9bfutgm3zefcJLar
    [acceptance-results.csv]
2026-09-26 Reconcile module-power evidence and size F1 from its own branch (#35)
    Add design/evidence/module-power.json as one structured module-power
    evidence source (verified-schematic / allowance / unknown / rejected
    per claim, with citation and uncertainty), and make power_budget.py,
    g01-display-power.md, narrative-pages.json, release-gates.json and
    LOCAL-HANDOFF.md consume it instead of hard-coded/contradictory prose:
    - Capacitance: report the verified 11.2 uF module + 1 uF carrier =
    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
2026-09-26 Make validation non-destructive with explicit KiCad init and phase-aware checks
    scripts/validate.py no longer regenerates make_design.py/analyze.py/build_docs.py
    inside the working checkout: it copies the repo into a throwaway temp dir
    (excluding .git/node_modules/dist/__pycache__), regenerates there, and compares
    against the checkout with a unified diff on mismatch. Neither a passing nor a
    failing run can mutate the checkout, apart from reports/validation.json.
    scripts/make_design.py only (re)writes hardware/kicad/zudo-scope10-p0.kicad_pro
    and .kicad_pcb when they are missing, or when --init-kicad is passed; an
    ordinary run now leaves developer placement/routing/project settings alone.
    de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
    [make_design.py, test_validate_nondestructive.py, validate.py]
2026-09-26 Record RANGE switch (NKK SS14MDP2) contact-suitability qualification (#38)
    Per #27's decided option 2: keep SS14MDP2, no substitute MPN invented.
    Records the switch's silver contact finish and NKK's own dry-circuit
    guidance (page Z33 / operating-range) as cited evidence in
    catalog/sources.json, documents the actual near-zero steady/transient
    contact load from the real sense circuit (switch -> 1k -> 100nF ->
    mux), and sets catalog/components.json's range record to
    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
    [acceptance-results.csv]
2026-09-26 Render per-pane text labels: channel ID, range, duration, HOLD/LINK (#36)
    Adds a clean-room 5x7 bitmap font (const table in scope_render.c) and
    draws text through scope_display_rect in 6x10 cells, two cells (120 px)
    per call, with no framebuffer. Each pane's label row shows the channel
    ID in the channel colour, the range (+-3V/+-5V/+-8V, +-?V when unknown)
    and the window duration from scope_render_window_label(); the status
    row replaces the interim RANGE boxes, TIME bar and LINK/HOLD boxes with
    a UNCAL/CLIP/SAT token slot (scope_render_input.status_token) and
    LINK/HOLD text shown while latched. Each text field is one render item
    and is redrawn only when its string or colour changes. HOLD now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
    [test_lcd.c]
2026-09-26 fix(firmware): make acquisition origin capture, epoch publication and PWM start atomic
    start_timers() captured the TIMER origin tick, enabled PWM and only then published
    the epoch, all with core0 interrupts enabled. A core0 interrupt before the enable made
    the software origin earlier than the physical one (host model: 2160/2400 wrong-address
    samples accepted with zero missed slots); one after the enable let core1 step on an
    unpublished epoch. Resync relied on a fixed 20 us delay for core1 quiescence.
    - New portable acq_epoch.h (hook macros; target and host model run the same code):
    interrupts-off, RAM-resident start that writes the epoch, DMB, arms a generation,
    then enables PWM; step I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
    [acq_engine.h, acq_rp2040.c, test_acq.c]
2026-09-26 Harden release_guard.py: exit-code contract, schema validation, evidence paths (#39)
    release_guard.py now has a defined 0/2/3 exit-code contract (structurally
    complete+resolvable evidence / intentional REFUSED / malformed manifest),
    validated as testable functions instead of ad-hoc truthiness checks. It
    requires a real JSON boolean for release_allowed, validates the exact
    G01-G10 gate id set (unique, no missing/unknown), type-checks
    evidence_files/evidence_urls, and rejects local evidence paths that are
    missing, a directory, or escape the repo root. evidence_urls is a typed
    external-reference field that can never alone close a gate; evidence_partial
    stays informational. A seam is documented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
    [test_release_guard.py, validate.py]
2026-09-26 Render the requested TIME window independent of storage level (#40)
    scope_window_map() picks the smallest history level covering the window,
    takes the newest ceil((W - lag) / 2^L) bins, and maps them onto the plot
    columns (min/max merge or stretch). Each edge of the represented interval
    is within one coarse bin of the request; partial history is right-aligned
    with blank columns on the left. The duration label formats the same window
    samples, so label and plot agree. Tests cover both #21 reproductions,
    endpoint/intermediate tolerance, no dead zone, label agreement and LINK.
    Claude-Session: https://claude.ai/code/session_01LdS1Qx9bfutgm3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
    [test_lcd.c]
2026-09-26 Add explicit USB power source contract with honest declared-descriptor budget check (#37)
    Adds design/power-contract.json as the single shared source for the
    supported-source contract (>=500 mA at 5 V from attach, not established
    by enumeration or VBUS presence), the declared USB descriptor value,
    and the per-state power behaviour table (pre-configuration, configured,
    suspend/deconfigured, reset, BOOTSEL/ROM, unpowered).
    Verified against the pinned Pico SDK 2.1.1 source directly
    (raw.githubusercontent.com) that stdio_usb_descriptors.c's
    USBD_MAX_POWER_MA is NOT #ifndef-guarded and is compiled inside the
    separate pico_stdio_usb library, so a target-level compile definition
    cannot reliably ov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
    [power_budget.py, validate_extra.py]
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2026-09-26 Map waveform through calibration and +-3/5/8 V range (#42)
    The renderer converted raw codes straight to full plot height with a fixed
    2048 grid, so RANGE never changed the plot. Each column's raw lo/hi now goes
    through the channel's scope_calibration to volts, and [-range, +range] maps
    symmetrically onto rows 0..64 with electrical zero (0 V) as the grid row.
    - scope_render_input.cal[]: missing/invalid calibration falls back to
    scope_calibration_nominal() (zero code 1858.378, 8.069583 mV/code from
    reports/analog-analysis.json, calibrated=false) and shows UNCAL in its own
    label-row slot. acq_rp2040.c passes the nominal fallback (no persistence
    exists); no startup auto-zeroing.
    - Signa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
    [acq_rp2040.c, test_lcd.c, validate_extra.py]
2026-09-26 Replace the GP13-LCD_BL tie with an open-drain MOSFET backlight stage (#41)
    Module R16 (10k) pulls LCD_BL / CAT1 EN to VSYS (~5 V), so the old carrier
    wiring (GP13 -> R64 -> LCD_BL, R88 100k to GND) put an undriven GP13 near
    4.5 V, above the RP2040 IOVDD + 0.5 V absolute maximum. Neither removing R88
    nor accepting an undocumented clamp current meets the pin limits (#19).
    Circuit (scripts/make_design.py + catalog/components.json, regenerated
    sheets/netlist/BOM/connections/circuit.json):
    - new generic record `nmos-ll` (logic-level N-channel MOSFET; no MPN, no
    LCSC code, footprint unassigned, exact part at G08)
    - R64 now feeds net LCD_BL_GATE -> Q1 gate; R88 is the gate pull-down;
    Q1 drain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
    [acceptance-results.csv, bom-planning.csv, connections.csv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]
2026-09-26 Document that scope10_diagnostic never drives GP13 (backlight stays ON) (#41)
    Self-review finding: only scope10_acq links lcd_safe_pins.c, so the
    "LCD-off build turns the backlight off" statement applied to that target
    alone. LCD-BACKEND.md, power-contract.json (configured state) and
    backlight-interface.md now say so explicitly; the pad is unaffected
    (gate held at 0 V through R88).
    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
2026-09-26 Separate engineering-prototype and production approval routes (#43/#24)
    manufacturing/release_guard.py gains --route {production,prototype}
    (default production, unchanged #39 behavior). The prototype route is a
    new, independent decision under design/release-gates.json's
    decisions.prototype: a fixed list of standalone prerequisites (each with
    its own resolvable evidence_files) plus an explicit, never-auto-filled
    human approval record (approver/date/revision). It never reads or
    requires any G01-G10 gate's CLOSED status, since #24 found that
    G01/G02/G03/G08's full closure needs bench work on the very prototype
    this route would authorize -- reusing gate status would keep the same
    cycle. Producti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
    [test_release_guard.py, validate.py]
2026-09-26 Fix missing blank lines between validate_extra.py check functions
    Self-review of the #44 renderer-capture commit: restore the file's two-blank-line
    spacing between top-level defs (PEP 8, matches the rest of the file) after
    appending _check_renderer_capture.
    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
    [validate_extra.py]
2026-09-26 Regenerate validation and firmware-host-tests reports for #45 confirm pass
    Reran validate.py and test_firmware.py against the fully merged
    base/p0-review-fixes tree (#31-#44) and committed the refreshed
    reports/validation.json and reports/firmware-host-tests.json so the
    checked-in evidence matches the current checks (127 structural checks,
    225 instances, 135 nets; acq startup-race and TIME-window regression
    suites now included).
    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
2026-09-26 Review fixes: freeze window label under HOLD; CLI errors exit 3
    - scope_render: the duration label uses the TIME code/LINK state latched
    with the frozen plot, so HOLD no longer relabels a frozen trace.
    - release_guard: argparse errors print MALFORMED and exit 3, keeping
    exit 2 reserved for a deliberate refusal.
    - Regenerate renderer capture, panel print SVG and SHA256SUMS entries.
    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
    [test_lcd.c, test_release_guard.py]
